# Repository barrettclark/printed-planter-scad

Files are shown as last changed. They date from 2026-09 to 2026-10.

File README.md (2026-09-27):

# Parametric Planter Generator

## What This Is

This is a parametric OpenSCAD model that generates a decorative outer planter body/shell fitted around a plastic insert (pot, container, or vessel) you already have. You provide measurements of your insert and the generator creates a body that holds it securely, with optional decorative patterns. All dimensions are parametric—adjust them to fit any insert size, wall thickness, or decoration style.

## Requirements

- **OpenSCAD 2021.01 or later** — required by the vendored BOSL2 library (which hard-asserts this minimum version), the Customizer feature, and procedural language features used here.
- **BOSL2 library** — vendored in `lib/BOSL2/`, no separate installation needed.
- **Customizer panel recommended** — the easiest way to adjust parameters. Enable it with **View → Show Customizer** in OpenSCAD.

Command-line users can override any parameter without the Customizer by using the `-D` flag, for example:
```bash
openscad -D 'insert_top_d=160' -D 'pattern_type="hex_grid"' -o exports/planter.stl planter.scad
```

An `exports/` directory is included for rendered output (STL, 3MF, PNG, etc.) — `.gitignore` already excludes those file types repo-wide, so anything you save there stays local and won't get committed. (The one carve-out is `docs/images/`, whose PNGs are documentation rather than disposable output — regenerate them with `docs/images/render.sh`.)

## Measuring Your Insert

Before measuring, check whether your insert is close to one of the 3 named sizes in `insert_preset` (see the Insert Dimensions table below) — if so, just pick that preset and skip measuring entirely.

Otherwise, to generate a planter for a different insert, measure these three dimensions:

- **`insert_top_d`** — the widest point of your insert (the rim or top diameter), in millimeters.
- **`insert_bottom_d`** — the bottom diameter of your insert, in millimeters.
- **`insert_height`** — the vertical height of your insert, in millimeters.

With `insert_preset` left at `"custom"`, these three measurements are the **only parameters you need to change** to reprint the planter for a different insert. The generator will automatically adjust the cavity (internal pocket) to fit your insert's tapered shape. All other parameters control fit clearance, wall thickness, decoration, and base options—leave them at their defaults unless you need to customize further.

## Parameter Reference

All parameters below can be adjusted in the Customizer panel or via command-line `-D` overrides.

### Insert Dimensions

| Parameter | Description | Default |
|---|---|---|
| `insert_preset` | Named insert size: `"custom"` (use the three fields below) or `"small"`, `"medium"`, `"large"` | `"custom"` |
| `insert_top_d` | Top rim diameter (mm) — used when `insert_preset == "custom"` | 150 |
| `insert_bottom_d` | Bottom diameter (mm) — used when `insert_preset == "custom"` | 110 |
| `insert_height` | Insert height (mm) — used when `insert_preset == "custom"` | 130 |

The 3 named presets:

| `insert_preset` | `insert_top_d` | `insert_bottom_d` | `insert_height` |
|---|---|---|---|
| `"small"` | 100 | 75 | 85 |
| `"medium"` | 130 | 100 | 120 |
| `"large"` | 180 | 125 | 160 |

### Fit

| Parameter | Description | Default |
|---|---|---|
| `ledge_engagement_height` | Depth of the rim's tight-fit seat (mm) | 8 |
| `ledge_ramp_height` | Height over which the seat narrows to its tight clearance, instead of as a hard step (mm); `0` reproduces the old hard step | 2 |
| `fit_clearance` | Radial clearance at the rim seat (mm) | 0.3 |
| `body_clearance` | Radial clearance around the tapered insert body (mm) | 3 |
| `bottom_margin` | Air gap below the insert's bottom (mm) | 5 |

### Outer Shape

| Parameter | Description | Default |
|---|---|---|
| `outer_mode` | Shape mode: `"follow"` (auto-wrap around insert) or `"custom"` (fixed geometry) | `"follow"` |
| `wall_thickness` | Wall thickness in `"follow"` mode (mm) | 3 |
| `outer_top_d` | Outer top diameter in `"custom"` mode (mm) | 172 |
| `outer_bottom_d` | Outer bottom diameter in `"custom"` mode (mm) | 130 |
| `outer_height` | Planter height in `"custom"` mode (mm) | 145 |

### Decoration

| Parameter | Description | Default |
|---|---|---|
| `pattern_type` | Decoration style: `"none"`, `"ridges"`, or a geometric tile pattern — `"diamonds"`, `"hex_grid"`, `"pyramids"`, `"bricks"`, `"checkers"`, `"dots"`, `"cubes"`, `"tri_grid"`, `"teardrop"`, `"tumbling_cubes"`, `"intertwine"`, `"islamic_star"`, `"tetrakis_square"`, `"kisrhombille"`, `"triakis_triangular"`, `"rhombille"`, `"cairo_pentagonal"`, `"floret_pentagonal"`, `"deltoidal_trihexagonal"` | `"ridges"` |
| `pattern_orientation` | Direction: `"vertical"` or `"horizontal"` | `"vertical"` |
| `relief_mode` | Relief type: `"raised"` (pattern stands proud of the wall) or `"etched"` (pattern is cut into the wall) | `"raised"` |
| `pattern_depth` | Depth of pattern relief (mm) | 1.5 |
| `pattern_repeat` | Number of pattern tiles around the circumference; the vertical repeat count is derived automatically from the pot's geometry so tiles come out approximately square (see "Decoration" below) | 16 |

### Base

| Parameter | Description | Default |
|---|---|---|
| `floor_thickness` | Thickness of the planter's solid floor (mm) | 3 |
| `drainage_holes_enabled` | Enable drainage holes in the floor | `false` |
| `drainage_hole_count` | Number of drainage holes | 6 |
| `drainage_hole_diameter` | Diameter of each drainage hole (mm) | 4 |

In `"custom"` outer mode, the actual floor thickness is `floor_thickness + (outer_height - pot_height)`, not just `floor_thickness` — the cavity is shifted up to sit flush with the custom outer shape's top, so any extra height in `outer_height` beyond the required cavity height becomes additional solid floor.

### Quality

| Parameter | Description | Default |
|---|---|---|
| `smoothness` | Mesh resolution for all revolved geometry (OpenSCAD `$fn`) | 60 |

## Reference Settings: This Project's Insert

The planter was designed around this insert. Use these settings to reproduce the exact geometry from this project:

```scad
insert_preset = "custom";
insert_top_d = 150;
insert_bottom_d = 110;
insert_height = 130;
ledge_engagement_height = 8;
ledge_ramp_height = 2;
fit_clearance = 0.3;
body_clearance = 3;
bottom_margin = 5;
outer_mode = "follow";
wall_thickness = 3;
pattern_type = "ridges";
pattern_orientation = "vertical";
relief_mode = "raised";
pattern_depth = 1.5;
pattern_repeat = 16;
floor_thickness = 3;
drainage_holes_enabled = false;
```

## Decoration Examples

**See the [pattern gallery](docs/gallery.md) for a rendered example of every `pattern_type` in `"raised"` and `"etched"` mode, plus `"alternating"` for the eight patterns that support it** (except `"none"`, which has no texture, so it only has one useful mode), plus full-pot renders, the three insert presets and both outer shape modes. The rest of this section covers the behaviour the pictures can't show.

`"etched"` works one of two ways depending on the pattern. `"ridges"`, `"pyramids"` and `"diamonds"` have a flat-topped counterpart shape, so etching them is a true line engrave: the wall keeps its nominal surface as flat panels, and only a thin V-groove is cut along each of the pattern's outlines. `"hex_grid"` and `"tri_grid"` work the same way, just shifting the same panel/groove relief inward rather than swapping to a separate counterpart shape.

- `"ridges"` — a smooth wall scored with thin vertical (or horizontal) lines.
- `"pyramids"` — flat square panels divided by a thin engraved grid.
- `"diamonds"` — flat diamond panels divided by thin 45° engraved lines.

Eight patterns — `"tumbling_cubes"`, `"islamic_star"`, `"tetrakis_square"`, `"kisrhombille"`, `"triakis_triangular"`, `"rhombille"`, `"cairo_pentagonal"` and `"floret_pentagonal"` — use a different, uniform mechanism: a flat wall cut by a real two-tier engraved groove. A primary groove traces each motif's own outer silhouette (where it meets a *different* motif instance — e.g. the line between two adjacent Cairo pentagons, or between `"islamic_star"`'s star and a neighbouring cross); a thinner, shallower secondary groove marks internal facet structure within one motif, where a pattern has any (the "kis" family's fan triangles, `"floret_pentagonal"`'s rosette blades, `"tumbling_cubes"`'/`"rhombille"`'s per-rhombus seams, `"cairo_pentagonal"`'s per-hub pinwheel seams). A pattern whose motif has no internal sub-structure of its own within one tile (`"tetrakis_square"`'s single fan spans the whole unit tile, with no second motif instance inside it to have an outer boundary against) legitimately shows only the secondary tier, or only the primary tier — whichever tier has nothing to groove is simply absent, not a bug. See the [gallery](docs/gallery.md#pattern-comparison) for what each looks like.

`"none"` has no texture at all, so it only has one useful mode. `"teardrop"` and `"intertwine"` keep their own pre-existing etched behaviour — a whole-silhouette groove around each's own single pre-built island, predating and unaffected by the two-tier redesign above — see the note on those two patterns below. `"dots"`, `"cubes"`, `"checkers"` and `"bricks"` still sink the raised bump into a dimple, unchanged; converting them to the two-tier groove mechanism above is a deferred future project (see `TODO.md`).

`"alternating"` (new) is a third relief style: within one tile, some copies of a motif sit proud of the nominal wall surface and others sit sunk below it, in a single render — true bas-relief, not a raised or etched pass unioned with its own inverse. It's available for the same eight patterns as the two-tier etched groove above; every other `pattern_type` fails loudly with a clear message (`relief_mode "alternating" is only supported for pattern_type in ...`) rather than falling back to `"raised"` if you select it.

Eight of the `pattern_type` values — `"teardrop"`, `"tumbling_cubes"`, `"intertwine"`, `"islamic_star"`, `"rhombille"`, `"cairo_pentagonal"`, `"floret_pentagonal"` and `"deltoidal_trihexagonal"` — are *interlocking* patterns: their motifs deliberately cross the tile boundary so that adjacent repeats join into one continuous design rather than sitting in visible boxes. The [gallery](docs/gallery.md#pattern-comparison) shows what each one looks like; the notes below cover their rendering quirks.

Note on `"teardrop"` and `"intertwine"`: their `"etched"` behaviour predates the relief-mode redesign above and is unaffected by it — both tiles cross the tile boundary in a way that leaves a decorated body with scalloped rather than circular end caps. The planter itself renders fine, but OpenSCAD 2021.01 aborts with a CGAL assertion if you `union()` such a solid with another *textured* solid. Render these pots on their own, or combine them with plain (untextured) geometry — keep a `"teardrop"` or `"intertwine"` solid as the only textured solid per render when forcing CGAL evaluation. `"tumbling_cubes"` and `"islamic_star"` cross their tile edges too but still union cleanly with another textured solid in `"raised"` mode at CI's own pinned configuration (union with a `"dots"` solid, differenced against a disjoint cube, `pattern_repeat=9`) — both re-measured clean, which is why they stay in CI's union loop. That result is specific to `"raised"` and to those heights, though, and does not generalise: what actually decides it is whether neighbouring plateaus sit at *different* heights. `"tumbling_cubes"` passes on the strength of its three distinct `_TC_Z` values — merely permuting them to `[0.62, 1.0, 0.30]` aborts the union — and any configuration that flattens neighbouring plateaus to one uniform height aborts at every `pattern_repeat` and `smoothness` tried (8, 11 and 12 at `$fn` 4 and 8): that covers `"rhombille"` in `"raised"` mode and *both* patterns in `"alternating"` mode. It is the union operation itself, not proximity — two copies 1000 units apart abort just the same, while each solid alone is a clean 2-volume manifold — and a three-way union of one pattern's own three relief modes aborts for `"islamic_star"` too. So: keep any `"alternating"` solid, and any `"rhombille"` solid, the only textured solid per render, and don't put all three relief modes of one pattern in a single file. `"rhombille"` was already flagged here from a single `pattern_repeat=16` `"raised"` measurement; the above is the fuller characterization that note asked for. `"cairo_pentagonal"` behaves the same way: it CGAL-aborted that same union check (union with a `"dots"` solid, differenced against a disjoint cube) at `pattern_repeat=9` in `"raised"` mode locally, so it is *not* in CI's union loop and gets the same advice — one textured solid per render. `"floret_pentagonal"` is the same: that union check CGAL-aborted locally at `pattern_repeat=26` in `"raised"` mode (a value that renders perfectly cleanly on its own at the same geometry), so it is not in CI's union loop either — keep it the only textured solid per render. `"deltoidal_trihexagonal"` unions cleanly, like `"tumbling_cubes"`/`"islamic_star"`: verified directly (union with a `"dots"` solid, differenced against a disjoint cube) at both `pattern_repeat=9` and `pattern_repeat=12` in `"raised"` mode, so it is in CI's union loop alongside them.

Note on the interlocking patterns and CGAL: `"tumbling_cubes"`, `"intertwine"`, `"islamic_star"`, `"rhombille"`, `"cairo_pentagonal"` and `"floret_pentagonal"` build their motifs from flat plateaus, and BOSL2 lays a single *flat* facet across each one. When a plateau spans a wide arc, that flat facet is a chord that cuts back inside the wall. OpenSCAD 2021.01's CGAL then aborts the cavity subtraction with an assertion or reports an unclosed mesh.

Which parameter values trip this depends on `pattern_repeat` **and** `smoothness` *jointly*, and is not predictable from either one alone — and it moves whenever the underlying tile geometry changes: deriving the vertical tile count from real geometry instead of reusing `pattern_repeat` for both axes (so tiles come out roughly square) shifted every fragile threshold below. It is not a low-`pattern_repeat` problem and not a simple threshold in either parameter, and — this is the part worth stating explicitly, because it is easy to assume otherwise — "clean" for one relief mode does not imply clean for the other: measured on the default pot at `smoothness=24`, `"tumbling_cubes"` aborts (in `"raised"`, at least) at every `pattern_repeat` from 3 through 8 and again at 11; of the values that are clean in `"raised"` (9, 10, 12), `pattern_repeat=12` aborts in `"etched"`, leaving only 9 and 10 clean in **both** relief modes, so CI uses the smaller of those, 9. `"islamic_star"` aborts in at least one relief mode at 3, 4, 5, 7, 11 and 12; of the remaining values, 6 and 9 are clean only in `"raised"` (both abort in `"etched"`) and 7 is clean only in `"etched"` — 8 and 10 are the only values clean in **both** modes, so CI uses the smaller, 8. `"intertwine"` aborts in both relief modes at 4 and 6; of the remaining values, 7 is clean only in `"raised"` (it aborts in `"etched"`) — 3, 5, 8, 12 and 15 are all clean in **both** modes on a local macOS OpenSCAD build. CI uses 12, not the smallest (3): 3 passed locally but CGAL-aborted on GitHub Actions' Ubuntu build, both reporting the same OpenSCAD 2021.01 — the CGAL floating-point sensitivity behind this whole fragility problem varies by platform too, not just by `pattern_repeat`/`smoothness`. 12 was chosen with a tested margin on both sides (10 aborts in `"etched"`; 15 is also clean in both modes) rather than repeating the mistake of picking the next-smallest untested value. If `"intertwine"`'s CI check ever fails again, re-measure directly against a CI run — a local-only "clean" is necessary but not sufficient for this pattern. Held at the shipped `pattern_repeat=16` instead, `"tumbling_cubes"` is clean at `smoothness` 24, 40 and 60 but aborts at 80 and 100 in both relief modes — this is what pushed the shipped `smoothness` default down from 80 to 60. `"islamic_star"` at `pattern_repeat=16`, by contrast, is now clean across every `smoothness` value tested (24, 40, 60, 80, 100) in both relief modes — the joint dependency is real, but it doesn't hit every pattern at every `pattern_repeat`. The shipped defaults (`pattern_repeat=16`, `smoothness=60`) are clean for all six in both relief modes, so the out-of-the-box experience is fine. CI pins this for `"islamic_star"`, `"tumbling_cubes"`, `"rhombille"`, `"cairo_pentagonal"` and `"floret_pentagonal"`; `"intertwine"` at the defaults is verified manually rather than in CI, since it takes roughly 2-3 minutes per relief mode there (see below) — re-verify it by hand if its tile construction ever changes.

`"alternating"` mode had zero real-assembly CGAL coverage at all until this task, for any pattern — CI's assembly loops only ever iterated `raised`/`etched`. A real sweep found `"islamic_star"` clean at every `pattern_repeat` 3 through 16 (`smoothness=24`); `"tumbling_cubes"` aborts at `pattern_repeat` 3, 4 and 5 and is clean at 6 through 16. CI uses the reduced value 8 for `"islamic_star"` (any value in its all-clean range would do, so it reuses the same value already pinned for `raised`/`etched`) and 9 for `"tumbling_cubes"` (reused for the same reason — it's clean in `"alternating"` too, and sits well inside the 6–16 clean run). Held at the shipped `pattern_repeat=16`, both are clean at every `smoothness` tested (24, 40, 60, 80, 100) in `"alternating"` — notably including `"tumbling_cubes"` at 80 and 100, which is where it aborts in `raised`/`etched`; `"alternating"`'s own island geometry is different enough that this particular fragility doesn't carry over. CI pins the shipped defaults for both in `"alternating"` too. Measured locally (macOS OpenSCAD 2021.01) only, not yet re-verified against GitHub Actions' Ubuntu build.

`"rhombille"` reuses `"tumbling_cubes"`'s own hexagon/rhombus geometry directly (the same large flat plateaus, just one uniform height instead of three), and measured the same class of fragility: at `smoothness=24` on the default pot, it aborts in at least one relief mode at `pattern_repeat` 4, 6, 8, 9 (etched only), 11 and 14 (raised only); of the remaining values, 5 is clean only in `"raised"` (it aborts in `"etched"`) — 7, 10, 12, 13 and 15 are all clean in **both** modes locally. CI does **not** use the smallest of those, 7: 7 is an isolated clean value sandwiched directly between two full-abort values (6 and 8) on both sides, exactly the kind of narrow, untested-margin value the `"intertwine"` note above warns against trusting without a real CI run behind it. CI uses 13 instead — clean on both sides among the tested values (12 clean in both modes, 14 only failing in `"raised"`). Unlike `"intertwine"`'s value, this one has been re-verified against GitHub Actions' Ubuntu build, not just measured locally: run [35477972837](https://github.com/barrettclark/printed-planter-scad/actions/runs/35477972837) rendered `pattern_repeat=13`/`smoothness=24` clean (a 2-volume STL, no `CGAL error`) in both relief modes, under the workflow's `CGAL error` check. Held at the shipped `pattern_repeat=16`, `"rhombille"` is clean at `smoothness` 24 and 60 in both relief modes (higher `smoothness` values were not tested) — that combination was also confirmed against the same Ubuntu run; it was also clean locally at `pattern_repeat=32` and `smoothness` 24/60 in both relief modes.

`"rhombille"`'s `"alternating"` mode shares `"tumbling_cubes"`'s exact fragility footprint (unsurprising, since they share the same island construction): aborts at `pattern_repeat` 3, 4 and 5, clean at 6 through 16 (`smoothness=24`). CI uses 13, reused from the `raised`/`etched` pin above since it's clean in `"alternating"` too. Held at the shipped `pattern_repeat=16`, `"alternating"` is clean at every `smoothness` tested (24, 40, 60, 80, 100) — CI pins the shipped defaults for it as well. Measured locally only, not yet re-verified against GitHub Actions' Ubuntu build.

`"cairo_pentagonal"` (the Cairo pentagonal tiling — eight flat pentagon plateaus per unit tile) measured the same class of fragility, so it carries the same known-to-abort warning rather than the "kis" family's precautionary one. At `smoothness=24` on the default pot it aborts in **both** relief modes at `pattern_repeat` 3, 5, 10 and 11, and in `"etched"` only at 4 (4 is clean in `"raised"`); 6, 7, 8, 9, 12, 13, 14, 15 and 16 are all clean in **both** modes, as are 24 and 32. CI uses 8 — deliberately not an isolated clean value: it sits in the middle of a four-wide run (6, 7, 8, 9) measured clean in both relief modes, so it has a tested margin on each side, which is exactly what `"intertwine"`'s 3 and `"rhombille"`'s 7 lacked. The `smoothness` axis was swept too, held at the shipped `pattern_repeat=16`: clean in both relief modes at `smoothness` 24, 40, 60 and 80, and aborting at `smoothness=100` in `"etched"` only (`"raised"` is clean there) — the shipped `smoothness=60` default therefore has two tested-clean steps of headroom above it. Unlike `"rhombille"`'s values, none of this has been re-verified against GitHub Actions' Ubuntu build yet: every measurement above is from a local macOS OpenSCAD 2021.01 build, which the `"intertwine"` note above shows is necessary but not sufficient. If CI's `"cairo_pentagonal 8"` or defaults check ever fails, re-measure against the CI run and pick another value from the 6–9 or 12–16 clean runs rather than the next smallest.

`"cairo_pentagonal"`'s `"alternating"` mode has its own, different fragile-value set from `raised`/`etched`: aborts at `pattern_repeat` 3, 5 and 11, clean at 4, 6 through 10, and 12 through 16 (`smoothness=24`). CI reuses the same reduced value 8 pinned for `raised`/`etched` above, since it's clean in `"alternating"` too. Held at the shipped `pattern_repeat=16`, `"alternating"` is clean at every `smoothness` tested (24, 40, 60, 80, 100) — a wider margin than `raised`/`etched` show at this pattern_repeat, which abort at `smoothness=100` in `"etched"`. CI pins the shipped defaults for `"alternating"` too. Measured locally only, not yet re-verified against GitHub Actions' Ubuntu build.

`"floret_pentagonal"` (the floret pentagonal tiling — **eighteen** flat pentagon plateaus per unit tile, the most of any tile in this project) is the most CGAL-fragile pattern here, and carries the same known-to-abort warning. At `smoothness=24` on the default pot it aborts in **both** relief modes at `pattern_repeat` 3, 7, 8 and 12, and in `"etched"` only at 4, 10 and 13; 5, 6, 9, 11, 14, 15 and 16 are clean in **both** modes. CI uses 15 — the only value in that range with a tested-clean neighbour on each side in both modes (14 and 16); 5, 6, 9 and 11 are each adjacent to an abort on at least one side, so picking one of them would repeat the isolated-clean-value mistake `"intertwine"`'s 3 and `"rhombille"`'s 7 made. At `smoothness=60`, the shipped default: `"raised"` aborts at 3, 7, 8 and 12 and is clean at 4, 5, 6, 9, 10, 11, 13, 14, 15 and 16; `"etched"` aborts at 3, 4, 5, 7, 8, 11, 12 and 13 and is clean only at 6, 9, 10, 14, 15 and 16. So **the shipped defaults (`pattern_repeat=16`, `smoothness=60`) do measure clean in both relief modes** — but the margin below them is thinner than for any other pattern (14 and 15 are clean in both modes, 13 already aborts in `"etched"`). Above the shipped default, held at `pattern_repeat=16`: `smoothness=80` and `smoothness=100` are also clean in both relief modes, measured locally (not yet CI-verified) — two tested-clean steps of headroom above the default, one step better than `"cairo_pentagonal"`, which aborts at `smoothness=100` in `"etched"`. CI pins the defaults for it (see `.github/workflows/test.yml`) precisely because the margin below them is narrow. Everything above is from a local macOS OpenSCAD 2021.01 build and has **not** yet been re-verified against GitHub Actions' Ubuntu build — the `"intertwine"` note above is the standing reminder that local-clean is necessary but not sufficient. If CI's `"floret_pentagonal 15"` or its defaults check ever fails, re-measure against that CI run and pick another value from the clean runs rather than the next smallest. On a separate, narrower geometry (a bare `cyl(r1=75, r2=60, h=100, $fn=50)` with `tex_reps=[12,8]`, not the planter assembly) this pattern also aborts at `pattern_repeat` 12, 14, 15, 16, 20, 22 and 23 while 24–27 and 30–33 are clean — which is why `tests/test_decoration_floret_pentagonal.scad` renders at 26 rather than the 12 the other tile tests use.

`"floret_pentagonal"`'s `"alternating"` mode is, notably, the one exception to this pattern's own "thinnest margin of any pattern" reputation above: it measured CGAL-clean at every `pattern_repeat` 3 through 16 tested (`smoothness=24`), unlike its own `raised`/`etched` tiles at the same range. CI reuses the reduced value 15 pinned for `raised`/`etched` (any value in the all-clean range would do). Held at the shipped `pattern_repeat=16`, `"alternating"` is clean at every `smoothness` tested (24, 40, 60, 80, 100) — a wider margin than `raised`/`etched` show at this pattern_repeat, whose margin below the shipped defaults is otherwise the narrowest in this project. CI pins the shipped defaults for `"alternating"` too. Measured locally only, not yet re-verified against GitHub Actions' Ubuntu build.

`"triakis_triangular"` carries this same precautionary CGAL warning, since it's built from the same general class of small triangular facets, but it is not known to be fragile: every tested `pattern_repeat`/`smoothness`/relief-mode combination, including `"alternating"` (clean at every `pattern_repeat` 3 through 16 at `smoothness=24`, and at every `smoothness` 24/40/60/80/100 at the shipped `pattern_repeat=16`), the shipped defaults, and the reduced CI value (4, reused for `"alternating"` too), has measured CGAL-clean. Treat the warning on it as a "scan the console anyway, just in case" precaution rather than a known failure mode.

`"kisrhombille"` no longer belongs in that same safe bucket. Its `"raised"` and `"etched"` tiles remain CGAL-clean at every tested value, same as `"triakis_triangular"` — but its new `"alternating"` mode aborts the real assembly at `pattern_repeat` 4 and 7 (`smoothness=24`); 3, 5, 6 and 8 through 16 are clean. This is a genuinely mode-specific fragility, not a regression in the etched geometry the two patterns otherwise share. CI cannot reuse the `"kisrhombille" 4` reduced value already pinned for `raised`/`etched` here, since 4 is one of the two values that abort in `"alternating"` — it uses 10 instead, the middle of the widest clean run (8–16). Held at the shipped `pattern_repeat=16`, `"alternating"` is clean at every `smoothness` tested (24, 40, 60, 80, 100) — CI pins the shipped defaults for it too. Measured locally (macOS OpenSCAD 2021.01) only, not yet re-verified against GitHub Actions' Ubuntu build.

`"tetrakis_square"` no longer belongs in that safe bucket, even though it is nominally the same "kis"-family construction (a single kis-fanned unit tile). Its `"etched"` relief mode was rewired to a real two-tier outline-groove VNF (`_tile_outline_from_islands()`), and that rewire reintroduced the wide-arc-chord fragility the plateau patterns above have, but only in `"etched"` — `"raised"` and `"alternating"` measured clean at every `pattern_repeat` tested. At `smoothness=24` on the default pot, `"etched"` aborts at `pattern_repeat` 3, 4, 5, 7, 8, 9, 11, 12, 14 and 17; it is clean at 6, 10, 13, 15, 16 and every value from 18 through 24 tested. CI uses 20 — the middle of that 18–24 clean run, the widest margin found for any pattern in this project rather than an isolated clean value. `"alternating"` was swept over the same `pattern_repeat` 3–16 range (`smoothness=24`) and found clean everywhere — CI reuses the same reduced value 20 for it (re-verified directly at that value, since the etched sweep only covered up to 24 and didn't include 20 for `"alternating"` specifically). Held at the shipped `pattern_repeat=16`, `"tetrakis_square"` is clean at `smoothness=60` in all three relief modes, and `"alternating"` specifically was swept across every `smoothness` value tested (24, 40, 60, 80, 100), all clean (higher `smoothness` values were not tested for `raised`/`etched`). Both the reduced value and the shipped defaults are pinned in CI for `"alternating"` too. Everything above is from a local macOS OpenSCAD 2021.01 build and has **not** yet been re-verified against GitHub Actions' Ubuntu build — the `"intertwine"` note above is the standing reminder that local-clean is necessary but not sufficient; if either CI check ever fails, re-measure against the CI run rather than trusting the local sweep further.

`"deltoidal_trihexagonal"` (the deltoidal trihexagonal tiling — 14 kite plateaus per unit tile) joins that same mild bucket, despite being built from the same general class of large flat plateau construction as `"tumbling_cubes"`/`"rhombille"`/`"cairo_pentagonal"`/`"floret_pentagonal"` above, not the "kis" family's small-triangle-facet safety. A full sweep of the real assembly found **zero CGAL aborts anywhere tested**: every `pattern_repeat` from 3 through 16 at `smoothness=24`, and every `smoothness` in 24/40/60/80/100 at the shipped `pattern_repeat=16`, in **both** relief modes — 36 combinations, all clean. This is a genuinely different result from every other large-flat-plateau pattern in this project, all of which found at least one real abort somewhere in an equivalent sweep. CI pins both a reduced value (`pattern_repeat=4`, the same cheap low value the "kis" family uses — with every tested value clean, there is no "isolated clean value between two aborts" trap to avoid here) and the shipped defaults (`pattern_repeat=16`, `smoothness=60`). Everything above is from a local macOS OpenSCAD 2021.01 build and has **not** yet been re-verified against GitHub Actions' Ubuntu build — the `"intertwine"` note above is the standing reminder that local-clean is necessary but not sufficient; if either CI check ever fails, treat it as the authoritative re-measurement rather than assuming the local sweep still holds.

**Watch the console.** When this happens OpenSCAD still exits 0 and still writes an STL — a large, plausible-looking file from a subtraction that aborted part-way. The only signal is `CGAL error: assertion violation!` in the console log, with no error dialog in the GUI. If you see it, or if you get a broken/exploded render, nudge either `pattern_repeat` or `smoothness` by a small amount and render again.

`"intertwine"` is by far the most expensive of the seven to render: roughly 2-3 minutes and a ~25MB STL at the shipped defaults on a modern laptop, versus well under a minute for `"tumbling_cubes"`/`"islamic_star"`/`"rhombille"`/`"cairo_pentagonal"`/`"floret_pentagonal"`/`"deltoidal_trihexagonal"`. A silent console for a couple of minutes on `"intertwine"` is normal — it is not a hang, and it is not the CGAL failure above (which happens quickly, not after a minute or more).

Adjust `pattern_orientation` to switch between vertical and horizontal layouts, and `pattern_repeat` to set how many tiles wrap around the circumference. The vertical repeat count is no longer the same number: `decorated_solid()` derives it automatically (`_square_tile_vertical_reps()` in `modules/decoration.scad`) from the pot's actual height and circumference, so tiles come out approximately square regardless of `pattern_repeat` — raising `pattern_repeat` still multiplies the tiles horizontally, but the vertical count adjusts to match rather than tracking it 1:1.

Note: tiles are only *exactly* square at the pot's mean radius, since the decorated wall is a cone and BOSL2 scales each texture strip to the local radius (`lib/BOSL2/skin.scad`'s `_textured_revolution()`) while the vertical repeat count is fixed for the whole wall. At shipped defaults (`pattern_repeat=16`, bottom radius ~61mm, top radius ~82.3mm, 138mm wall height) this leaves a small residual: tiles run about **0.87× wide-to-tall at the bottom rim to 1.17× at the top rim** — not the ~2.8–3.75× distortion of the old `tex_reps = [pattern_repeat, pattern_repeat]` behavior. See [the gallery's full-pot section](docs/gallery.md#full-pot-examples) for side-by-side evidence.

Note: enabling decoration changes the pot's outer silhouette slightly. BOSL2's textured `cyl()` only supports a straight r1/r2 cone, so the decorated body is approximated as a straight cone through the cavity's peak radius rather than following the cavity's exact ledge/shoulder profile — at defaults this means the rim wall goes from ~3mm (plain `wall_thickness`) to ~7mm. This is a deliberate, documented tradeoff, not a bug.

## License

This project is licensed under the MIT License — see the [LICENSE](LICENSE) file included in this repository.

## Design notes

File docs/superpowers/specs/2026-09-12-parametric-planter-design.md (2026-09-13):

# Parametric Decorative Planter Pot — Design Spec

Date: 2026-09-12

## Purpose

Generate decorative outer "cachepot" shells (OpenSCAD, 3D-printable) sized to fit
commercial plastic planter inserts, configured entirely through parameters
instead of manually resizing published models. First target insert: a round,
tapered tray-style insert with drainage holes (150mm top diameter, 110mm bottom
diameter, 130mm tall, with a rim/flange at the top that the pot supports).

Project will be published to GitHub.

## Erratum (post-implementation)

This spec's Decoration section (below) originally scoped `pattern_type` to
three values: `none` / `ridges` / `geometric`, with `geometric` mapping to a
single BOSL2 texture. Once implemented, exposing BOSL2's actual texture
catalog directly (rather than bucketing it behind one generic name) turned
out to be more useful — `pattern_type` now accepts `none`, `ridges`, and
eight named geometric textures (`diamonds`, `hex_grid`, `pyramids`,
`bricks`, `checkers`, `dots`, `cubes`, `tri_grid`) instead of a single
`geometric` value. See `modules/decoration.scad`'s `PATTERN_TYPES` for the
authoritative current list. The text below is left as originally written
for historical accuracy.

## Insert & Fit Model

The insert has a flange/rim at the very top (the widest point, 150mm) and a
tapered body below it that must **not** contact the pot walls — only the rim
should bear load. The cavity is built as a revolved profile with two zones:

1. **Ledge zone** (top): radius = `insert_top_d/2 + fit_clearance`, depth =
   `ledge_engagement_height` (default ~8mm). This is the tight-tolerance step
   the insert's rim rests on.
2. **Clearance zone** (below ledge): radius steps outward by `body_clearance`
   (default ~3mm) beyond the insert's own taper at each height, running from
   the bottom of the ledge zone down to `insert_height - ledge_engagement_height
   + bottom_margin`. This guarantees the tapered insert body hangs free with no
   side contact, regardless of insert taper angle.
3. **Floor**: below the clearance zone, thickness `floor_thickness`. Style is
   configurable (see Base Styles).

The outer body (the visible decorative solid) is either:
- **Follow-insert mode** (default): outer profile mirrors the cavity profile,
  offset outward by `wall_thickness` at every height.
- **Custom mode**: outer profile independently defined by
  `outer_top_d`/`outer_bottom_d`/`outer_height`, decoupled from the insert
  taper. The cavity is still subtracted from this solid, so fit is guaranteed
  either way; `outer_*` dimensions must simply be large enough to contain the
  cavity plus `wall_thickness`, which is asserted at build time.

Outer cross-section is round only for this version (geometric decoration can
still create the visual impression of a faceted outer shape via
surface texture — see Decoration).

## Base Styles

Floor is always solid (thickness `floor_thickness`); drainage holes are a
checkbox on top of it:
- `drainage_holes` (boolean, default `false`) — when enabled, adds a
  configurable pattern of drainage holes (`drainage_hole_count`,
  `drainage_hole_diameter`) to the solid floor, for standalone use without the
  insert. When disabled, the floor has no holes and the pot acts as a plain
  cachepot/catch basin (insert provides all drainage).

## Decoration System

Applied via BOSL2's `texture()` mechanism on the revolved outer body surface,
after the outer profile is built and before the cavity is subtracted (so
decoration relief never eats into the wall thickness reserved for insert fit).

Independent parameters:
- `pattern_type`: `none` / `ridges` / `geometric` — `geometric` draws from
  BOSL2's built-in texture catalog (e.g. diamonds, hex tiles, pyramids) rather
  than hand-authored shapes.
- `pattern_orientation`: `vertical` / `horizontal` — texture tiling direction;
  primarily meaningful for `ridges`, and rotates tile-based `geometric`
  patterns 90°.
- `relief_mode`: `raised` / `etched` — same pattern, embossed outward or
  engraved inward.
- `pattern_depth`: relief height/depth in mm.
- `pattern_repeat`: tile count around the circumference (and vertically, for
  tileable patterns like `ridges`).

Build-time assertion: `pattern_depth < wall_thickness * 0.7` (warns/fails if
decoration would breach into the cavity).

## Dependencies

- **BOSL2**, vendored as a pinned copy under `lib/BOSL2/` and committed to the
  repo (not a live submodule), so the project has no external install step
  beyond cloning the repo. Chosen over hand-rolled geometry because its
  `texture()` system directly covers ridges/geometric-pattern/raised-etched
  requirements with far less custom code and better render quality.

## File Layout

```
printed-planter-scad/
  lib/BOSL2/              # vendored, pinned version, committed
  planter.scad            # main entry point — Customizer parameters + top-level calls
  modules/
    insert.scad           # cavity profile builder (ledge + clearance zone)
    body.scad             # outer body profile builder (follow-insert or custom mode)
    decoration.scad       # texture/pattern application
    base.scad             # floor styles: solid / solid+drainage / open
  README.md               # measuring your insert, BOSL2 note, Customizer usage, presets
  LICENSE
  .gitignore
```

`planter.scad` groups Customizer parameters into labeled sections
(`/* [Insert Dimensions] */`, `/* [Fit] */`, `/* [Outer Shape] */`,
`/* [Decoration] */`, `/* [Base] */`, `/* [Quality] */`) so the model is usable
directly from OpenSCAD's Customizer panel without editing code. Derived values
(radii, heights) are computed once from raw inputs near the top of the file.
Included modules receive all values as explicit arguments — no reliance on
global state — since OpenSCAD's Customizer only reads variables declared in
the top-level file.

## Validation

No unit-test framework exists for OpenSCAD; validation instead means:
- Assertions in `planter.scad`: `insert_bottom_d < insert_top_d`,
  `wall_thickness > 0`, `pattern_depth < wall_thickness * 0.7`, base-style
  parameter consistency.
- Known-good preset parameter sets documented in the README, including the
  real 150/110/130 insert dimensions, as a working reference to diff against.
- Manual render check post-implementation: render the default config and at
  least one decorated variant via the `openscad` CLI (if available on this
  machine) to confirm the model compiles and geometry is sane.

## GitHub

Repo will be initialized locally (`git init`, initial commit) as part of
implementation. Creating the actual GitHub remote and pushing is a separate,
explicit step requiring Barrett's confirmation before it happens (visible/
external action).

## Out of Scope (this iteration)

- Non-round outer cross-sections (square/hex outer body).
- Multiple simultaneous insert profiles/presets beyond documented examples.
- Automated visual regression testing of renders.

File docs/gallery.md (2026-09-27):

# Pattern Gallery

Every `pattern_type` this generator offers, plus the insert presets and outer
shape modes. Every pattern shows `"raised"` and `"etched"` except `"none"`,
which has no texture at all so `relief_mode` cannot change anything; the eight
patterns that support `"alternating"` (`tumbling_cubes`, `islamic_star`,
`tetrakis_square`, `kisrhombille`, `triakis_triangular`, `rhombille`,
`cairo_pentagonal`, `floret_pentagonal`) show it too. All
images are real OpenSCAD renders produced by
[`images/render.sh`](images/render.sh) — nothing here is drawn by hand or
touched up.

See [README.md](../README.md) for what each parameter means.

## Table of Contents

- [Pattern Comparison](#pattern-comparison)
  - [none](#none)
  - [ridges](#ridges)
  - [diamonds](#diamonds)
  - [hex_grid](#hex_grid)
  - [pyramids](#pyramids)
  - [bricks](#bricks)
  - [checkers](#checkers)
  - [dots](#dots)
  - [cubes](#cubes)
  - [tri_grid](#tri_grid)
  - [teardrop](#teardrop)
  - [tumbling_cubes](#tumbling_cubes)
  - [intertwine](#intertwine)
  - [islamic_star](#islamic_star)
  - [tetrakis_square](#tetrakis_square)
  - [kisrhombille](#kisrhombille)
  - [triakis_triangular](#triakis_triangular)
  - [rhombille](#rhombille)
  - [cairo_pentagonal](#cairo_pentagonal)
  - [floret_pentagonal](#floret_pentagonal)
  - [deltoidal_trihexagonal](#deltoidal_trihexagonal)
- [Full-Pot Examples](#full-pot-examples)
- [Insert Presets](#insert-presets)
- [Outer Shape Modes](#outer-shape-modes)
- [Regenerating These Images](#regenerating-these-images)

## Pattern Comparison

**These are square-tile close-ups, not pictures of a pot.** Each one is a
`decorated_solid()` cylinder whose height equals its own circumference, so
the vertical repeat count `_square_tile_vertical_reps()` derives comes out
equal to the horizontal one for 18 of the 21 patterns — the three sqrt(3)-
corrected patterns (`cubes`, `hex_grid`, `tri_grid`) instead render with a
vertical repeat count of 18, not 32, so their tiles are ~17.7mm wide by
~31.4mm tall rather than literally square. Every pattern is still shown at
its own designed proportions: for those three, a true isometric cube /
regular hexagon / equilateral triangle is not square to begin with, so
matching their designed proportions means being non-square on purpose. On
the actual planter, tiles are only *exactly* square at the
wall's mean radius — the wall is a cone, and the vertical repeat count is
fixed for the whole wall while BOSL2 scales each texture strip to the local
radius as it revolves. At shipped defaults this leaves a small residual: tiles
run **roughly 0.87× wide-to-tall at the bottom rim to 1.17× at the top rim**
— see [Full-Pot Examples](#full-pot-examples) below for what that residual
taper looks like, and why these close-ups (free of it) lead the page instead.

Settings shared by every image in this section: `r1 = r2 = 90mm`,
`height = 565.5mm` (= 2πr), `pattern_repeat = 32` (so tiles are ~17.7mm wide,
and square for 18 of the 21 patterns — see above for the three exceptions),
`pattern_depth = 1.5` and `smoothness = 60` (the shipped defaults),
`pattern_orientation = "vertical"`. Uniform across all of them, so the images
are comparable with each other.

Two rendering caveats worth knowing before you read the pictures:

- **The camera is ~25° off-axis** in both azimuth and elevation, not dead-on.
  OpenSCAD's light is mounted on the camera, so a straight-on shot hits every
  flat plateau at the same angle and the patterns built from flat islands
  (`tumbling_cubes`, `intertwine`, `islamic_star`, `rhombille`,
  `cairo_pentagonal`, `floret_pentagonal`, `deltoidal_trihexagonal`) wash out
  to almost nothing.
  25° rakes the light across the relief. It compresses both axes by about the
  same `cos(25°) = 0.91`, so tile aspect is essentially preserved.
- **The relief reads slightly deeper here than it will on a printed pot.** The
  depth is the real default (1.5mm), but these tiles are 17.7mm across where
  the default pot's tiles are ~24–32mm depending on height (the wall tapers,
  see below), so the depth-to-width ratio is 8.5% here versus roughly 4.6–
  6.3% on the pot.

### none

No texture at all — a plain wall. `relief_mode` has nothing to act on, so
there is only one image.

| Plain |
|---|
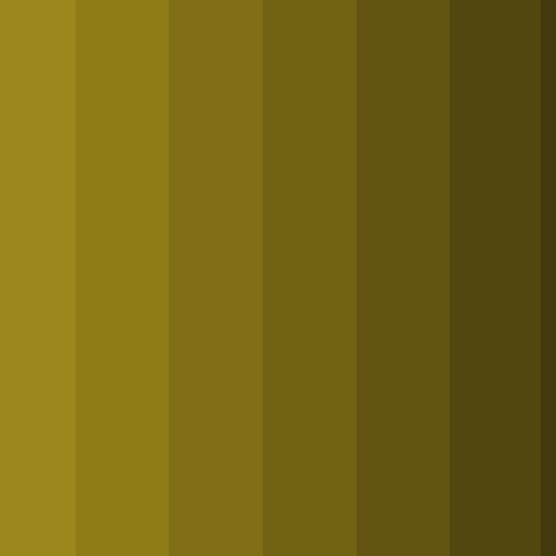
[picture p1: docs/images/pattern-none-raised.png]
none
|  |

The faint vertical banding is the `smoothness = 60` facets of the cylinder
itself, not a pattern.

### ridges

| Raised | Etched |
|---|---|
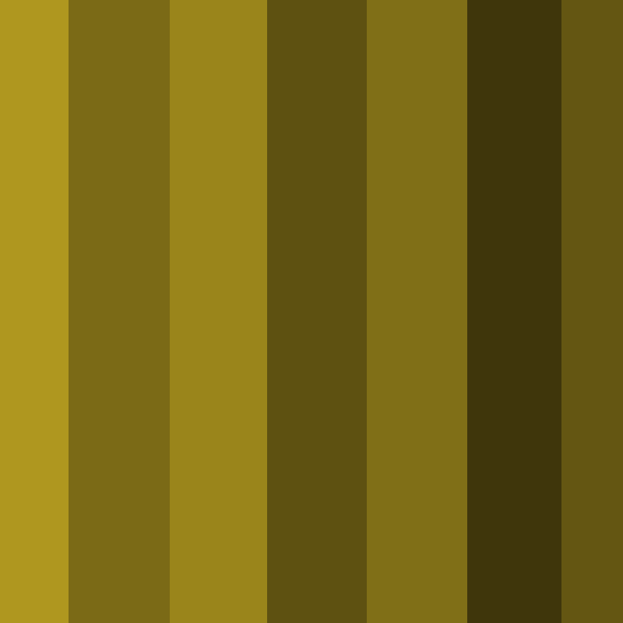
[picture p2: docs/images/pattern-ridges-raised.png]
ridges, raised
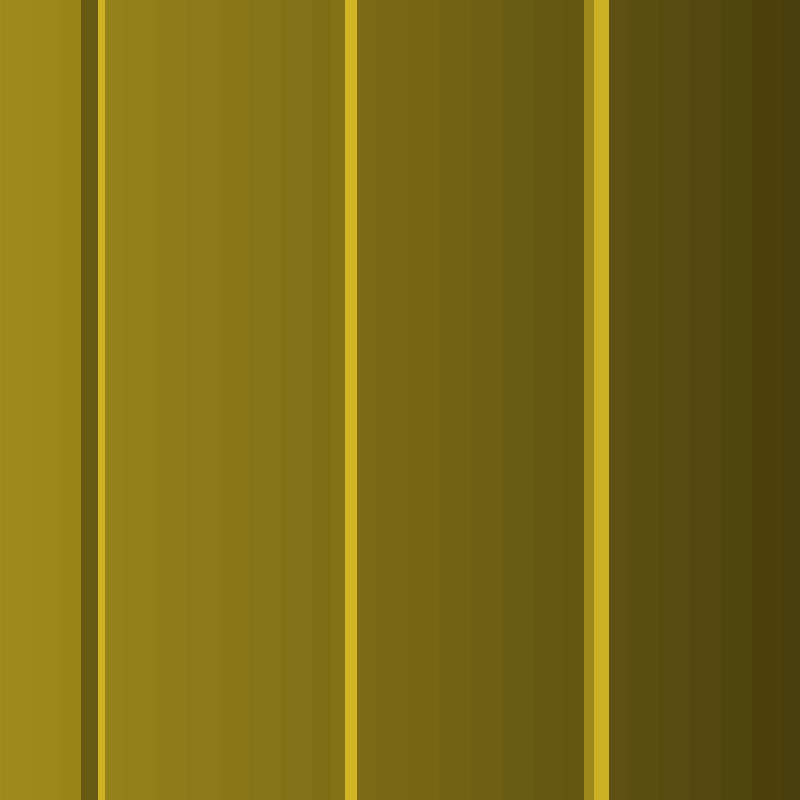
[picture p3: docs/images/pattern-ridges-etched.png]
ridges, etched
|  |  |

One of the three patterns with a true flat-topped counterpart: etched is a thin
V-groove incised into an otherwise flat wall, not an inverted bump.

### diamonds

| Raised | Etched |
|---|---|
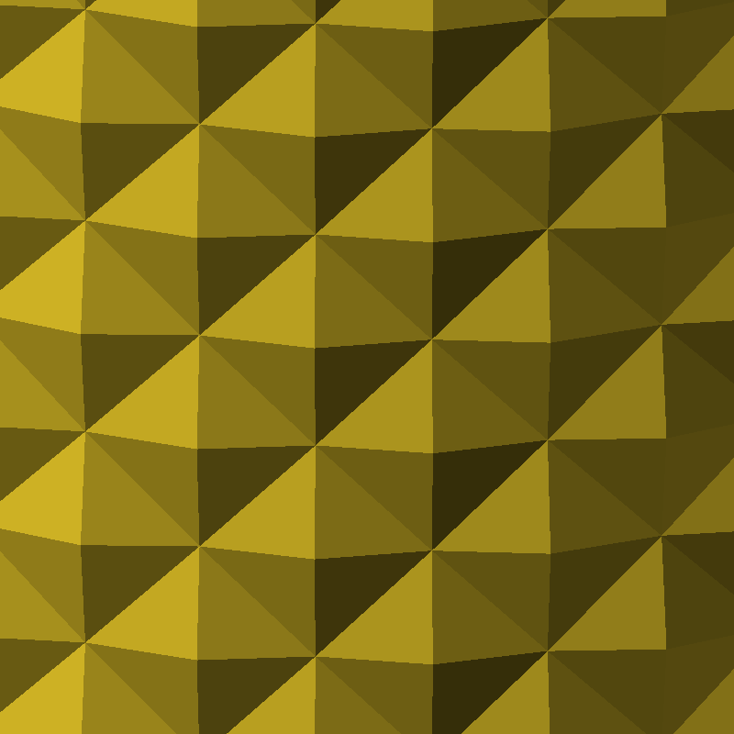
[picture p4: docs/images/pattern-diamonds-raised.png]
diamonds, raised
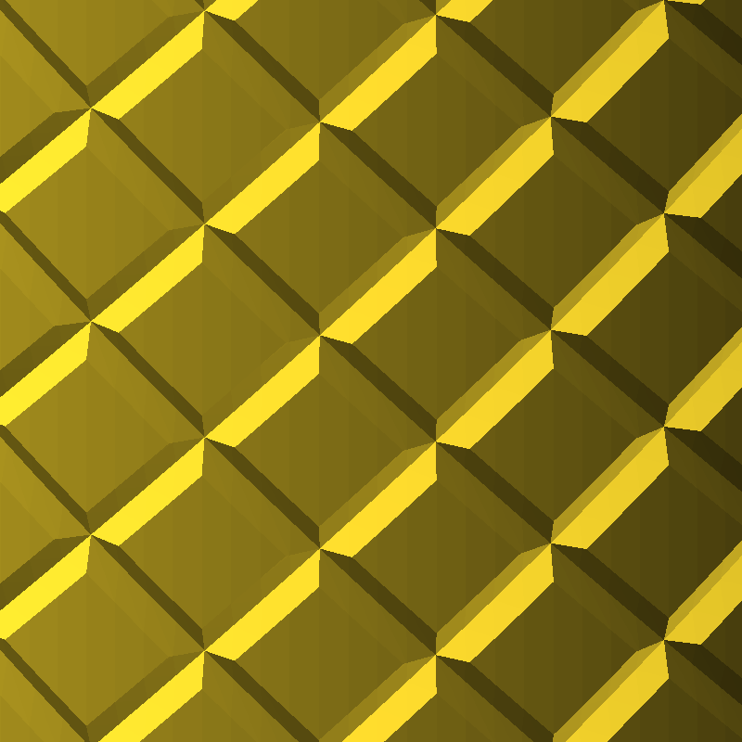
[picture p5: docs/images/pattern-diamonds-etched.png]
diamonds, etched
|  |  |

Also a true line engrave when etched: flat diamond panels divided by thin 45°
grooves.

### hex_grid

Flat hexagonal panels (raised) divided by V-groove borders (recessed) — a
honeycomb grid, same family as `diamonds` above. BOSL2's docs note the tile
needs a `sqrt(3)` vertical scale for the V-groove width to be uniform on all
six sides of each hexagon; `_square_tile_vertical_reps()` applies it by
folding the `sqrt(3)` factor into the vertical repeat count, so the hexagons
here render regular rather than stretched.

| Raised | Etched |
|---|---|
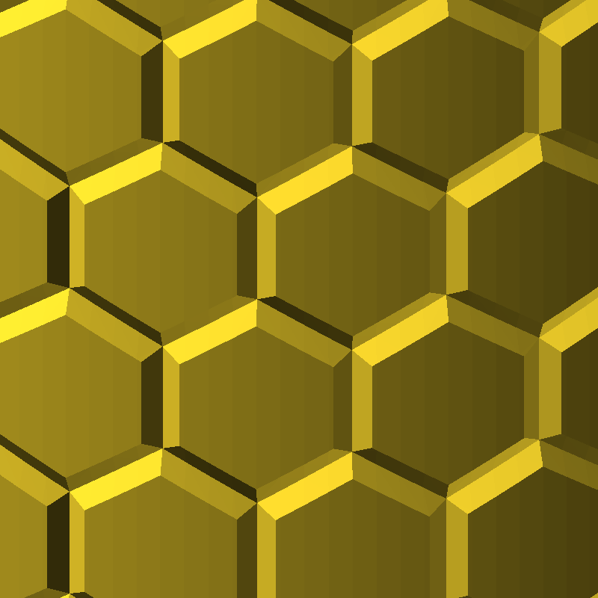
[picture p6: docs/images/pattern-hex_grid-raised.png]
hex_grid, raised
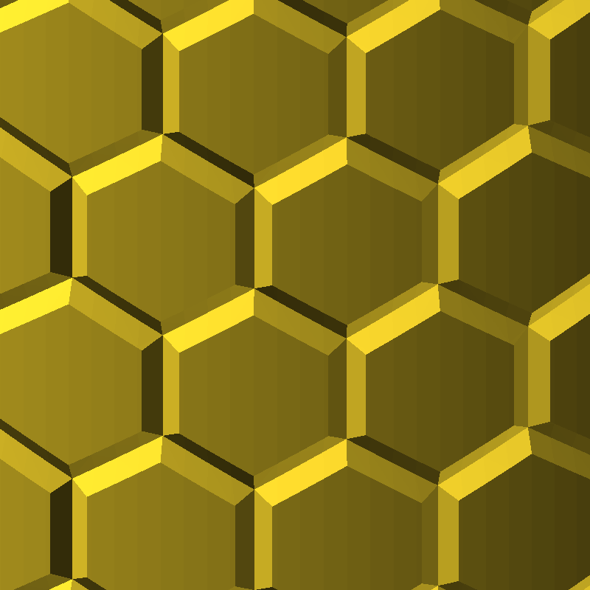
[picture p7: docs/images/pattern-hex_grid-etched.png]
hex_grid, etched
|  |  |

### pyramids

| Raised | Etched |
|---|---|
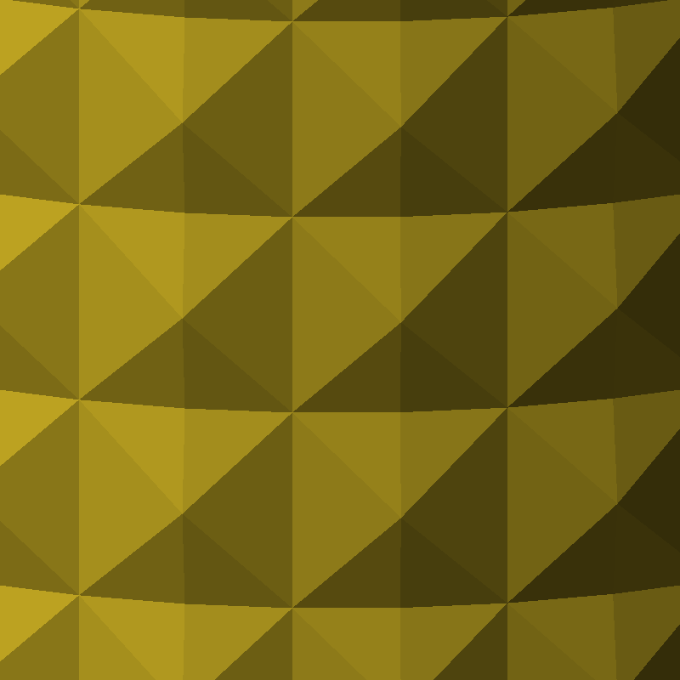
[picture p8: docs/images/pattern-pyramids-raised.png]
pyramids, raised
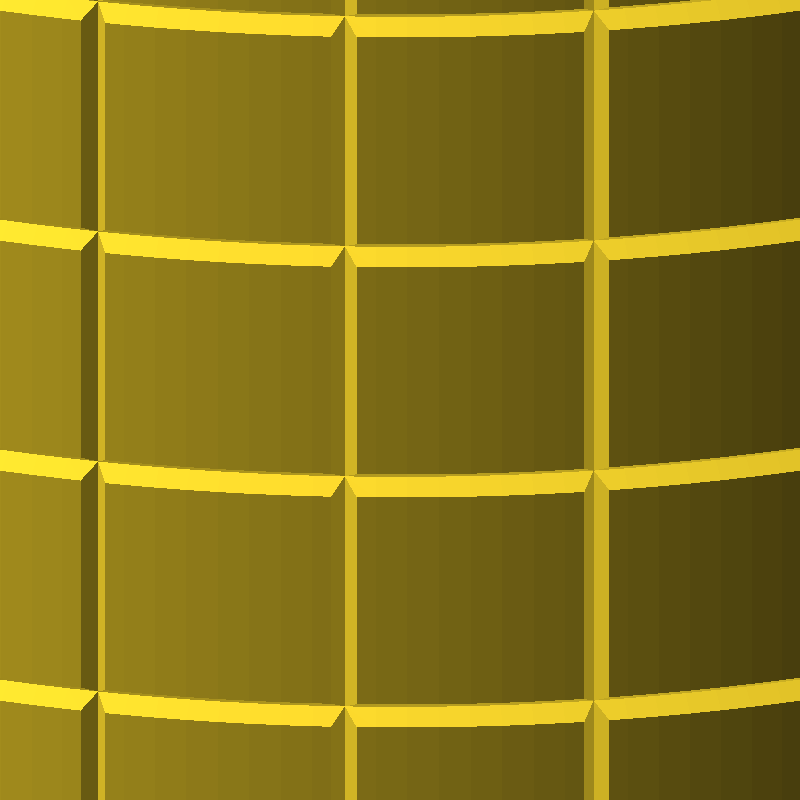
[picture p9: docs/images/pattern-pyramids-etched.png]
pyramids, etched
|  |  |

The third true line engrave: etched gives flat square panels separated by an
engraved grid, not flattened pyramids.

### bricks

| Raised | Etched |
|---|---|
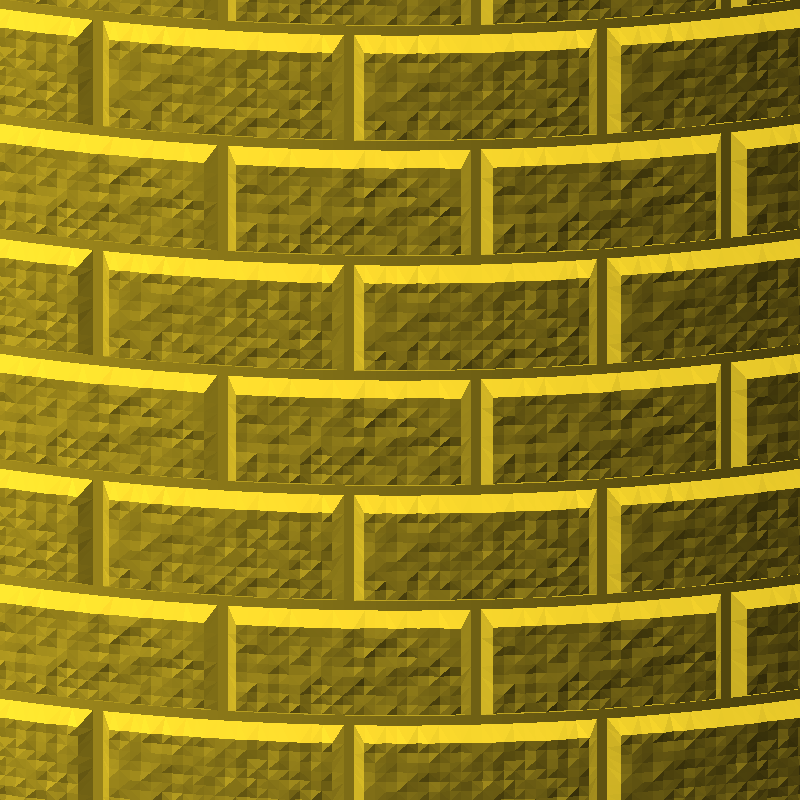
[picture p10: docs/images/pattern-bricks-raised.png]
bricks, raised
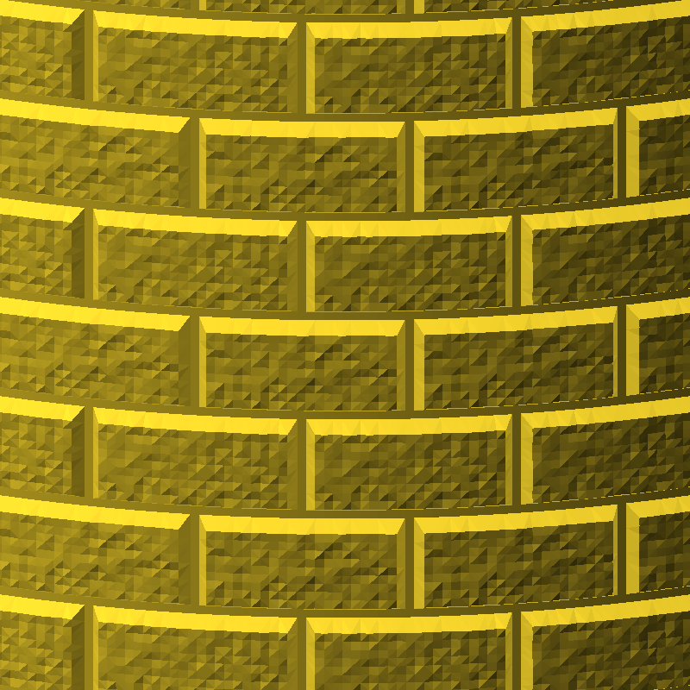
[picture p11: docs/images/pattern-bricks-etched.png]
bricks, etched
|  |  |

The speckle on each brick face is BOSL2's per-facet randomised roughness. It is
also why `bricks` is one of the slower patterns to render.

### checkers

A two-level checkerboard. `tex_inset=true` shifts the whole height profile
radially inward by exactly the pattern's depth rather than inverting it in
place, and on this curved wall that comes out visibly different from raised,
not just a relabeling of the same shape — an earlier draft of this page
claimed the two would render identically and was wrong; measured directly
(RMSE ≈ 0.12 between the two renders below) before writing this.

| Raised | Etched |
|---|---|
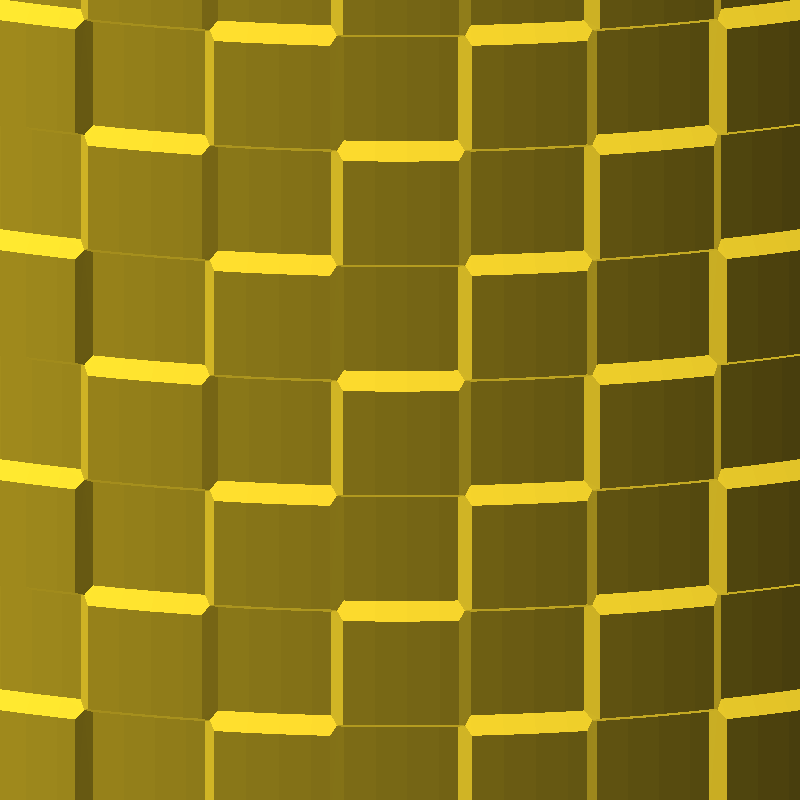
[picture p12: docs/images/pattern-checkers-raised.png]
checkers, raised
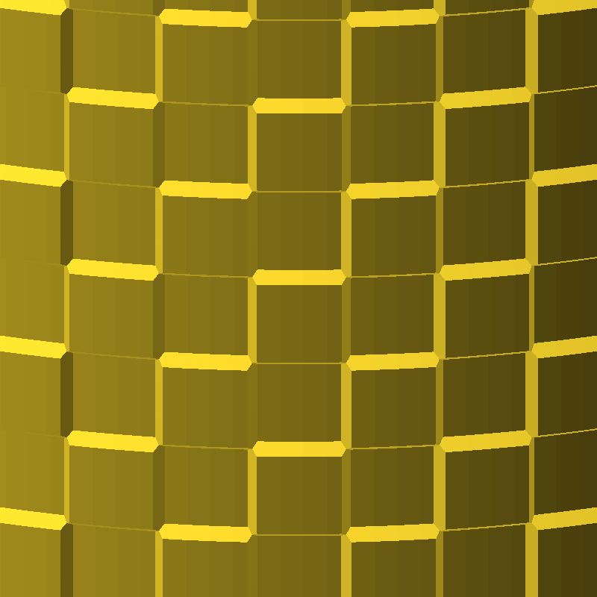
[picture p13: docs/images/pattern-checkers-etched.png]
checkers, etched
|  |  |

### dots

| Raised | Etched |
|---|---|
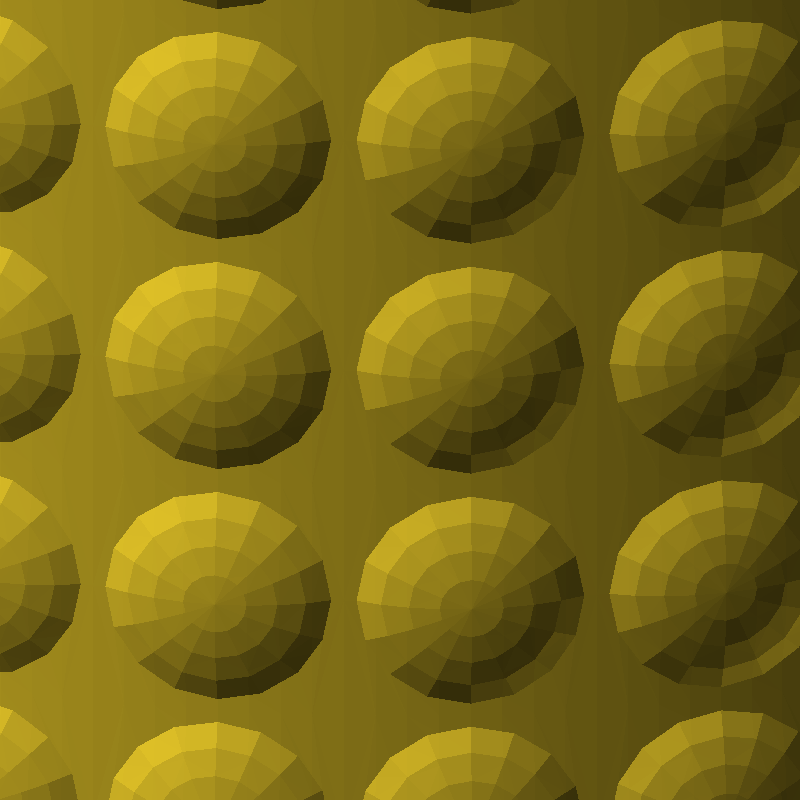
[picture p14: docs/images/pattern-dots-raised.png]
dots, raised
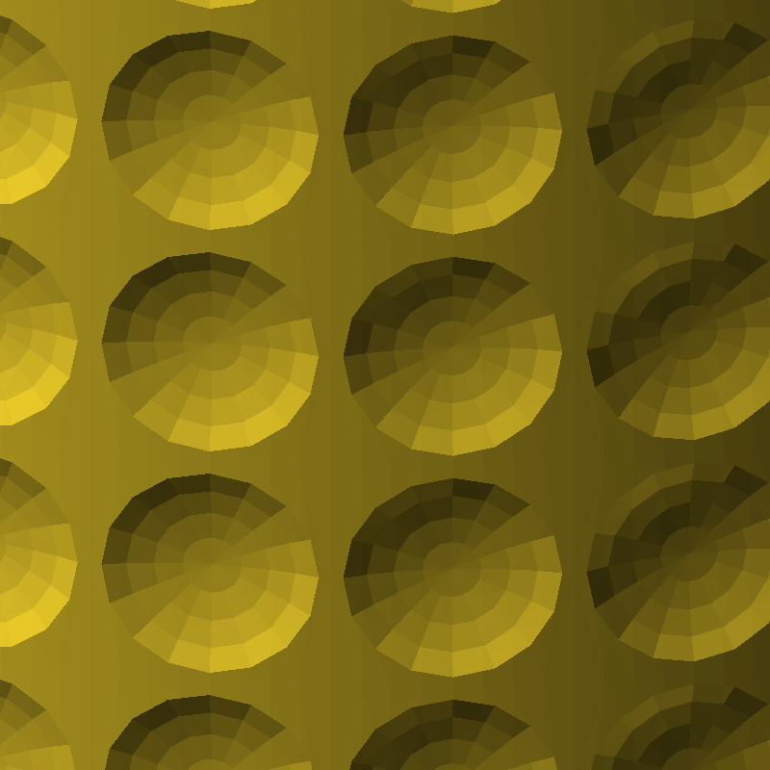
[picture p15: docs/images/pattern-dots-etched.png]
dots, etched
|  |  |

The clearest raised/etched pair on the page: genuine bumps versus genuine
dimples. `dots` is the one pattern that needs a negative `tex_depth` rather
than a plain inset to invert properly — without it the etched version would be
the same bump pushed below the surface.

### cubes

| Raised | Etched |
|---|---|
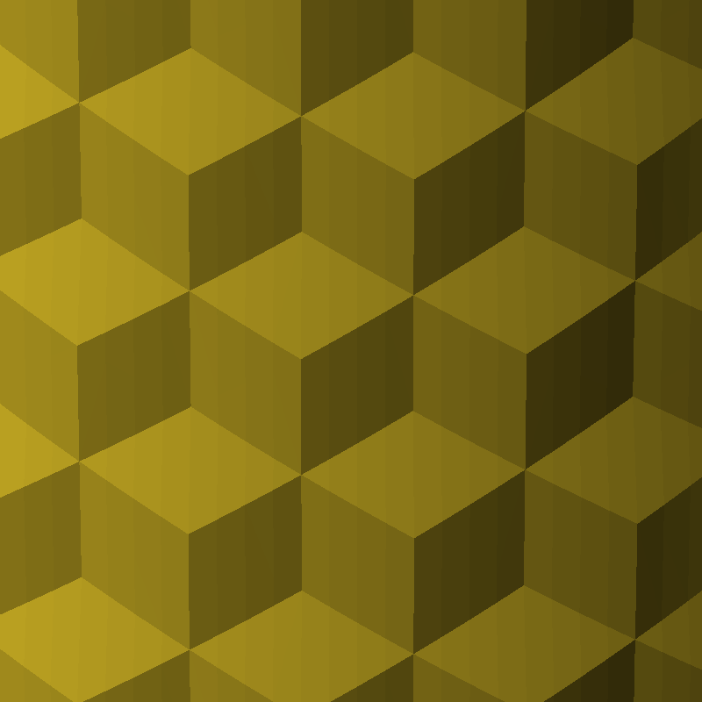
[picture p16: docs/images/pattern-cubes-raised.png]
cubes, raised
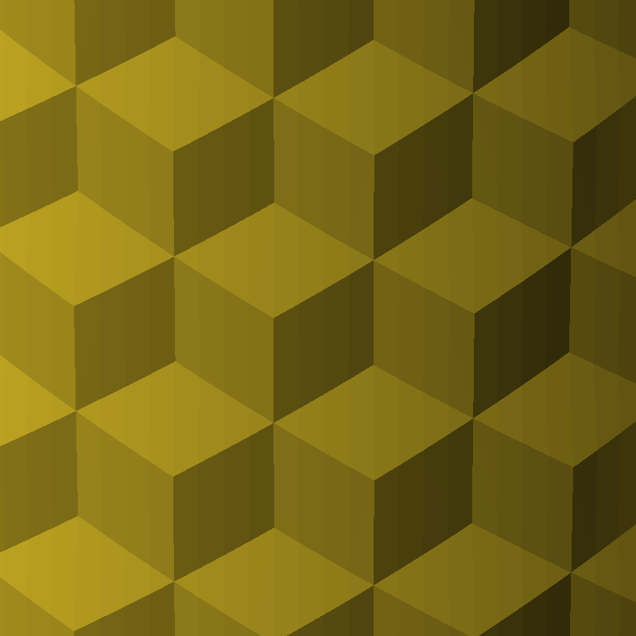
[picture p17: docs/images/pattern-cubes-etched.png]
cubes, etched
|  |  |

**Aspect note:** BOSL2's own docs for the `"cubes"` texture say it needs an
extra `sqrt(3)` vertical scale to render at its true isometric proportions
(`lib/BOSL2/skin.scad`, the "cubes" texture example). `_square_tile_vertical_reps()`
applies that correction by folding the `sqrt(3)` factor into the vertical
repeat count itself, so both the tile-squaring fix and this per-texture
correction come from the same formula.

### tri_grid

Flat triangular panels (raised) divided by V-groove borders (recessed) — the
same groove-bordered-panel family as `diamonds`/`hex_grid`, just on a
triangular grid instead of hexagonal. Same `sqrt(3)` correction as `hex_grid`
and `cubes` above, applied the same way.

| Raised | Etched |
|---|---|
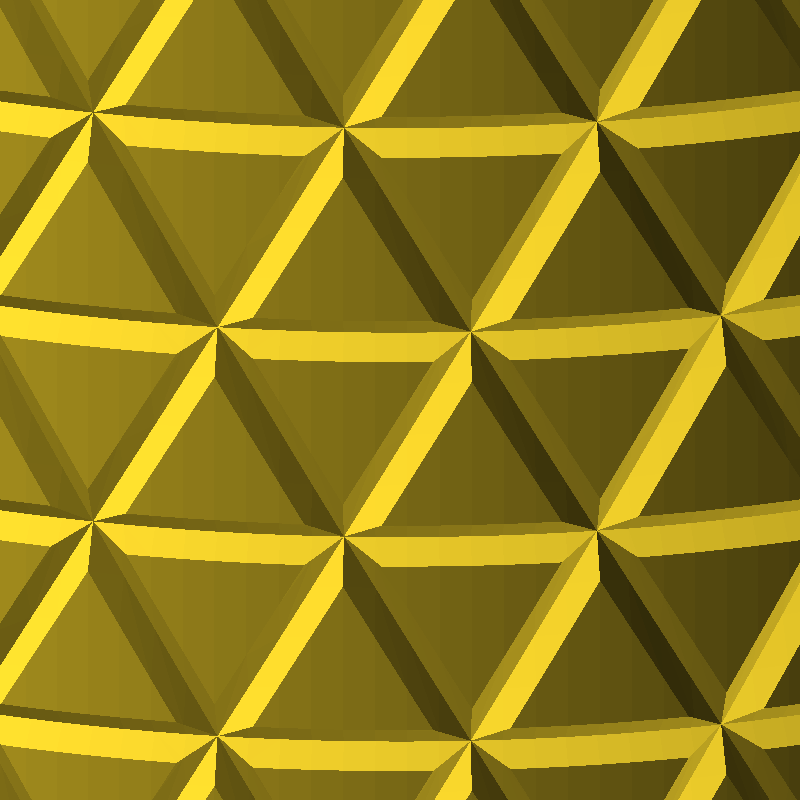
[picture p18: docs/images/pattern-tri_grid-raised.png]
tri_grid, raised
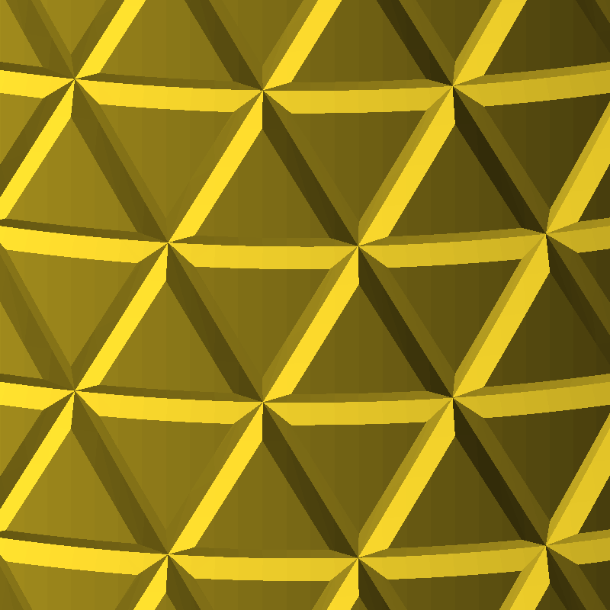
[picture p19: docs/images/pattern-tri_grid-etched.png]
tri_grid, etched
|  |  |

### teardrop

| Raised | Etched |
|---|---|
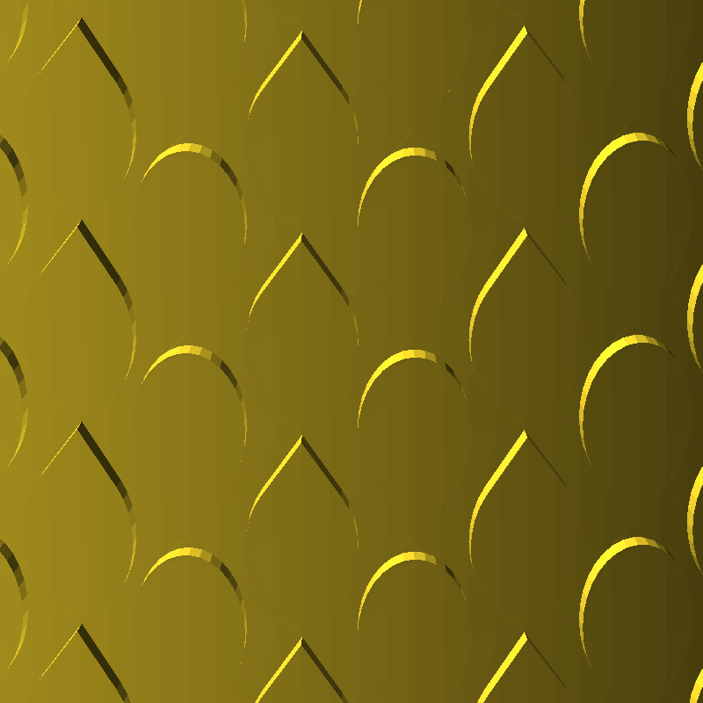
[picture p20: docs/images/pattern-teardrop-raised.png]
teardrop, raised
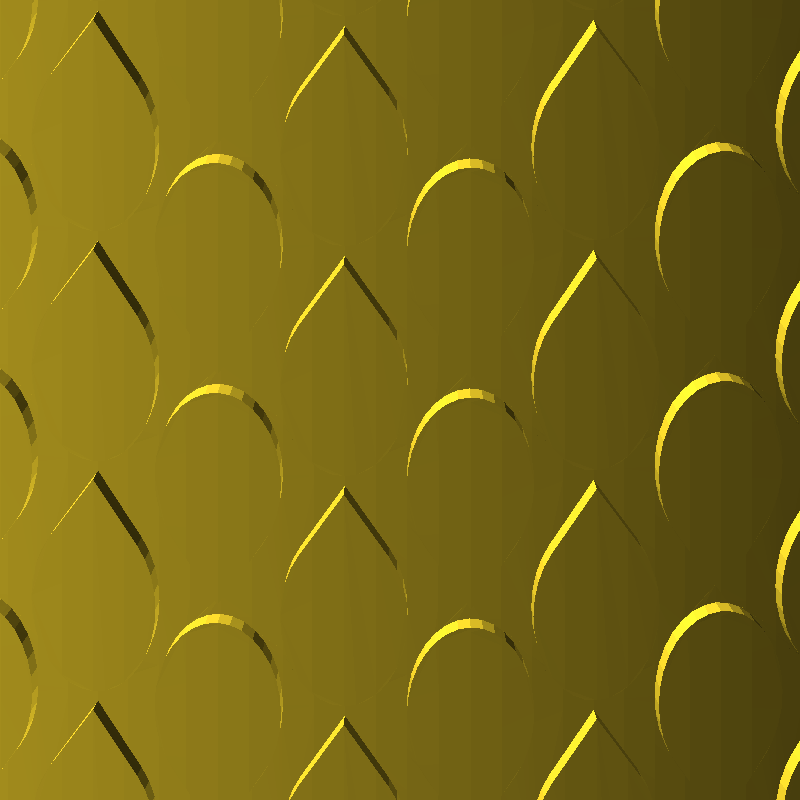
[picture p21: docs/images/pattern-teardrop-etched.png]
teardrop, etched
|  |  |

Interlocking. The two columns are half a period out of phase, so each drop's
point nests into the belly of its neighbour and the motif carries straight
across the tile seams — there are no visible tile boxes.

### tumbling_cubes

| Raised | Etched | Alternating |
|---|---|---|
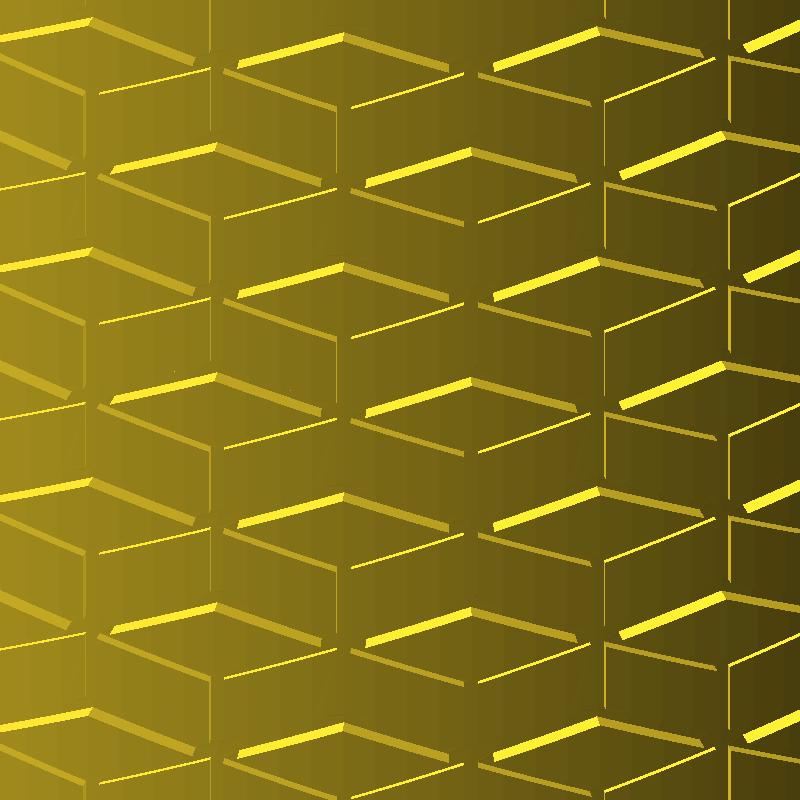
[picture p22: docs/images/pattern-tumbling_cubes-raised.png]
tumbling_cubes, raised
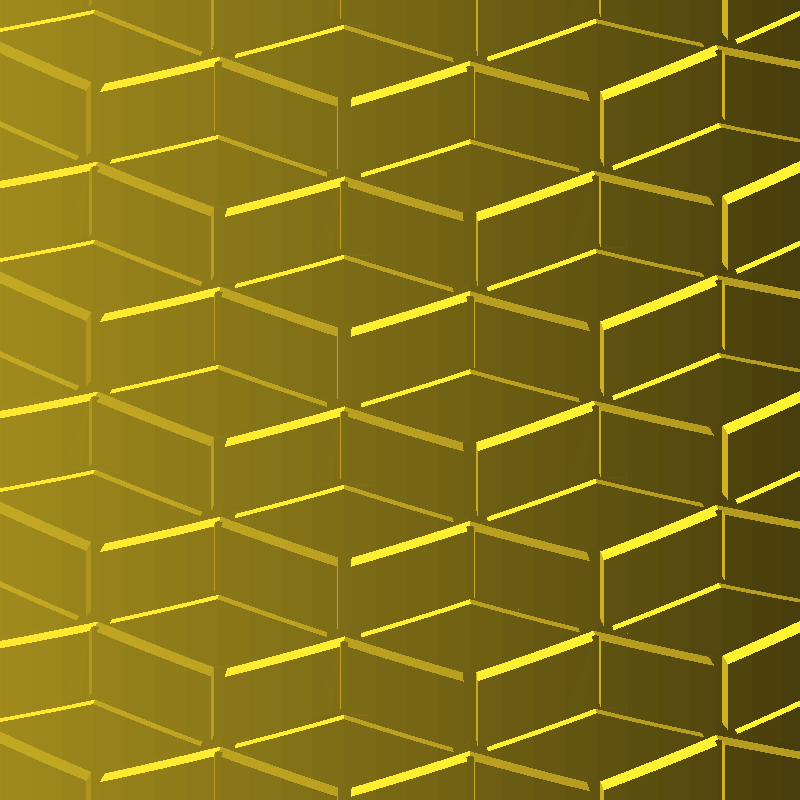
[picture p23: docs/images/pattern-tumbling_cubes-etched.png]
tumbling_cubes, etched
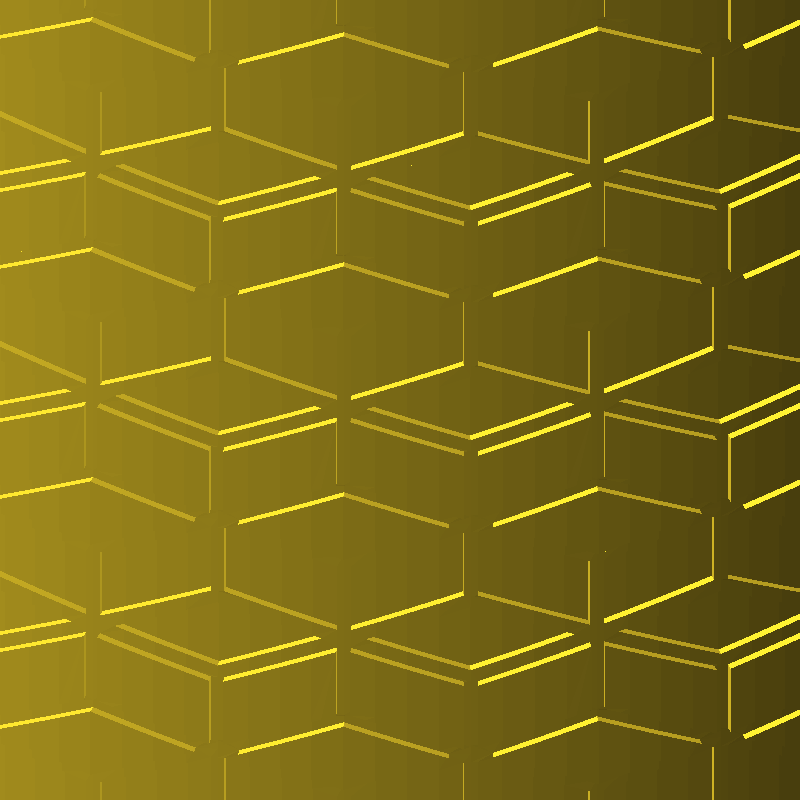
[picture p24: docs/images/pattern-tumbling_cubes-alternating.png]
tumbling_cubes, alternating
|  |  |  |

Interlocking. The rhombille tiling's three rhombi per hexagon sit at three
different heights, which is what sells the stacked-cube illusion; equal heights
would just read as a honeycomb. `"etched"` is a flat wall cut by a two-tier
groove: a primary groove along each hexagon's own outer boundary, plus a
secondary groove along the seams between its three rhombi. `"alternating"` is
real bas-relief -- some rhombi sit proud of the wall, others sunk below it, in
one render. `"etched"` and `"alternating"` both discard the per-rhombus height
split that is the only thing telling this pattern apart from `rhombille` --
the two patterns render byte-identical VNFs in these two modes, so only
`"raised"` looks different between them.

### intertwine

| Raised | Etched |
|---|---|
| intertwine, raised | intertwine, etched |

Interlocking, and genuinely woven: look at any crossing and one strand is
broken so the other reads as passing over it, alternating all the way round
each ring. Also by far the most expensive pattern to render — roughly two
minutes per image here, the largest single chunk of the script's runtime.

### islamic_star

| Raised | Etched | Alternating |
|---|---|---|
| islamic_star, raised | islamic_star, etched | islamic_star, alternating |

Interlocking. Eight-point stars with a four-point cross filling each gap; the
two shapes tile the plane exactly and share whole edges, so the groove between
them is a uniform incised line. `"etched"` is a flat wall cut by that primary
groove; neither shape has internal sub-structure, so there is no secondary
tier here. `"alternating"` renders one shape proud of the wall and the other
sunk below it, in a single render.

### tetrakis_square

| Raised | Etched | Alternating |
|---|---|---|
| tetrakis_square, raised | tetrakis_square, etched | tetrakis_square, alternating |

Conway's "kis" operation applied to the square tiling: each unit tile is fanned
into four isosceles right triangles from its own center point, like a
pinwheel. Not interlocking in the sense the four patterns above are — the
kis-cell here is the whole unit tile, so the fan never crosses a tile
boundary; adjacent tiles simply repeat, they don't join into one continuous
motif.

`"etched"` is a flat wall cut by a groove -- but since the fan spans the whole
unit tile, there is no second motif instance inside it to have an outer
boundary against, so only the secondary tier (the groove marking the fan
lines themselves) is present here; there is no primary tier to speak of. All
three "kis"-family patterns below and `floret_pentagonal` at the end of this
section use the same two-tier mechanism. `"alternating"` gives real bas-relief
-- alternating triangles of the fan sit proud of the wall or sunk below it, in
one render.

### kisrhombille

| Raised | Etched | Alternating |
|---|---|---|
| kisrhombille, raised | kisrhombille, etched | kisrhombille, alternating |

Kis applied to `tumbling_cubes`'s own rhombille tiling: each of its three
rhombi per hexagon is itself fanned into four triangles from its center,
instead of being left as one flat plateau — twelve facets per hexagon in
total. Reuses `tumbling_cubes`'s exact hexagon/rhombus geometry, so the two
patterns' motifs line up cell-for-cell; this one is just fanned rather than
raised as flat plateaus.

`"etched"` is a flat wall with both tiers present: a primary groove along each
hexagon's outer boundary, plus a secondary groove marking the fan lines within
each rhombus. `"alternating"` gives real bas-relief across the fan triangles,
some proud of the wall and some sunk below it.

### triakis_triangular

| Raised | Etched | Alternating |
|---|---|---|
| triakis_triangular, raised | triakis_triangular, etched | triakis_triangular, alternating |

Kis applied to a triangular tiling: the unit tile's diagonal splits it into
two triangles, and each of those is fanned into three sub-triangles from its
center. These two base triangles are right triangles from the square split,
not true equilateral ones — a deliberate simplification, the same trade-off
`kisrhombille` makes by reusing `tumbling_cubes`' already-unit-square-normalized
hexagons, prioritizing an exact unit-square tiling over strict equilateral
regularity. Three distinct heights per fan (not two, unlike `tetrakis_square`'s
alternation) — the same reasoning `tumbling_cubes` uses for its three rhombi,
that three different heights read better than two repeated.

Same two-tier `"etched"` mechanism as `kisrhombille`: a primary groove along
each base triangle's own outer boundary, plus a secondary groove marking the
fan lines within it. `"alternating"` gives real bas-relief across the fan.

### rhombille

| Raised | Etched | Alternating |
|---|---|---|
| rhombille, raised | rhombille, etched | rhombille, alternating |

Interlocking. The plain rhombille tiling `tumbling_cubes`'s isometric-cube
illusion is built from: the exact same hexagon/rhombus geometry, but every
rhombus raised to the same height instead of three different ones, so it
reads as a clean rhombus-grid relief rather than a set of stacked cubes.
`"etched"` is a flat wall cut by a two-tier groove, same mechanism as
`tumbling_cubes`: primary along each hexagon's outer boundary, secondary along
the seams between its three rhombi. `"alternating"` sinks some rhombi below
the wall and leaves others proud of it, in one render. `"etched"` and
`"alternating"` both discard the one thing that tells this pattern apart from
`tumbling_cubes` (the per-rhombus height split) — the two patterns render
byte-identical VNFs in these two modes, so only `"raised"` looks different
between them.

### cairo_pentagonal

| Raised | Etched | Alternating |
|---|---|---|
| cairo_pentagonal, raised | cairo_pentagonal, etched | cairo_pentagonal, alternating |

Interlocking. The Cairo pentagonal tiling (Wikipedia "V3^2.4.3.4", dual of the
snub square tiling): congruent, irregular pentagons — four long edges and one
short edge, two non-adjacent right angles — every pentagon raised to the same
height. `"etched"` is a flat wall cut by a two-tier groove: primary along each
hub's outer boundary, secondary along the pinwheel seams between its four
pentagons. `"alternating"` gives real bas-relief across the pinwheel, some
pentagons proud of the wall and some sunk below it.

### floret_pentagonal

| Raised | Etched | Alternating |
|---|---|---|
| floret_pentagonal, raised | floret_pentagonal, etched | floret_pentagonal, alternating |

Interlocking. The floret pentagonal tiling (Wikipedia "V3^4.6", dual of the
snub trihexagonal tiling): rosettes of 6 congruent, irregular pentagons
pinwheel around a shared hub point (four 120-degree angles and one
60-degree angle per pentagon). `"etched"` is a flat wall cut by a two-tier
groove: primary along each rosette's outer boundary, secondary along the
seams between its six pentagon blades. `"alternating"` gives real bas-relief
across the rosette, alternating blades proud of the wall and sunk below it.

### deltoidal_trihexagonal

| Raised | Etched |
|---|---|
| deltoidal_trihexagonal, raised | deltoidal_trihexagonal, etched |

Interlocking. The deltoidal trihexagonal tiling (Wikipedia "V3.4.6.4", dual
of the rhombitrihexagonal tiling): congruent kite/deltoid quadrilaterals --
two short edges and two long edges, with a line of symmetry through the
kite's two "pointy" vertices (a hexagon-centroid hub and a triangle-centroid
tip). Every kite belongs to three different, simultaneously-competing fan
types at once (a 6-fan around each hub, a 4-fan around each square-centroid
vertex, and a 3-fan around each tip) -- since no single alternating-height
scheme can respect all three, every kite is raised to the same uniform
height instead, like `cairo_pentagonal`/`rhombille`. Because the geometry
doesn't change between raised and etched, `"etched"` here is a true
inverted copy of the raised relief, not a separate flat-panel construction
like the "kis" family/`floret_pentagonal`.

## Full-Pot Examples

The real assembled planter, rendered from `planter.scad` at its shipped
defaults (`pattern_repeat = 16`, `smoothness = 60`) with only `pattern_type`
and `relief_mode` overridden.

| `hex_grid`, raised | `hex_grid`, etched |
|---|---|
| pot, hex_grid raised | pot, hex_grid etched |

| `islamic_star`, raised |
|---|
| pot, islamic_star raised |

**Fixed: tiles now come out approximately square.** `decorated_solid()` used
to pass `tex_reps = [pattern_repeat, pattern_repeat]`, asking for the same
number of repeats around the circumference as up the height regardless of the
pot's proportions — on the default pot (~440mm circumference, ~138mm height)
that made every tile ~3.2× wider than tall. `_square_tile_vertical_reps()`
(`modules/decoration.scad`) now derives the vertical repeat count from the
pot's real height and circumference instead, so tiles come out square at the
wall's mean radius.

A small residual remains because the decorated wall is a cone, not a
cylinder — `planter.scad`'s own peak-aware calculation puts its radius at
~61mm at the bottom growing to ~82.3mm at the top, and BOSL2 scales each
texture strip to the *local* radius as it revolves
(`lib/BOSL2/skin.scad`'s `_textured_revolution()`), while a single vertical
repeat count is fixed for the whole wall. At shipped defaults (`pattern_repeat
= 16`) that leaves tiles running **roughly 0.87× wide-to-tall at the bottom
rim to 1.17× at the top rim** — a small taper effect, not the ~2.8–3.75×
distortion this page used to document here.

Compare the `hex_grid` pot above with [its close-up](#hex_grid) — the
hexagons are recognizably regular now, not flattened into ribbons. The
`islamic_star` pot likewise shows a clean, legible eight-point-star motif
rather than a smeared band. That's also why this page can lead with the flat
tile close-ups without them misrepresenting the full-pot look anymore — they
were always the "designed proportions" reference, and the full pot is now
close to matching them.

## Insert Presets

`insert_preset` resolves `insert_top_d` / `insert_bottom_d` / `insert_height`
to a named size. All three renders use the same fixed camera (no `--viewall`),
so the sizes are directly comparable rather than each normalised to fill the
frame. Everything else is at defaults, including `pattern_type = "ridges"` --
at pot scale, its 16 tiles are barely distinguishable from the cylinder's own
60-facet smoothness, so these pots read as plain. These
sections are about silhouette and size, not decoration; see
[Pattern Comparison](#pattern-comparison) for what the patterns themselves
look like.

| `"small"` (100 / 75 / 85) | `"medium"` (130 / 100 / 120) | `"large"` (180 / 125 / 160) |
|---|---|---|
| small preset | medium preset | large preset |

## Outer Shape Modes

Both at default `pattern_type = "ridges"`, which — like the presets above —
reads as plain at pot scale; these renders are about silhouette, not
decoration.

| `"follow"` | `"custom"` |
|---|---|
| outer_mode follow | outer_mode custom |

`"follow"` wraps the outer body around the insert's own taper at a constant
`wall_thickness` -- when `pattern_type = "none"`. These renders use the
default `pattern_type = "ridges"` instead, and with a pattern active
`planter.scad` approximates the decorated wall as a straight cone through
the cavity's peak radius rather than exactly following the insert's
ledge/shoulder profile (see "Note: enabling decoration..." in README.md), so
the wall thickness isn't perfectly constant here even in `"follow"` mode.
`"custom"` ignores the taper either way and builds whatever
`outer_top_d` / `outer_bottom_d` / `outer_height` describe, subject to the
containment asserts in `planter.scad`.

The custom render here uses `outer_top_d = 180`, `outer_bottom_d = 180`,
`outer_height = 175` — a straight-sided, taller shell — rather than
`planter.scad`'s stock custom values (172 / 130 / 145). Those stock values are
tuned to sit just outside the default insert, so a render of them is almost
indistinguishable from `"follow"` and the pair would show nothing.

## Regenerating These Images

```bash
./docs/images/render.sh              # everything, ~10-15 minutes (dominated by "intertwine" and "bricks")
./docs/images/render.sh outer- pot-  # only output-file prefixes
./docs/images/render.sh islamic_star # only this pattern's close-ups (raised + etched)
```

The script hard-fails if any render's console output contains `CGAL error`.
That check is load-bearing: `tumbling_cubes`, `intertwine`, `islamic_star`,
`rhombille`, `cairo_pentagonal`, `floret_pentagonal`, `tetrakis_square` and
`kisrhombille` abort CGAL at some `pattern_repeat`/`smoothness` combinations
(the last two only in specific relief modes — `tetrakis_square` in `"etched"`,
`kisrhombille` in `"alternating"`), and when they do OpenSCAD still exits 0
and still writes a plausible-looking PNG. See README.md, "Note on the
interlocking patterns and CGAL". The `WARNING:` line those eight print on
every render is a proactive notice, not a failure.

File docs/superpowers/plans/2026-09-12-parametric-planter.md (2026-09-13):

# Parametric Decorative Planter Implementation Plan

> **For agentic workers:** REQUIRED SUB-SKILL: Use superpowers:subagent-driven-development (recommended) or superpowers:executing-plans to implement this plan task-by-task. Steps use checkbox (`- [ ]`) syntax for tracking.

**Goal:** Build a parametric OpenSCAD generator (`planter.scad`) that produces a decorative outer planter shell sized and fit to a user-specified plastic insert, with configurable ridge/geometric surface decoration (raised or etched), driven entirely by Customizer parameters.

**Architecture:** BOSL2-based OpenSCAD project. The cavity (what the insert sits in) and the outer decorative body are each built as revolved 2D profiles (`rotate_extrude` over a polygon of `[radius, z]` points), then combined via `difference()`. Decoration is applied to the outer body via BOSL2's `cyl()` texture support before the cavity is subtracted. All geometry math lives in pure functions per module so it can be tested with `assert()` independent of rendering.

**Tech Stack:** OpenSCAD 2021.01 (installed at `/opt/homebrew/bin/openscad`), BOSL2 (vendored, pinned copy committed to repo).

**Spec:** `docs/superpowers/specs/2026-09-12-parametric-planter-design.md`

## Erratum (post-implementation)

This plan was written before the vendored BOSL2 copy or its exact API were
available to inspect, and before OpenSCAD's `include`-based variable
override semantics were tested. Two assumptions below turned out to be
wrong; the text is left as originally written for historical accuracy, but
here is what actually happened during implementation:

- **`lib/BOSL2/textures.scad` does not exist** in the vendored BOSL2
  (Task 1, Step 3 and Step 4 reference it). Texture support lives in
  `lib/BOSL2/skin.scad`, which `lib/BOSL2/std.scad` already includes.
  `modules/decoration.scad` includes only `std.scad`.
- **Pre-`include` variable assignment does not override an included file's
  own defaults** in OpenSCAD — the textually-last assignment wins
  regardless of `include` order. This broke Task 6's and Task 8's planned
  test-harness pattern (assign variables in a wrapper, then `include
  <../planter.scad>`, expecting the wrapper's values to take effect). The
  actual test suite instead uses OpenSCAD's `-D 'var=value'` CLI flag,
  which is the real override mechanism, and `tests/test_planter_integration.scad`
  is a bare `include` with no pre-assignments. Task 8's `sed`-editing-a-
  wrapper approach (Steps 1-2 of that task) was never executed as written
  for this reason — and even setting that aside, generating the variant
  file under `/tmp` (as those steps do) would break its
  `include <../planter.scad>` line, since that path resolves relative to
  the generated file's own location, not the repo. See the shipped
  `.github/workflows/test.yml` for the test matrix actually run in CI,
  which also runs every test file, not the subset Task 8's Step 3 loop
  lists.
- **`pattern_type` no longer has a `"geometric"` value.** Tasks 5, 6, and 8
  below (including Task 5's `"<GEOMETRIC_TEXTURE>"` placeholder and Task 6
  and Task 8's `pattern_type = "ridges" | "geometric"` snippets and
  `for pt in ridges geometric` loop) reflect the original three-value
  design (`none`/`ridges`/`geometric`). Following any of those snippets
  literally now trips the new `pattern_type` assertion. This was later
  expanded
  to expose BOSL2's texture catalog directly as eight named options
  (`diamonds`, `hex_grid`, `pyramids`, `bricks`, `checkers`, `dots`,
  `cubes`, `tri_grid`) instead of bucketing them behind one generic name —
  see `modules/decoration.scad`'s `PATTERN_TYPES` for the current list, and
  the spec's own erratum for the same change.

## Global Constraints

- Round outer cross-section only (no square/hex outer body) this iteration.
- Floor is always solid; `drainage_holes` is a boolean toggle adding holes to that solid floor (not a separate base style).
- BOSL2 is vendored under `lib/BOSL2/` and committed — not a live git submodule.
- `pattern_depth < wall_thickness * 0.7` must be asserted wherever decoration is applied.
- Customizer parameters live only in `planter.scad` (top-level file); included modules take all values as explicit function/module arguments — no reliance on global variables from included files.
- Never commit without Barrett's explicit go-ahead for that specific commit; never push to GitHub without a separate explicit confirmation.

## Testing Convention (OpenSCAD)

There is no unit-test runner for OpenSCAD. Tests in this plan are `.scad` files under `tests/` that:
1. `include` the module file under test.
2. Call its pure functions and check results with `assert(condition, "message")`.
3. End with a trivial `cube(0.001);` so OpenSCAD has *something* to render (avoids "nothing to render" warnings masking real failures).

Run a test with:
```bash
openscad -o /tmp/test_out.csg tests/test_NAME.scad
```
- **Fail:** non-zero exit code, stderr contains `ERROR: Assertion failed` (or a parse error, if the function/module doesn't exist yet — this is the expected failure for a not-yet-implemented step).
- **Pass:** exit code 0, `/tmp/test_out.csg` created, no `ERROR` in output.

---

### Task 1: Project scaffolding and BOSL2 vendoring

**Files:**
- Create: `.gitignore`
- Create: `LICENSE`
- Create: `lib/BOSL2/` (vendored library, via `git clone` then de-git'd and committed as plain files)
- Create: `tests/test_bosl2_texture_smoke.scad`

**Interfaces:**
- Produces: `lib/BOSL2/std.scad`, `lib/BOSL2/textures.scad` available for `include <lib/BOSL2/std.scad>` from files in the repo root, and `include <../lib/BOSL2/std.scad>` from files in `modules/` or `tests/`.

- [ ] **Step 1: Create `.gitignore`**

```
*.stl
*.3mf
*.csg
*.png
.DS_Store
```

- [ ] **Step 2: Add an MIT `LICENSE` file**

Use standard MIT license text with copyright line `Copyright (c) 2026 Barrett Clark`.

- [ ] **Step 3: Vendor BOSL2**

```bash
mkdir -p /tmp/bosl2-vendor
git clone --depth 1 https://github.com/BelfrySCAD/BOSL2.git /tmp/bosl2-vendor
rm -rf /tmp/bosl2-vendor/.git
mkdir -p lib
cp -R /tmp/bosl2-vendor lib/BOSL2
rm -rf /tmp/bosl2-vendor
```

Record the vendored commit hash in a comment at the top of a new `lib/BOSL2_VERSION.txt` file (one line: the short SHA `git ls-remote --depth 1 https://github.com/BelfrySCAD/BOSL2.git HEAD` returns) so the pinned version is traceable later.

- [ ] **Step 4: Enumerate available texture names**

```bash
grep -oE '"\[?[a-z_]+_(ribs|diamonds|pyramids|grid|hex|dots|bricks|scales)[a-z_]*"' lib/BOSL2/textures.scad | sort -u
```

Write the resulting list of literal texture name strings to a comment block at the top of `tests/test_bosl2_texture_smoke.scad` — Task 5 (decoration module) depends on these exact strings.

- [ ] **Step 5: Write BOSL2 compatibility smoke test**

```openscad
// tests/test_bosl2_texture_smoke.scad
// Available BOSL2 texture names found via grep (fill in from Step 4 output above).
include <../lib/BOSL2/std.scad>

// Confirms this OpenSCAD version can build a textured cylinder using BOSL2.
cyl(h=20, r1=10, r2=8, texture="ribs", tex_size=[10,10], tex_depth=1, $fn=64);
```

- [ ] **Step 6: Run the smoke test and confirm it renders**

```bash
openscad -o /tmp/test_out.csg tests/test_bosl2_texture_smoke.scad
echo "exit: $?"
```
Expected: `exit: 0`, no `ERROR` in output. If the texture name from Step 4 doesn't exist, the error message lists valid names — pick a real one from that list and retry before moving on.

- [ ] **Step 7: Commit**

```bash
git add .gitignore LICENSE lib/BOSL2 lib/BOSL2_VERSION.txt tests/test_bosl2_texture_smoke.scad
git commit -m "Vendor BOSL2 and verify texture rendering compatibility"
```

---

### Task 2: Insert cavity profile module

**Files:**
- Create: `modules/insert.scad`
- Test: `tests/test_insert.scad`

**Interfaces:**
- Produces:
  - `function insert_cavity_height(insert_height, floor_thickness, bottom_margin)` → number (overall pot height required to fit the insert).
  - `function cavity_radius_at(z, insert_top_d, insert_bottom_d, insert_height, ledge_engagement_height, fit_clearance, body_clearance, pot_height)` → number (cavity radius at a given z, using the *lower* (loose) radius at the exact ledge boundary — callers needing the step's upper radius use `insert_top_d/2 + fit_clearance` directly).
  - `module insert_cavity(insert_top_d, insert_bottom_d, insert_height, ledge_engagement_height, fit_clearance, body_clearance, bottom_margin, floor_thickness, overshoot=20, fn=50)` → solid to `difference()` out of the outer body. Open at the top (extends `overshoot` mm above the rim) and flat (r=0 center point) at `z = floor_thickness`.

- [ ] **Step 1: Write the failing test**

```openscad
// tests/test_insert.scad
include <../modules/insert.scad>

// pot_height = insert_height + floor_thickness + bottom_margin
h = insert_cavity_height(130, 3, 5);
assert(h == 138, str("expected pot_height 138, got ", h));

// At the very top (z = pot_height), radius must equal the tight ledge fit.
r_top = cavity_radius_at(138, 150, 110, 130, 8, 0.3, 3, 138);
assert(r_top == 150/2 + 0.3, str("expected ledge radius 75.3, got ", r_top));

// At the bottom of the cavity (z = floor_thickness), radius must equal the
// loose clearance-zone fit around the insert's bottom.
r_bottom = cavity_radius_at(3, 150, 110, 130, 8, 0.3, 3, 138);
assert(r_bottom == 110/2 + 3, str("expected clearance radius 58, got ", r_bottom));

cube(0.001);
```

- [ ] **Step 2: Run test to verify it fails**

```bash
openscad -o /tmp/test_out.csg tests/test_insert.scad
```
Expected: FAIL — parse error, `insert.scad` does not exist yet.

- [ ] **Step 3: Write `modules/insert.scad`**

```openscad
// modules/insert.scad
function _lerp(a, b, t) = a + (b - a) * t;

function insert_cavity_height(insert_height, floor_thickness, bottom_margin) =
    insert_height + floor_thickness + bottom_margin;

function cavity_radius_at(z, insert_top_d, insert_bottom_d, insert_height,
                           ledge_engagement_height, fit_clearance, body_clearance,
                           pot_height) =
    let(
        insert_bottom_z = pot_height - insert_height,
        ledge_bottom_z  = pot_height - ledge_engagement_height
    )
    z <= insert_bottom_z ? insert_bottom_d/2 + body_clearance :
    z <  ledge_bottom_z  ? _lerp(insert_bottom_d/2, insert_top_d/2,
                                  (z - insert_bottom_z) / (ledge_bottom_z - insert_bottom_z))
                            + body_clearance :
    insert_top_d/2 + fit_clearance;

module insert_cavity(insert_top_d, insert_bottom_d, insert_height,
                      ledge_engagement_height, fit_clearance, body_clearance,
                      bottom_margin, floor_thickness, overshoot=20, fn=50) {
    pot_height = insert_cavity_height(insert_height, floor_thickness, bottom_margin);
    ledge_bottom_z = pot_height - ledge_engagement_height;
    r_bottom      = cavity_radius_at(floor_thickness, insert_top_d, insert_bottom_d,
                                      insert_height, ledge_engagement_height,
                                      fit_clearance, body_clearance, pot_height);
    r_ledge_lower = cavity_radius_at(ledge_bottom_z, insert_top_d, insert_bottom_d,
                                      insert_height, ledge_engagement_height,
                                      fit_clearance, body_clearance, pot_height);
    r_ledge_upper = insert_top_d/2 + fit_clearance;

    pts = [
        [0, floor_thickness],
        [r_bottom, floor_thickness],
        [r_bottom, pot_height - insert_height],
        [r_ledge_lower, ledge_bottom_z],
        [r_ledge_upper, ledge_bottom_z],
        [r_ledge_upper, pot_height + overshoot],
        [0, pot_height + overshoot]
    ];
    rotate_extrude($fn=fn) polygon(pts);
}
```

- [ ] **Step 4: Run test to verify it passes**

```bash
openscad -o /tmp/test_out.csg tests/test_insert.scad
echo "exit: $?"
```
Expected: `exit: 0`, no `ERROR`.

- [ ] **Step 5: Visual render check**

```bash
openscad -o /tmp/insert_cavity.png --imgsize=800,800 --camera=0,0,60,60,0,45,300 \
  -D 'insert_top_d=150; insert_bottom_d=110; insert_height=130; ledge_engagement_height=8; fit_clearance=0.3; body_clearance=3; bottom_margin=5; floor_thickness=3;' \
  --D 'insert_cavity(insert_top_d, insert_bottom_d, insert_height, ledge_engagement_height, fit_clearance, body_clearance, bottom_margin, floor_thickness);' 2>&1 || true
```
If `-D`-based module invocation doesn't render as expected on this OpenSCAD version, instead create a scratch file `/tmp/preview_insert.scad` that includes `modules/insert.scad` and calls `insert_cavity(150, 110, 130, 8, 0.3, 3, 5, 3);`, then run `openscad -o /tmp/insert_cavity.png --imgsize=800,800 /tmp/preview_insert.scad`. Open the PNG and confirm: a stepped cavity profile, tight recess at the top, wider open recess below it, solid disc at the bottom.

- [ ] **Step 6: Commit**

```bash
git add modules/insert.scad tests/test_insert.scad
git commit -m "Add insert cavity profile module with ledge/clearance zones"
```

---

### Task 3: Outer body module (follow-insert and custom modes)

**Files:**
- Create: `modules/body.scad`
- Test: `tests/test_body.scad`

**Interfaces:**
- Consumes: `modules/insert.scad` — `cavity_radius_at()`, `insert_cavity_height()`.
- Produces:
  - `module outer_body_follow(insert_top_d, insert_bottom_d, insert_height, ledge_engagement_height, fit_clearance, body_clearance, bottom_margin, floor_thickness, wall_thickness, fn=50)` → solid outer body, profile mirrors the cavity offset outward by `wall_thickness`, spanning `z = [0, pot_height]`.
  - `module outer_body_custom(outer_top_d, outer_bottom_d, outer_height, pot_height, fn=50)` → solid outer body with an independent linear taper; asserts `outer_height >= pot_height`. When `outer_height > pot_height`, the extra height is added below the rim (the cavity is translated up by `outer_height - pot_height` by the caller in `planter.scad`, not inside this module).

- [ ] **Step 1: Write the failing test**

```openscad
// tests/test_body.scad
include <../modules/insert.scad>
include <../modules/body.scad>

// custom mode must reject an outer_height shorter than the required cavity height
ok = true;
// (assert() inside outer_body_custom is exercised via render, not directly testable
//  as a boolean here, so we test the underlying math path instead:)
pot_h = insert_cavity_height(130, 3, 5); // 138
assert(pot_h == 138);

// follow-insert outer radius at the rim must equal cavity radius + wall_thickness
r = cavity_radius_at(138, 150, 110, 130, 8, 0.3, 3, 138) + 2.4;
assert(r == 150/2 + 0.3 + 2.4, str("expected 77.7, got ", r));

cube(0.001);
```

- [ ] **Step 2: Run test to verify it fails**

```bash
openscad -o /tmp/test_out.csg tests/test_body.scad
```
Expected: FAIL — `body.scad` does not exist.

- [ ] **Step 3: Write `modules/body.scad`**

```openscad
// modules/body.scad
include <insert.scad>

module outer_body_follow(insert_top_d, insert_bottom_d, insert_height,
                          ledge_engagement_height, fit_clearance, body_clearance,
                          bottom_margin, floor_thickness, wall_thickness, fn=50) {
    pot_height = insert_cavity_height(insert_height, floor_thickness, bottom_margin);
    steps = 40;
    pts = concat(
        [[0, 0]],
        [ for (i = [0:steps])
            let(
                z  = pot_height * i / steps,
                zc = max(z, floor_thickness),
                r  = cavity_radius_at(zc, insert_top_d, insert_bottom_d, insert_height,
                                       ledge_engagement_height, fit_clearance,
                                       body_clearance, pot_height) + wall_thickness
            )
            [r, z]
        ],
        [[0, pot_height]]
    );
    rotate_extrude($fn=fn) polygon(pts);
}

module outer_body_custom(outer_top_d, outer_bottom_d, outer_height, pot_height, fn=50) {
    assert(outer_height >= pot_height,
        str("outer_height (", outer_height, ") must be >= required cavity height (", pot_height, ")"));
    pts = [
        [0, 0],
        [outer_bottom_d/2, 0],
        [outer_top_d/2, outer_height],
        [0, outer_height]
    ];
    rotate_extrude($fn=fn) polygon(pts);
}
```

- [ ] **Step 4: Run test to verify it passes**

```bash
openscad -o /tmp/test_out.csg tests/test_body.scad
echo "exit: $?"
```
Expected: `exit: 0`.

- [ ] **Step 5: Add and run an assertion-failure test for custom mode**

```openscad
// tests/test_body_custom_assert.scad
include <../modules/body.scad>
// outer_height (100) is deliberately shorter than pot_height (138) — must fail.
outer_body_custom(150, 110, 100, 138);
```

```bash
openscad -o /tmp/test_out.csg tests/test_body_custom_assert.scad
echo "exit: $?"
```
Expected: non-zero exit, stderr contains `ERROR: Assertion failed`.

- [ ] **Step 6: Commit**

```bash
git add modules/body.scad tests/test_body.scad tests/test_body_custom_assert.scad
git commit -m "Add outer body module with follow-insert and custom taper modes"
```

---

### Task 4: Base / drainage module

**Files:**
- Create: `modules/base.scad`
- Test: `tests/test_base.scad`

**Interfaces:**
- Consumes: nothing from earlier tasks (self-contained; caller passes plain numbers).
- Produces: `module drainage_holes(count, diameter, placement_radius, floor_thickness)` → union of cylinders cut through the floor, for use inside a `difference()` in `planter.scad`.

- [ ] **Step 1: Write the failing test**

```openscad
// tests/test_base.scad
include <../modules/base.scad>
// Smoke-test only: confirm the module exists and renders without error.
drainage_holes(6, 4, 30, 3);
```

- [ ] **Step 2: Run test to verify it fails**

```bash
openscad -o /tmp/test_out.csg tests/test_base.scad
```
Expected: FAIL — `base.scad` does not exist.

- [ ] **Step 3: Write `modules/base.scad`**

```openscad
// modules/base.scad
module drainage_holes(count, diameter, placement_radius, floor_thickness) {
    for (i = [0 : count - 1]) {
        angle = i * 360 / count;
        translate([placement_radius * cos(angle), placement_radius * sin(angle), -1])
            cylinder(h = floor_thickness + 2, d = diameter, $fn = 32);
    }
}
```

- [ ] **Step 4: Run test to verify it passes**

```bash
openscad -o /tmp/test_out.csg tests/test_base.scad
echo "exit: $?"
```
Expected: `exit: 0`.

- [ ] **Step 5: Commit**

```bash
git add modules/base.scad tests/test_base.scad
git commit -m "Add drainage hole module for solid base"
```

---

### Task 5: Decoration module

**Files:**
- Create: `modules/decoration.scad`
- Test: `tests/test_decoration.scad`

**Interfaces:**
- Consumes: real BOSL2 texture name strings enumerated in Task 1, Step 4 (recorded in `tests/test_bosl2_texture_smoke.scad`'s header comment).
- Produces: `module decorated_solid(pattern_type, pattern_orientation, relief_mode, pattern_depth, pattern_repeat, r1, r2, height, wall_thickness, fn=50)` — a solid cylinder/cone (`r1` at bottom, `r2` at top) with the requested surface texture, or a plain `cylinder()` when `pattern_type == "none"`. Callers `difference()` this against the cavity, same as they would `outer_body_follow`/`outer_body_custom` — but note this module replaces those for the *decorated* case (`planter.scad` in Task 6 chooses between plain body modules and this one).

- [ ] **Step 1: Write the failing test**

```openscad
// tests/test_decoration.scad
include <../modules/decoration.scad>

// "none" must produce plain geometry without needing BOSL2 at all.
decorated_solid("none", "vertical", "raised", 1, 8, 50, 75, 100, 3);
```

- [ ] **Step 2: Run test to verify it fails**

```bash
openscad -o /tmp/test_out.csg tests/test_decoration.scad
```
Expected: FAIL — `decoration.scad` does not exist.

- [ ] **Step 3: Write `modules/decoration.scad`**

Use the exact texture name strings found in Task 1 Step 4 in place of `"<RIDGE_TEXTURE>"` / `"<GEOMETRIC_TEXTURE>"` below before committing this file — do not leave the placeholder names in the committed version.

```openscad
// modules/decoration.scad
include <../lib/BOSL2/std.scad>

function _decoration_texture(pattern_type, pattern_orientation) =
    pattern_type == "ridges"    ? "<RIDGE_TEXTURE>" :
    pattern_type == "geometric" ? "<GEOMETRIC_TEXTURE>" :
    undef;

module decorated_solid(pattern_type, pattern_orientation, relief_mode, pattern_depth,
                        pattern_repeat, r1, r2, height, wall_thickness, fn=50) {
    if (pattern_type == "none") {
        cylinder(h = height, r1 = r1, r2 = r2, $fn = fn);
    } else {
        assert(pattern_depth < wall_thickness * 0.7,
            str("pattern_depth (", pattern_depth, ") must be < 70% of wall_thickness (", wall_thickness, ")"));
        tex = _decoration_texture(pattern_type, pattern_orientation);
        rot = (pattern_orientation == "horizontal") ? 90 : 0;
        rotate([0, 0, 0])
        zrot(0)
        cyl(h = height, r1 = r1, r2 = r2, anchor = BOTTOM, $fn = fn,
            texture = tex,
            tex_size = [pattern_repeat, pattern_repeat],
            tex_depth = pattern_depth,
            tex_inset = (relief_mode == "etched"),
            tex_rot = rot);
    }
}
```

- [ ] **Step 4: Run test to verify it passes**

```bash
openscad -o /tmp/test_out.csg tests/test_decoration.scad
echo "exit: $?"
```
Expected: `exit: 0`.

- [ ] **Step 5: Add a decorated-render test and check it visually**

```openscad
// tests/test_decoration_ridges.scad
include <../modules/decoration.scad>
decorated_solid("ridges", "vertical", "raised", 1.5, 12, 75, 60, 100, 4);
```

```bash
openscad -o /tmp/test_out.csg tests/test_decoration_ridges.scad && echo "exit: $?"
openscad -o /tmp/ridges.png --imgsize=800,800 tests/test_decoration_ridges.scad
```
Confirm `exit: 0` and open `/tmp/ridges.png` to visually confirm vertical raised ridges appear on the tapered surface. Repeat with `"geometric"` / `"etched"` to sanity-check the other combination before moving on.

- [ ] **Step 6: Add and run an assertion-failure test for depth-vs-wall**

```openscad
// tests/test_decoration_depth_assert.scad
include <../modules/decoration.scad>
// pattern_depth (3) is not < 70% of wall_thickness (3) — must fail.
decorated_solid("ridges", "vertical", "raised", 3, 12, 75, 60, 100, 3);
```

```bash
openscad -o /tmp/test_out.csg tests/test_decoration_depth_assert.scad
echo "exit: $?"
```
Expected: non-zero exit, `ERROR: Assertion failed`.

- [ ] **Step 7: Commit**

```bash
git add modules/decoration.scad tests/test_decoration.scad tests/test_decoration_ridges.scad tests/test_decoration_depth_assert.scad
git commit -m "Add decoration module with ridge/geometric texture support"
```

---

### Task 6: Top-level assembly (`planter.scad`)

**Files:**
- Create: `planter.scad`
- Test: `tests/test_planter_integration.scad`

**Interfaces:**
- Consumes:
  - `modules/insert.scad`: `insert_cavity_height()`, `insert_cavity()`
  - `modules/body.scad`: `outer_body_follow()`, `outer_body_custom()`
  - `modules/decoration.scad`: `decorated_solid()`
  - `modules/base.scad`: `drainage_holes()`
- Produces: the final renderable model at the top level of `planter.scad` (no new interface — this is the leaf of the dependency graph).

- [ ] **Step 1: Write the failing integration test**

```openscad
// tests/test_planter_integration.scad
// Renders planter.scad with the real 150/110/130 insert and default decoration,
// just to confirm the full assembly compiles without error.
insert_top_d = 150;
insert_bottom_d = 110;
insert_height = 130;
ledge_engagement_height = 8;
fit_clearance = 0.3;
body_clearance = 3;
bottom_margin = 5;
floor_thickness = 3;
wall_thickness = 3;
outer_mode = "follow"; // "follow" or "custom"
outer_top_d = 160;     // only used when outer_mode == "custom"
outer_bottom_d = 120;  // only used when outer_mode == "custom"
outer_height = 140;    // only used when outer_mode == "custom"
pattern_type = "ridges";       // "none" | "ridges" | "geometric"
pattern_orientation = "vertical"; // "vertical" | "horizontal"
relief_mode = "raised";           // "raised" | "etched"
pattern_depth = 1.5;
pattern_repeat = 16;
drainage_holes_enabled = true;
drainage_hole_count = 6;
drainage_hole_diameter = 4;
smoothness = 80;

include <../planter.scad>
```

- [ ] **Step 2: Run test to verify it fails**

```bash
openscad -o /tmp/test_out.csg tests/test_planter_integration.scad
```
Expected: FAIL — `planter.scad` does not exist.

- [ ] **Step 3: Write `planter.scad`**

```openscad
// planter.scad
include <lib/BOSL2/std.scad>
include <modules/insert.scad>
include <modules/body.scad>
include <modules/decoration.scad>
include <modules/base.scad>

/* [Insert Dimensions] */
insert_top_d = 150;     // top rim diameter (mm)
insert_bottom_d = 110;  // bottom diameter (mm)
insert_height = 130;    // insert height (mm)

/* [Fit] */
ledge_engagement_height = 8; // depth of the rim's tight-fit seat (mm)
fit_clearance = 0.3;         // radial clearance at the rim seat (mm)
body_clearance = 3;          // radial clearance around the tapered insert body (mm)
bottom_margin = 5;           // air gap below the insert's bottom (mm)

/* [Outer Shape] */
outer_mode = "follow"; // "follow" or "custom"
wall_thickness = 3;     // used in follow mode (mm)
outer_top_d = 160;      // used in custom mode (mm)
outer_bottom_d = 120;   // used in custom mode (mm)
outer_height = 140;     // used in custom mode (mm)

/* [Decoration] */
pattern_type = "ridges";          // "none", "ridges", "geometric"
pattern_orientation = "vertical";  // "vertical", "horizontal"
relief_mode = "raised";            // "raised", "etched"
pattern_depth = 1.5;    // mm
pattern_repeat = 16;    // tile count around circumference

/* [Base] */
floor_thickness = 3;              // mm
drainage_holes_enabled = false;    // add drainage holes to the solid floor
drainage_hole_count = 6;
drainage_hole_diameter = 4;

/* [Quality] */
smoothness = 80; // $fn used for all revolved geometry

assert(insert_bottom_d < insert_top_d,
    "insert_bottom_d must be smaller than insert_top_d (insert tapers inward)");
assert(wall_thickness > 0, "wall_thickness must be > 0");
assert(pattern_depth < wall_thickness * 0.7 || pattern_type == "none",
    "pattern_depth must be < 70% of wall_thickness");

pot_height = insert_cavity_height(insert_height, floor_thickness, bottom_margin);

module planter() {
    difference() {
        // outer body (plain or decorated) --------------------------------
        if (pattern_type == "none") {
            if (outer_mode == "custom") {
                outer_body_custom(outer_top_d, outer_bottom_d, outer_height, pot_height, fn=smoothness);
            } else {
                outer_body_follow(insert_top_d, insert_bottom_d, insert_height,
                    ledge_engagement_height, fit_clearance, body_clearance,
                    bottom_margin, floor_thickness, wall_thickness, fn=smoothness);
            }
        } else {
            // decorated_solid needs simple r1/r2/height, so decoration is only
            // offered as a straight-taper cone regardless of outer_mode; this
            // matches the "follow" profile's endpoints when outer_mode=="follow".
            r_top = (outer_mode == "custom") ? outer_top_d/2
                    : cavity_radius_at(pot_height, insert_top_d, insert_bottom_d, insert_height,
                        ledge_engagement_height, fit_clearance, body_clearance, pot_height) + wall_thickness;
            r_bottom = (outer_mode == "custom") ? outer_bottom_d/2
                    : cavity_radius_at(floor_thickness, insert_top_d, insert_bottom_d, insert_height,
                        ledge_engagement_height, fit_clearance, body_clearance, pot_height) + wall_thickness;
            h = (outer_mode == "custom") ? outer_height : pot_height;
            decorated_solid(pattern_type, pattern_orientation, relief_mode, pattern_depth,
                pattern_repeat, r_bottom, r_top, h, wall_thickness, fn=smoothness);
        }

        // cavity -----------------------------------------------------------
        z_offset = (outer_mode == "custom") ? (outer_height - pot_height) : 0;
        translate([0, 0, z_offset])
            insert_cavity(insert_top_d, insert_bottom_d, insert_height,
                ledge_engagement_height, fit_clearance, body_clearance,
                bottom_margin, floor_thickness, fn=smoothness);

        // drainage -----------------------------------------------------------
        if (drainage_holes_enabled) {
            r_bottom_cavity = cavity_radius_at(floor_thickness, insert_top_d, insert_bottom_d,
                insert_height, ledge_engagement_height, fit_clearance, body_clearance, pot_height);
            drainage_holes(drainage_hole_count, drainage_hole_diameter,
                r_bottom_cavity * 0.6, floor_thickness);
        }
    }
}

planter();
```

- [ ] **Step 4: Run test to verify it passes**

```bash
openscad -o /tmp/test_out.csg tests/test_planter_integration.scad
echo "exit: $?"
```
Expected: `exit: 0`, no `ERROR`.

- [ ] **Step 5: Render a preview image with the real insert dimensions**

```bash
openscad -o /tmp/planter_default.png --imgsize=1000,1000 tests/test_planter_integration.scad
```
Open the PNG and confirm: a tapered vertical-ridged pot with a visible internal step near the top and a solid floor with 6 drainage holes.

- [ ] **Step 6: Commit**

```bash
git add planter.scad tests/test_planter_integration.scad
git commit -m "Add top-level planter.scad assembling insert, body, decoration, and base"
```

---

### Task 7: README and documentation

**Files:**
- Create: `README.md`

**Interfaces:**
- Consumes: nothing (documentation only).

- [ ] **Step 1: Write `README.md`**

Include these sections:
1. **What this is** — one paragraph, links to nothing external, describes the parametric planter generator.
2. **Requirements** — OpenSCAD 2019.05+ (BOSL2 is vendored, no separate install needed); Customizer panel recommended (View → Show Customizer).
3. **Measuring your insert** — explains `insert_top_d` (widest point / rim diameter), `insert_bottom_d`, `insert_height`, with a note that these are the *only* required measurements to reprint for a different insert.
4. **Parameter reference** — one line per Customizer parameter (name, meaning, default), grouped by the same `[Section]` headings used in `planter.scad`.
5. **Preset: this project's insert** — the exact values used throughout this plan (`insert_top_d=150, insert_bottom_d=110, insert_height=130`), presented as a copy-pasteable settings block.
6. **Decoration examples** — a short table: `pattern_type` × `relief_mode` combinations and what each looks like in one sentence.
7. **License** — link to `LICENSE`.

- [ ] **Step 2: Sanity-check the README's parameter reference against `planter.scad`**

```bash
grep -E '^\w+ = ' planter.scad
```
Compare the output to the README's parameter table — every variable listed here must appear in the README table (and vice versa). Fix any mismatch.

- [ ] **Step 3: Commit**

```bash
git add README.md
git commit -m "Add README with measuring guide and parameter reference"
```

---

### Task 8: Final validation pass

**Files:**
- None created; verification only.

- [ ] **Step 1: Render all four decoration combinations for the real insert**

```bash
for pt in ridges geometric; do
  for rm in raised etched; do
    sed -e "s/^pattern_type = .*/pattern_type = \"$pt\";/" \
        -e "s/^relief_mode = .*/relief_mode = \"$rm\";/" \
        tests/test_planter_integration.scad > /tmp/variant_${pt}_${rm}.scad
    openscad -o /tmp/variant_${pt}_${rm}.png --imgsize=800,800 /tmp/variant_${pt}_${rm}.scad
    echo "$pt/$rm exit: $?"
  done
done
```
Expected: all four `exit: 0`. Open each PNG and confirm the pattern/relief combination looks correct (raised = protrudes outward, etched = recessed inward).

- [ ] **Step 2: Render the custom outer-mode path**

```bash
sed -e 's/^outer_mode = .*/outer_mode = "custom";/' tests/test_planter_integration.scad > /tmp/variant_custom.scad
openscad -o /tmp/variant_custom.png --imgsize=800,800 /tmp/variant_custom.scad
echo "exit: $?"
```
Expected: `exit: 0`. Confirm visually the outer silhouette differs from follow-mode while the insert still visibly seats correctly (step near the top).

- [ ] **Step 3: Re-run every test file to confirm nothing regressed**

```bash
for f in tests/test_insert.scad tests/test_body.scad tests/test_base.scad \
         tests/test_decoration.scad tests/test_planter_integration.scad; do
  openscad -o /tmp/final_check.csg "$f"
  echo "$f exit: $?"
done
```
Expected: every line reads `exit: 0`.

- [ ] **Step 4: Report to Barrett**

Summarize: what renders correctly, any BOSL2 texture names actually used (from Task 1 Step 4), and that GitHub repo creation/push is the next step pending his go-ahead (per the spec's GitHub section).

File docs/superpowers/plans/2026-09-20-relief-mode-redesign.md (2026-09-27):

# Relief Mode Redesign Implementation Plan

> **For agentic workers:** REQUIRED SUB-SKILL: Use superpowers:subagent-driven-development (recommended) or superpowers:executing-plans to implement this plan task-by-task. Steps use checkbox (`- [ ]`) syntax for tracking.

**Goal:** Rework `relief_mode == "etched"` for the 8 Phase-1 custom-tile patterns (`tumbling_cubes`, `islamic_star`, `tetrakis_square`, `kisrhombille`, `triakis_triangular`, `rhombille`, `cairo_pentagonal`, `floret_pentagonal`) into a true two-tier outline engrave (flat wall, a primary groove around each motif's outer silhouette, a thinner/shallower secondary groove on internal facet seams), and add a new third `relief_mode` value, `"alternating"`, that renders some copies of a motif proud of the wall and others sunk below it in one render, for the same 8 patterns. `"raised"` does not change for any pattern. `intertwine`, `teardrop`, and `deltoidal_trihexagonal` are explicitly out of scope (three different reasons -- see Global Constraints).

**Architecture:** Two new shared tile-assembler functions live in `modules/decoration.scad` next to the existing `_tile_from_islands()`: `_tile_outline_from_islands(motif_groups, outer_gap, inner_gap)` (etched) builds a full planar edge-adjacency arrangement over each pattern's *original, pre-shrink* sub-regions and classifies every internal shared edge as a primary (different-motif) or secondary (same-motif) groove; `_tile_alternating_from_islands(islands, high_group)` (alternating) reuses `_tile_from_islands()` with every island forced to height `0` or `1` by an `alt_key` tag and a real `ground_z = 0.5` nominal-wall plane. Both require `_tile_from_islands()` and `_tile_walls()` to gain a `ground_z` parameter (default `0`, so every existing raised-mode caller is unaffected) with `_tile_walls()` getting a real conditional on the sign of `z - ground_z`, not just a substitution -- a "low" island's wall would otherwise wind backwards. Each of the 8 patterns' islands-building loops is extended to also expose its *original* (un-shrunk) sub-regions grouped by motif (`motif_groups`, for the outline builder) and a per-island `group_id`/`alt_key` pair (for the alternating builder) -- two genuinely different tags, only coinciding for 6 of the 8 patterns (the "kis" family diverges; see Global Constraints).

**Tech Stack:** OpenSCAD 2021.01, BOSL2 (`lib/BOSL2/std.scad`), this repo's existing `modules/decoration.scad` VNF-tile infrastructure (`_tile_from_islands()`, `_tile_walls()`, `_tile_on_edge()`, `_tile_quantize()`/`_tile_q()`, `_UNIT_TILE`, `_kis_shrunk_fan()`).

**Spec:** `docs/superpowers/specs/2026-09-20-relief-mode-redesign-design.md` -- this plan implements that spec in full for Phase 1; every correction in its "Design" section (Correction 1, 1b, 2) is load-bearing and is carried forward verbatim below, not re-derived or simplified.

## Global Constraints

- `RELIEF_MODES = ["raised", "etched", "alternating"]` -- a new, separate list from `PATTERN_TYPES` (pattern *names*, not modes). `decorated_solid()` asserts `in_list(relief_mode, RELIEF_MODES)` the same way it already asserts `pattern_type`.
- The 8 Phase-1 `"alternating"`-supporting patterns, exactly: `tumbling_cubes`, `islamic_star`, `tetrakis_square`, `kisrhombille`, `triakis_triangular`, `rhombille`, `cairo_pentagonal`, `floret_pentagonal`. If `relief_mode == "alternating"` and `pattern_type` is not one of these 8, `decorated_solid()` must assert with a message naming which `pattern_type`s currently support `"alternating"` -- never silently fall back to `"raised"`.
- `intertwine`'s `"etched"` mode is **unchanged**, not migrated to `_tile_outline_from_islands()` at all: `_intertwine_tile()` unions every overlapping ring strand into one island before it ever reaches `_tile_from_islands()` (`modules/decoration.scad:665-678` as of this plan), so there is no non-overlapping planar arrangement for the outline builder to classify, even for a single group -- the existing generic `_tile_from_islands()` + `tex_inset` mechanism already grooves around that one island's own outer boundary, which is exactly the whole-silhouette result this pattern needs. `intertwine` does not support `"alternating"` either: the same union that erases per-ring identity also erases the tagging `alt_key` would need, and splitting the strands back apart would reintroduce the overlapping-strand VNF-closure problem that union was written to avoid. Do not touch `_intertwine_tile()` in this plan.
- `teardrop` has no islands list at all (`_teardrop_tile()` is a hand-rolled outline, not built via `_tile_from_islands()`) and supports neither new mode in Phase 1. Do not touch `_teardrop_tile()` in this plan.
- `deltoidal_trihexagonal` has an islands list (`_deltoidal_trihexagonal_tile()`) but no `relief_mode` parameter and no per-island height variation -- it merged into `main` after this spec was first drafted and has no mode split to rework or preserve. Do not touch `_deltoidal_trihexagonal_tile()`, and do not add it to `RELIEF_MODES`-alternation support, in this plan.
- `dots`, `cubes`, `checkers`, `bricks` are out of scope entirely (Phase 2, a separate future plan) -- do not attempt to convert their BOSL2-native heightfields to islands-based tiles here.
- The alternating builder's islands format is `[[region, height, group_id, alt_key], ...]` -- **two extra fields** versus `_tile_from_islands()`'s plain `[region, height]`. `group_id` identifies which physical motif an island belongs to (used only by the outline builder, to classify same-motif vs. different-motif edges); `alt_key` identifies which high/low alternation bucket an island falls into (used only by `_tile_alternating_from_islands()`, via `high_group`, a set of `alt_key` values that render high). These fields coincide (`alt_key = group_id`) for `tumbling_cubes`, `rhombille`, `cairo_pentagonal`, `floret_pentagonal`, and `islamic_star`; they genuinely differ for the "kis" family (`tetrakis_square`, `kisrhombille`, `triakis_triangular`), where `group_id` must stay unique per fan (required for the outline builder's edge classification to work at all) while `alt_key` is the fan-triangle's own local index within its fan.
- `_tile_from_islands(islands, ground_z = 0)` and `_tile_walls(path, z, ground_z = 0)` both need the new `ground_z` parameter, defaulting to `0` so every existing raised-mode call site is unaffected. `_tile_walls()` needs a real conditional on the sign of `z - ground_z` (build the quad as `[[a,ground_z],[b,ground_z],[b,z],[a,z]]` when `z >= ground_z`, or with the low/high pair swapped, `[[a,z],[b,z],[b,ground_z],[a,ground_z]]`, when `z < ground_z`) -- a plain parameter substitution alone produces a wall with a flipped face normal for any "low" island (`z = 0 < ground_z = 0.5`), which is a real, silent geometry bug (not always visible at the VNF level, only downstream in CGAL's manifoldness check or a visibly inverted face).
- `_tile_alternating_from_islands(islands, high_group, ground_z = 0.5)` is a thin wrapper: `_tile_from_islands([for (il = islands) [il[0], in_list(il[3], high_group) ? 1 : 0]], ground_z)`. It ignores `il[1]` (the stored raw height) and `il[2]` (`group_id`) entirely -- only the region (`il[0]`) and `alt_key` (`il[3]`) matter to this builder.
- `_tile_outline_from_islands(motif_groups, outer_gap, inner_gap)` builds its edge-adjacency classification with **sort-based matching, not a nested double loop**. Verified directly (Task 1's own research pass): an `O(n^2)` nested-loop match over kisrhombille's own ~900-edge motif-group arrangement did not finish within a 180-second timeout; the sort-based approach below (`sort()` the `[key, edge_index]` pairs, then scan for adjacent-equal-key runs with a small bounded lookahead) computed the identical, independently-cross-checked match counts (129 primary pairs, 300 secondary pairs, 0 bugs) in about 4 seconds. Do not implement the outline builder's matching step as a double loop.
- **A second, separate performance risk exists downstream of matching: BOSL2's region `union()` function itself.** Verified directly: with the matching step fixed (sort-based, fast), building kisrhombille's 129-strip primary region and 300-strip secondary region via `union(primary_regions)`/`union(secondary_regions)` (each a flat list of single-quad regions, one per matched edge) took over two minutes combined and had not finished when this plan's own research pass killed it to stay within its own time budget. This is not a bug in the matching logic -- it is BOSL2's `union()` function itself, whose own doc comment (`lib/BOSL2/regions.scad:1230`) states plainly: "This function is much slower than the native union module acting on geometry... only use it when you need a point list for further processing" -- and its implementation is a **sequential fold** (union region 1 with region 2, union that result with region 3, and so on), so the accumulated region's own complexity grows at every step, not a single batch operation. `_tile_outline_from_islands()` genuinely needs the point-list (region) result, not rendered geometry, to keep composing with `_tile_from_islands()` downstream, so switching to the native 3D/2D `union()` *module* is not a drop-in option. Task 1 must budget real time to address this -- see Task 1 Step 4's own "if plain union is too slow" fallback (a batched/hierarchical union, unioning small groups first and then unioning the much-shorter list of group results) and Step 12's build-timing requirement. This plan's own author could not fully re-verify the batched fallback against the exact slow real-world input (kisrhombille's own overlapping, vertex-sharing strips) within this plan-writing pass's own time budget -- a synthetic stand-in test of comparable size (129/300 disjoint quads, not sharing any vertices) unioned in well under a minute, which is NOT the same shape of input as the real strips (which deliberately overlap at shared vertices, per `_outline_edge_strip()`'s own corner-coverage extension) and so does not prove the real case is fast, only that raw item count alone isn't automatically the bottleneck. Task 1's implementer must measure the real thing, not trust this plan's synthetic proxy.
- Every `motif_groups` list fed to `_tile_outline_from_islands()` must be built over a **3x3 "supertile"** of the pattern's own placement lattice (offsets `(dx, dy)` for `dx, dy` in `{-1, 0, 1}`, positions deduplicated via `_tile_q()`), not just the placements that happen to overlap the unit tile. This is Task 1's own load-bearing finding, not in the spec verbatim: feeding only the tile-covering placements list (e.g. `_CP_PLACEMENTS`'s 8 entries) leaves some of a motif's own internal edges without their true neighbour (that neighbour's sub-region lies just past the tile boundary, in a placement the covering list never needed), which the edge classifier cannot tell apart from a real gap/bug without seeing it. Verified computationally per pattern (Task 1's research): `islamic_star`, `kisrhombille`, `cairo_pentagonal`, `floret_pentagonal`, and the `tumbling_cubes`/`rhombille` 2-group split all resolve to exactly 0 unmatched-and-relevant edges at 3x3-supertile scale; `cairo_pentagonal` specifically does **not** resolve with just its own 4 covering hubs at full pinwheel membership (6 genuine bugs remained) -- it needs neighbour hubs the 3x3 supertile supplies.
- An unmatched edge is only a bug if it is also **relevant**: `_outline_edge_relevant(a, b)` (its axis-aligned bounding box overlaps `[0,1]x[0,1]` with a small epsilon) must be true. An unmatched-and-irrelevant edge (its true neighbour lives further out than the 3x3 supertile reached) contributes nothing to the final tile once clipped to `_UNIT_TILE`, so it is silently skipped, not asserted on.
- CGAL-fragility disclosure convention (established by `intertwine`/`cairo_pentagonal`/`floret_pentagonal`/`deltoidal_trihexagonal`'s own plans): local-macOS-clean is necessary but never sufficient to claim CI-clean. Every CGAL sweep result this plan or its tasks record must be labeled with the platform it was measured on, and any CI-pinned value must eventually be confirmed against a real GitHub Actions Ubuntu run before being trusted, not just measured locally.
- `planter.scad`'s Customizer dropdown comment for `relief_mode` (currently `// ["raised", "etched"]`, line 50 as of this plan) must become `// ["raised", "etched", "alternating"]`.

---

## Why a 3x3 supertile, sort-based matching, and a batched union fallback: the research behind this plan

This plan's author ran the actual edge-classification algorithm below against the real geometry in `modules/decoration.scad` (via throwaway OpenSCAD scripts that `include` the real file) before writing any task, per this project's own "verify against real code" convention. Three findings shape every task below and are restated here so implementers don't have to rediscover them:

1. **Feeding only the tile-covering placements list to the edge classifier produces false "gap" bugs.** For `islamic_star`, building `motif_groups` from just the star + 4 `_IS_CROSS_CENTERS` crosses (5 groups) left 48 of the crosses' own outward-facing edges unmatched -- their true neighbour (a star or cross in the next tile over) simply wasn't present in the input. All 48 turned out to be **irrelevant** (their bounding box lies entirely outside `[0,1]x[0,1]`), so this is not itself a bug, but a naive "assert every unmatched edge is a bug" check would wrongly fail on correct geometry. Building `motif_groups` from a 3x3 supertile of each pattern's placement lattice, deduplicated by `_tile_q()`-quantized position, resolved this to exactly 0 unmatched-and-relevant edges for `islamic_star`, `kisrhombille`, the `tumbling_cubes`/`rhombille` 2-group split, and `floret_pentagonal`. `cairo_pentagonal` needed the full 3x3 supertile specifically -- a narrower fix (materializing each of its own 4 covering hubs' full 4-member pinwheel, but no *new* hubs) still left 6 genuine unmatched-and-relevant edges, because Cairo's pinwheel-to-pinwheel boundaries reach hubs the covering list never lists at all.
2. **A nested double-loop edge match is too slow to ship.** `kisrhombille`'s own per-fan `group_id` scheme (required -- see Global Constraints) produces roughly 900 edges at 3x3-supertile scale; a straightforward `[for (i=...) [for (j=...) if (...) j]]` double loop over that many edges did not complete within 180 seconds (verified directly: an `openscad -o foo.stl` invocation of exactly this code was killed by `timeout 180` with no output). The sort-based alternative in Task 1 below -- pair each edge's canonical key with its own index, `sort()` the pairs (`sort()` orders nested vectors lexicographically), then scan the sorted list for runs of adjacent equal keys with a small bounded lookahead (not a full rescan to the end) -- computed the *identical* primary/secondary pair counts (cross-checked against the double-loop result on a smaller, tractable input where both approaches could run) in about 4 seconds on the same input.
3. **BOSL2's own region `union()` function is a separate, later bottleneck for the same pattern.** With matching fixed (finding 2 above), building `kisrhombille`'s groove geometry -- unioning its 129 primary-tier strip regions, then its 300 secondary-tier strip regions (`union(primary_regions)`/`union(secondary_regions)` in the builder below) -- took over two minutes combined and had not finished when this research pass stopped it. This is not a matching-algorithm bug: BOSL2's `union()` function's own doc comment says plainly it is "much slower than the native union module acting on geometry" and its implementation sequentially folds one region into the next (region1+region2, then +region3, then +region4, ...), so the accumulated region's own complexity grows at every step rather than being computed as one batch operation. Because `_tile_outline_from_islands()` needs the resulting *region* (a point list) to keep composing with `_tile_from_islands()` downstream, the native, fast 3D/2D `union()` *module* (which produces rendered geometry, not a region) is not a substitute. Task 1 Step 4 below includes a batched/hierarchical union fallback (`_outline_batched_union()`) that unions small groups first and then unions the much shorter list of group results, which should reduce the total work if the real bottleneck scales with the ACCUMULATED region's complexity rather than the raw item count -- but this plan's own research pass could not fully re-confirm that fallback against the real slow input (a synthetic stand-in of comparable item count, but of non-overlapping quads that don't share vertices the way the real strips deliberately do, unioned in under a minute and so does not prove the real case is fixed). Task 1's implementer must measure the real `kisrhombille`/`floret_pentagonal` build times directly (Step 12) and apply/tune the fallback if plain `union()` is still too slow, rather than trust this plan's own inconclusive synthetic check.

Every per-pattern task below builds `motif_groups` using this same "3x3 supertile, deduplicated" recipe via one shared helper, `_outline_supertile_points()`, introduced in Task 1.

---

## Task 1: Shared builders, `RELIEF_MODES` validation, and two proof patterns (`islamic_star`, `kisrhombille`)

This task is the spec's own recommended "prove the mechanism first" step: it lands both new shared builders, wires the new validation, and rewires exactly 2 patterns chosen to exercise both builders meaningfully -- `islamic_star` (the simple case: every group has one sub-region, `group_id == alt_key`, so the secondary groove tier degrades to empty and there's no internal fan to get wrong) and `kisrhombille` (the one pattern in this whole plan where `group_id` and `alt_key` genuinely diverge, and the highest-risk case for the edge-count/performance finding above). Every later task (2 through 6) reuses this task's shared functions unchanged.

**Files:**
- Modify: `modules/decoration.scad` (generalize `_tile_from_islands()`/`_tile_walls()`; add `_tile_q2()`, `_outline_edge_key()`, `_outline_all_edges()`, `_outline_edge_relevant()`, `_outline_edge_strip()`, `_outline_match_runs()`, `_outline_supertile_points()`, `_OUTLINE_INNER_Z`, `_tile_outline_from_islands()`, `_tile_alternating_from_islands()`; add `RELIEF_MODES`, `ALTERNATING_PATTERNS`; rewire `_islamic_star_tile()` and `_kisrhombille_tile()`; update `_decoration_texture()`'s dispatch for both; update `decorated_solid()`'s validation and `tex_inset` wiring)
- Modify: `planter.scad` (Customizer dropdown comment for `relief_mode`, line 50)
- Modify: `tests/test_decoration_islamic_star.scad` (add `"alternating"` block)
- Modify: `tests/test_decoration_kisrhombille.scad` (add `"alternating"` block)
- Create: `tests/test_decoration_invalid_relief_mode.scad`

**Interfaces:**
- Consumes: `_UNIT_TILE`, `_tile_on_edge()`, `_tile_q()`, `_tile_quantize()`, `_kis_shrunk_fan()`, `_kis_centroid()`, `_TC_CENTERS`, `_tc_rhombus()`, `_TC_V`, `_is_star()`, `_is_cross()`, `_IS_CROSS_CENTERS`, `_IS_R`, `_IS_RIN`, `_IS_RX`, `_IS_GAP`, `_IS_Z_STAR`, `_IS_Z_CROSS`, `_KIS_GAP` -- all pre-existing, unchanged.
- Produces (used by every later task): `_tile_from_islands(islands, ground_z = 0)`, `_tile_walls(path, z, ground_z = 0)`, `_outline_supertile_points(base_points)`, `_tile_outline_from_islands(motif_groups, outer_gap, inner_gap)`, `_tile_alternating_from_islands(islands, high_group, ground_z = 0.5)`, `RELIEF_MODES`, `ALTERNATING_PATTERNS`.

### Step 1: Write the failing tests

Add to `tests/test_decoration_islamic_star.scad` (append before the final `difference() { ... }` block that already renders `"raised"`):

```openscad
// "alternating" is new: star high, all four crosses low (a visual-judgment
// call per the spec's Decisions section -- confirm this reads well once
// rendered; change high_group below if not). group_id and alt_key coincide
// for this pattern (star = 0, crosses = 1..4) since each group has exactly
// one sub-region -- the natural motif identity IS the natural alternation
// bucket, per the spec's "Per-pattern high_group choice" section.
_tex_alt = _decoration_texture("islamic_star", "alternating");
assert(is_vnf(_tex_alt), "_decoration_texture(\"islamic_star\", \"alternating\") must be a valid VNF");
_alt_zs = unique([for (p = _tex_alt[0]) p[2]]);
// All three Z levels must appear: the star (high, z=1), each cross (low,
// z=0), and the real z=0.5 ground/groove between them -- the star and
// crosses are shrunk by _IS_GAP away from each other for this builder (the
// same groove _islamic_star_alternating_islands() carries over from raised
// mode's own shrink), so the ground plane is genuinely non-empty, not
// degenerate to zero area.
assert(_alt_zs == [0, 0.5, 1],
    str("islamic_star alternating VNF must use exactly Z levels {0, 0.5, 1} (nominal wall at 0.5), got ", _alt_zs));
assert(_tex_alt != _decoration_texture("islamic_star", "raised"),
    "islamic_star alternating tile must differ from raised");
assert(_tex_alt != _decoration_texture("islamic_star", "etched"),
    "islamic_star alternating tile must differ from etched");

for (axis = [0, 1]) {
    lo = _tile_edge_profile(_tex_alt, axis, 0);
    hi = _tile_edge_profile(_tex_alt, axis, 1);
    name = (axis == 0) ? "x" : "y";
    assert(len(lo) == len(hi),
        str("islamic_star alternating tile has ", len(lo), " vertices on ", name, "=0 but ",
            len(hi), " on ", name, "=1 -- tiles cannot stitch"));
    mismatched = [for (i = [0:len(lo)-1]) if (!approx(lo[i], hi[i]))
                     str(name, "=0 ", lo[i], " vs ", name, "=1 ", hi[i])];
    assert(len(mismatched) == 0,
        str("islamic_star alternating tile ", name, " edge vertices don't line up (including Z): ", mismatched));
}

// Etched must now be a genuinely different (flat panel + groove) VNF, not
// the same bump inverted via tex_inset -- this is the whole point of the
// rework. Z levels: 1 (panel), 0 (primary/outer groove, full depth). No
// secondary tier here: every group has exactly one sub-region (star alone,
// each cross alone), so there are no same-group internal edges to groove.
_tex_etched = _decoration_texture("islamic_star", "etched");
assert(is_vnf(_tex_etched), "_decoration_texture(\"islamic_star\", \"etched\") must be a valid VNF");
assert(_tex_etched != _tex, "islamic_star etched tile must differ from raised");
_etched_zs = unique([for (p = _tex_etched[0]) p[2]]);
assert(_etched_zs == [0, 1],
    str("islamic_star etched VNF must use exactly 2 Z levels (ground/primary-groove, panel), got ", _etched_zs));

difference() {
    decorated_solid("islamic_star", "vertical", "alternating", 1.5, 12, 75, 60, 100, 4);
    translate([300, 0, 0]) cube(10, center = true);
}
difference() {
    decorated_solid("islamic_star", "vertical", "etched", 1.5, 12, 75, 60, 100, 4);
    translate([300, 0, 0]) cube(10, center = true);
}
```

Add to `tests/test_decoration_kisrhombille.scad` (append before the final `difference() { ... }` block):

```openscad
// "alternating": alt_key is the fan-triangle's local index (0..3) within its
// own 4-triangle fan, matching the same pinwheel parity the raised heights
// already use ([1.0, 0.4, 1.0, 0.4] -- indices 0 and 2 are the "high" ones).
// group_id must stay unique per fan (a composite (center, k) key) so the
// etched outline builder can tell "same rhombus's own internal seam" apart
// from "boundary between two different rhombi" -- group_id and alt_key
// genuinely differ here, the one case in this whole plan where they do.
_tex_alt = _decoration_texture("kisrhombille", "alternating");
assert(is_vnf(_tex_alt), "_decoration_texture(\"kisrhombille\", \"alternating\") must be a valid VNF");
_alt_zs = unique([for (p = _tex_alt[0]) p[2]]);
assert(_alt_zs == [0, 0.5, 1],
    str("kisrhombille alternating VNF must use exactly Z levels {0, 0.5, 1}, got ", _alt_zs));
assert(_tex_alt != _decoration_texture("kisrhombille", "raised"),
    "kisrhombille alternating tile must differ from raised");
assert(_tex_alt != _decoration_texture("kisrhombille", "etched"),
    "kisrhombille alternating tile must differ from etched");

for (axis = [0, 1]) {
    lo = _tile_edge_profile(_tex_alt, axis, 0);
    hi = _tile_edge_profile(_tex_alt, axis, 1);
    name = (axis == 0) ? "x" : "y";
    assert(len(lo) == len(hi),
        str("kisrhombille alternating tile has ", len(lo), " vertices on ", name, "=0 but ",
            len(hi), " on ", name, "=1 -- tiles cannot stitch"));
    mismatched = [for (i = [0:len(lo)-1]) if (!approx(lo[i], hi[i]))
                     str(name, "=0 ", lo[i], " vs ", name, "=1 ", hi[i])];
    assert(len(mismatched) == 0,
        str("kisrhombille alternating tile ", name, " edge vertices don't line up (including Z): ", mismatched));
}

// Etched must now be a genuinely different (flat panel + two-tier groove)
// VNF from before this plan -- Z levels 1 (panel), 0.5 (secondary/internal
// fan-seam groove), 0 (primary groove -- but kisrhombille's own fans are
// grouped by (center, k), so EVERY internal edge is same-group/secondary;
// primary edges only appear between different rhombi/hexagons, which do
// exist here -- e.g. between two rhombi of the same hexagon share a spoke,
// which is a DIFFERENT group -- so both tiers must appear).
_tex_etched_new = _decoration_texture("kisrhombille", "etched");
_etched_zs_new = unique([for (p = _tex_etched_new[0]) p[2]]);
assert(_etched_zs_new == [0, 0.5, 1],
    str("kisrhombille etched VNF must use exactly Z levels {0, 0.5, 1} (two-tier groove), got ", _etched_zs_new));

difference() {
    decorated_solid("kisrhombille", "vertical", "alternating", 1.5, 12, 75, 60, 100, 4);
    translate([300, 0, 0]) cube(10, center = true);
}
```

Also create `tests/test_decoration_invalid_relief_mode.scad`:

```openscad
// tests/test_decoration_invalid_relief_mode.scad
//
// relief_mode was never validated before this plan. Two failure modes:
// a bogus string, and "alternating" on a pattern_type that doesn't support
// it (any of the 13 patterns outside ALTERNATING_PATTERNS).
include <../modules/decoration.scad>

decorated_solid("ridges", "vertical", "bogus", 1.5, 12, 75, 60, 100, 4);
```

Create a second negative-test file, `tests/test_decoration_invalid_alternating_pattern.scad`:

```openscad
// tests/test_decoration_invalid_alternating_pattern.scad
//
// "alternating" is only supported for the 8 Phase-1 patterns
// (ALTERNATING_PATTERNS). "ridges" is a BOSL2 heightfield pattern with no
// islands list at all, so this must fail loudly, not silently fall back to
// "raised".
include <../modules/decoration.scad>

decorated_solid("ridges", "vertical", "alternating", 1.5, 12, 75, 60, 100, 4);
```

### Step 2: Run tests to verify they fail

```bash
openscad -o /tmp/test.csg tests/test_decoration_islamic_star.scad
openscad -o /tmp/test.csg tests/test_decoration_kisrhombille.scad
openscad -o /tmp/test.csg tests/test_decoration_invalid_relief_mode.scad
openscad -o /tmp/test.csg tests/test_decoration_invalid_alternating_pattern.scad
```
Expected: the first two FAIL (`_decoration_texture("islamic_star"/"kisrhombille", "alternating")` doesn't resolve to a VNF yet -- `is_vnf()` assertion fails, or `decorated_solid()` itself asserts on an unrecognized `relief_mode`). The last two currently render successfully with no assertion at all (this project has never validated `relief_mode`) -- confirm this directly rather than assuming it: run `openscad -o /tmp/test.csg tests/test_decoration_invalid_relief_mode.scad` against the CURRENT, unmodified `modules/decoration.scad` and confirm it exits 0 (no assertion fires) before proceeding, so this task's own validation step has a real, demonstrated gap to close.

### Step 3: Generalize `_tile_from_islands()` and `_tile_walls()` with `ground_z`

Replace the existing `_tile_walls()` (`modules/decoration.scad:224-229`):

```openscad
// One vertical quad per non-shared segment, wound so a CCW path (BOSL2's
// convention for a region's outer path) faces outward and a CW path (a hole)
// faces inward. ground_z defaults to 0 (every existing raised-mode caller's
// own implicit floor); the alternating builder's "low" islands (z=0) sit
// BELOW a ground_z=0.5 nominal wall, which flips which pair of vertices is
// the "bottom" of the wall -- a plain substitution of ground_z for the old
// literal 0s is not enough (the quad's face normal would flip for any
// z < ground_z), so this branches explicitly on the sign of z - ground_z.
function _tile_walls(path, z, ground_z = 0) =
    let (n = len(path))
    [for (i = [0:n-1]) let (a = path[i], b = path[(i+1) % n])
        if (!_tile_on_edge(a, b))
            (z >= ground_z)
                ? [[[a[0], a[1], ground_z], [b[0], b[1], ground_z], [b[0], b[1], z], [a[0], a[1], z]],
                   [[0, 1, 2, 3]]]
                : [[[a[0], a[1], z], [b[0], b[1], z], [b[0], b[1], ground_z], [a[0], a[1], ground_z]],
                   [[0, 1, 2, 3]]]];
```

Replace the existing `_tile_from_islands()` (`modules/decoration.scad:231-250`):

```openscad
// islands: list of [region, height]. reverse=true is "normals up" here for the
// same measured reason _teardrop_tile() documents. ground_z (default 0) is
// the Z of the background/ground plane AND every wall's lower edge -- see
// _tile_walls()'s own comment for why this needed a real conditional, not
// just a parameter rename, once alternating mode introduced islands below
// their own ground plane.
function _tile_from_islands(islands, ground_z = 0) =
    let (
        all     = [for (il = islands) [intersection(force_region(il[0]), [_UNIT_TILE]), il[1]]],
        clipped = [for (c = all) if (len(c[0]) > 0) c],
        ground  = difference([_UNIT_TILE], union([for (c = clipped) c[0]]))
    )
    vnf_merge_points(_tile_quantize(vnf_join(concat(
        [vnf_from_region(ground, transform = up(ground_z), reverse = true)],
        [for (c = clipped) vnf_from_region(c[0], transform = up(c[1]), reverse = true)],
        // region_parts() is the only thing that guarantees a winding: the
        // region booleans above hand back paths in whatever direction fell
        // out of the clip, and a wall built on a backwards path faces into
        // the island instead of out of it (BOSL2 reports it as "faces
        // reverse across edge", OpenSCAD as an unclosed mesh). region_parts()
        // normalises to clockwise outers and counter-clockwise holes; reverse
        // flips that to the outward-facing convention _tile_walls() expects.
        [for (c = clipped) for (part = region_parts(c[0])) for (p = part)
            each _tile_walls(reverse(p), c[1], ground_z)]))));
```

This is a pure generalization: every existing call site (`_tumbling_cubes_tile()`, `_rhombille_tile()`, `_cairo_pentagonal_tile()`, `_teardrop_tile()` does NOT use this -- it has its own hand-rolled assembly -- `_tetrakis_square_tile()`, `_kisrhombille_tile()`, `_triakis_triangular_tile()`, `_floret_pentagonal_tile()`, `_deltoidal_trihexagonal_tile()`, `_intertwine_tile()`, `_islamic_star_tile()`) calls `_tile_from_islands(islands)` with one argument, so `ground_z` defaults to `0` and produces byte-identical output to before.
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

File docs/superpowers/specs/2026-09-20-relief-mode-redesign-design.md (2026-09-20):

# Relief Mode Redesign: True Outline Etching + New "Alternating" Mode

## Problem

`relief_mode` currently has two values, `"raised"` and `"etched"`, but `"etched"`
does not do what was originally wanted for most patterns. The original intent
(TODO.md): etched should read as a design *engraved into stone or glass* — the
wall stays flat, and only a thin incised line traces each motif's outline.

That is only true today for `"ridges"`, `"pyramids"`, `"diamonds"` (and
`"hex_grid"`/`"tri_grid"`, which shift the same panel/groove relief inward).
Every other pattern's `"etched"` instead sinks the *whole* motif as a recessed
copy of the raised relief:

- `"rhombille"`, `"cairo_pentagonal"`, `"tumbling_cubes"`, `"islamic_star"`,
  `"teardrop"`, `"intertwine"`: a true inverted copy of the entire raised
  motif (or, for `"teardrop"`/`"intertwine"`, no separate etched geometry at
  all beyond `tex_inset`).
- The "kis" family (`"tetrakis_square"`, `"kisrhombille"`, `"triakis_triangular"`)
  and `"floret_pentagonal"`: a separate flat-panel VNF with a thin groove
  *between* sub-facets — closer to the outline idea, but the groove traces
  internal facet boundaries, not the motif's outer silhouette.
- `"dots"`, `"cubes"`, `"checkers"`, `"bricks"` (BOSL2-native heightfields):
  sink into a dimple, same as the first group.

Separately, Barrett wants a genuinely new visual option: a relief where the
pattern alternates between raised (proud of the wall) and sunk (recessed into
the wall) in a single render, rather than uniformly one or the other. This is
being added as a **third `relief_mode` value**, not folded into `"raised"` —
`"raised"`'s existing look must not change for anyone with a saved design.

## Goals

1. `"raised"` — **unchanged**. No pattern's raised geometry changes.
2. `"etched"` — reworked so each of the 8 Phase-1 patterns (`tumbling_cubes`,
   `islamic_star`, `tetrakis_square`, `kisrhombille`, `triakis_triangular`,
   `rhombille`, `cairo_pentagonal`, `floret_pentagonal`) reads as a true
   engrave: flat wall, a groove around each motif's *outer* silhouette,
   plus — where a motif has real internal sub-facet structure (the "kis"
   family's fan triangles, `floret_pentagonal`'s rosette blades,
   `tumbling_cubes`'/`rhombille`'s multi-rhombus hexagons,
   `cairo_pentagonal`'s multi-pentagon placements) — a second, visually
   secondary groove tracing those internal boundaries too, thinner and/or
   shallower than the outer-silhouette groove so the two read as a clear
   hierarchy (motif outline first, internal detail second), not a wash of
   equally-weighted lines. No whole-shape inversion, ever. `intertwine`'s
   existing etched behavior stays unchanged (see "Per-pattern
   classification" below); `teardrop` is excluded from both new modes
   entirely (no islands list); `dots`/`cubes`/`checkers`/`bricks` are
   deferred to Phase 2.
3. `"alternating"` (new) — bas-relief: within one tile, some copies of the
   motif sit above the nominal wall surface and others sit below it, in a
   single render (not achieved by unioning separate raised/etched passes).
4. Every existing pattern keeps working; patterns that cannot support a mode
   cleanly say so via an assertion, not silently wrong geometry.

## Background: what BOSL2 actually allows

Two facts, confirmed against the real BOSL2 source (`lib/BOSL2/skin.scad`),
that shape every choice below:

- **BOSL2 always stamps the same tile content at every repeat position.**
  `_textured_point_array()`'s repeat loop closes over one `vnf`/`texture`
  value and transforms it identically at every `(x, y)` grid cell — there is
  no way to make BOSL2 alternate between two different tiles across repeats.
  Any alternation has to be baked into the *content of one tile*, the same
  trick BOSL2's own `"checkers"` catalog texture already uses (one `[0,1]`
  tile contains a 2x2 mini-checkerboard, not two tiles swapped at the grid
  level). This project's own custom tiles already do the analogous thing for
  other reasons — `_tumbling_cubes_tile()`/`_rhombille_tile()` pack 5 hexagon
  copies into one unit tile via `_TC_CENTERS`, `_cairo_pentagonal_tile()`
  packs 8 pentagon placements, etc.
- **`tex_inset` is a real scalar reference point, not just a boolean**, and
  the height formula is linear per vertex around it:
  `_tex_height(scale, inset, z) = (z - inset) * scale` (for `scale >= 0`).
  BOSL2 does not clamp a tile's Z to `[0,1]` anywhere (`_validate_texture`
  only checks X/Y) — that range is this project's own convention. Since the
  formula is linear and independent per vertex, a tile whose Z values
  straddle `inset` (e.g. `inset = 0.5`, some vertices at `z = 1`, others at
  `z = 0`) renders **both** raised bumps (`z > inset`) **and** sunk dimples
  (`z < inset`) in one `cyl(texture = ...)` call. No boolean union/difference
  workaround is needed for `"alternating"`.

These two facts are why both new modes are implementable as *pure tile
construction* changes: `decorated_solid()`'s single `cyl(texture = ...)` call
stays the architecture: only what a pattern's tile function returns, and what
`tex_inset` is set to, differ per mode.

## Design

### Shared infrastructure: two new tile builders alongside `_tile_from_islands()`

10 of this project's 11 custom VNF tiles (`tumbling_cubes`, `intertwine`,
`islamic_star`, `tetrakis_square`, `kisrhombille`, `triakis_triangular`,
`rhombille`, `cairo_pentagonal`, `floret_pentagonal`, `deltoidal_trihexagonal`)
are already built as a list of `[region, height]` islands, fed to
`_tile_from_islands()`. (`deltoidal_trihexagonal` merged into `main` after
this spec was first drafted — it's a Fable-researched kite tessellation with
uniform height and no `relief_mode` distinction, so it's included in this
infrastructure inventory but is out of scope for Phase 1's `"etched"`/
`"alternating"` work the same way `intertwine` is, just for a different
reason: it has no mode split to rework at all, not an unsupported geometry
problem — Task 1 should leave it untouched, same as `intertwine`.) But that
*already-built* islands list is **not** directly reusable as input to either
new builder — see the two corrections below, both confirmed against the real
code and both real enough to change the shape of this section:
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

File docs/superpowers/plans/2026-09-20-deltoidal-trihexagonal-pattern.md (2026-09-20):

# Deltoidal Trihexagonal Tiling Pattern Implementation Plan

> **For agentic workers:** REQUIRED SUB-SKILL: Use superpowers:subagent-driven-development (recommended) or superpowers:executing-plans to implement this plan task-by-task. Steps use checkbox (`- [ ]`) syntax for tracking.

**Goal:** Add `"deltoidal_trihexagonal"` as a new `pattern_type` -- the deltoidal trihexagonal tiling (Wikipedia "V3.4.6.4", the dual of the rhombitrihexagonal tiling), a tessellation by congruent kite/deltoid quadrilaterals. Each kite has two short edges and two long edges (verified below: ratio exactly `sqrt(3)/(sqrt(3)-1)`-family, not 1, so it is genuinely a kite and not a rhombus) and is NOT symmetric under the "kis" family's or `floret_pentagonal`'s single-rosette decision framework in the simple way those patterns were: this tiling's kites simultaneously belong to a 6-fan (around the tiling's hexagon-derived vertices), a 4-fan (around its square-derived vertices), and a 3-fan (around its triangle-derived vertices) all at once, since every kite touches one vertex of each type plus a fourth (repeated) square-derived vertex. See "Relief Mode Decision" below for why this leads to a **mode-independent, uniform-height** recommendation (like `rhombille`/`cairo_pentagonal`), not an alternating one (like `floret_pentagonal`/the "kis" family).
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

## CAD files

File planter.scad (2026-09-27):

// planter.scad
include <lib/BOSL2/std.scad>
include <modules/insert.scad>
include <modules/insert_presets.scad>
include <modules/body.scad>
include <modules/decoration.scad>
include <modules/base.scad>

// A caller can't override these via pre-assignment + include: OpenSCAD
// flattens repeated top-level assignments to the last one, even under
// is_undef() guards. These are just this file's fixed defaults.

/* [Insert Dimensions] */
insert_preset = "custom"; // ["custom:Custom (set fields below)", "small:Small (100x85 / 75mm bottom)", "medium:Medium (130x120 / 100mm bottom)", "large:Large (180x160 / 125mm bottom)"]
insert_top_d = 150;     // top rim diameter (mm) -- used when insert_preset == "custom"
insert_bottom_d = 110;  // bottom diameter (mm) -- used when insert_preset == "custom"
insert_height = 130;    // insert height (mm) -- used when insert_preset == "custom"

// Internal only -- not a Customizer field. Hidden so the resolved values
// (derived from insert_preset, not user-editable themselves) don't show up
// as bogus extra widgets in the Customizer GUI.
/* [Hidden] */
// Some OpenSCAD Customizer builds deviate from the documented "value:Label"
// dropdown behavior and store the whole label string (e.g.
// "medium:Medium (130x120 / 100mm bottom)") instead of just "medium" -- seen
// in the wild, not reproducible by editing this file directly. Strip
// anything from the first ":" onward so lookups below are robust to that.
_insert_preset_key = str_split(insert_preset, ":")[0];
_resolved_insert_top_d    = (_insert_preset_key == "custom") ? insert_top_d    : _insert_preset_dims(_insert_preset_key)[0];
_resolved_insert_bottom_d = (_insert_preset_key == "custom") ? insert_bottom_d : _insert_preset_dims(_insert_preset_key)[1];
_resolved_insert_height   = (_insert_preset_key == "custom") ? insert_height   : _insert_preset_dims(_insert_preset_key)[2];

/* [Fit] */
ledge_engagement_height = 8; // depth of the rim's tight-fit seat (mm)
ledge_ramp_height = 2;       // height over which the seat narrows to its tight clearance, instead of as a hard step (mm); 0 = hard step
fit_clearance = 0.3;         // radial clearance at the rim seat (mm)
body_clearance = 3;          // radial clearance around the tapered insert body (mm)
bottom_margin = 5;           // air gap below the insert's bottom (mm)

/* [Outer Shape] */
outer_mode = "follow"; // ["follow", "custom"]
wall_thickness = 3;     // used in follow mode (mm)
outer_top_d = 172;      // used in custom mode (mm)
outer_bottom_d = 130;   // used in custom mode (mm)
outer_height = 145;     // used in custom mode (mm)

/* [Decoration] */
pattern_type = "ridges";           // ["none", "ridges", "diamonds", "hex_grid", "pyramids", "bricks", "checkers", "dots", "cubes", "tri_grid", "teardrop", "tumbling_cubes", "intertwine", "islamic_star", "tetrakis_square", "kisrhombille", "triakis_triangular", "rhombille", "cairo_pentagonal", "floret_pentagonal", "deltoidal_trihexagonal"]
pattern_orientation = "vertical";  // ["vertical", "horizontal"]
relief_mode = "raised";            // ["raised", "etched", "alternating"]
pattern_depth = 1.5;    // mm
pattern_repeat = 16;    // tile count around circumference

/* [Base] */
floor_thickness = 3;              // mm
drainage_holes_enabled = false;    // add drainage holes to the solid floor
drainage_hole_count = 6;
drainage_hole_diameter = 4;

/* [Quality] */
smoothness = 60; // $fn used for all revolved geometry -- 80 CGAL-aborts "tumbling_cubes" after the square-tile fix; see README.md

assert(in_list(_insert_preset_key, concat(["custom"], INSERT_PRESET_NAMES)),
    str("insert_preset must be \"custom\" or one of ", INSERT_PRESET_NAMES, ", got \"", _insert_preset_key, "\""));
assert(_resolved_insert_bottom_d < _resolved_insert_top_d,
    "insert_bottom_d must be smaller than insert_top_d (insert tapers inward)");
assert(wall_thickness > 0, "wall_thickness must be > 0");
assert(ledge_ramp_height >= 0 && ledge_ramp_height <= ledge_engagement_height,
    str("ledge_ramp_height must be between 0 and ledge_engagement_height (",
        ledge_engagement_height, "), got ", ledge_ramp_height));
assert(outer_mode == "follow" || outer_mode == "custom",
    str("outer_mode must be \"follow\" or \"custom\", got \"", outer_mode, "\""));
assert(in_list(pattern_type, PATTERN_TYPES),
    str("pattern_type must be one of ", PATTERN_TYPES, ", got \"", pattern_type, "\""));
// Depends on pattern_type already being valid, so it must come after the
// pattern_type assert above -- otherwise an invalid pattern_type combined
// with an out-of-range pattern_depth would report the depth error first
// and never surface the accepted pattern_type list.
assert(pattern_depth < wall_thickness * 0.7 || pattern_type == "none",
    "pattern_depth must be < 70% of wall_thickness");

pot_height = insert_cavity_height(_resolved_insert_height, floor_thickness, bottom_margin);

assert(outer_mode != "custom" || outer_height >= pot_height,
    str("outer_height (", outer_height, ") must be >= required cavity height (", pot_height, ") in custom mode"));

// Radial containment check for custom mode: the outer profile's linear taper
// must clear the cavity (plus wall_thickness) everywhere. cavity_radius_at is
// constant below insert_bottom_z, linear between insert_bottom_z and
// ledge_bottom_z, then linear again (narrowing to the tight seat) between
// ledge_bottom_z and ledge_ramp_z, then constant above that, so the
// difference (outer_r - cavity_r) is piecewise linear too -- its minimum on
// each sub-interval falls at an endpoint, giving five breakpoints to check:
// the cavity's own floor (z=floor_thickness), the insert's physical bottom
// (insert_bottom_z), the ledge's loose-side bulge, where the seat ramp
// finishes narrowing, and the tight-fit rim.
// The cavity is translated up by z_offset in custom mode, so each breakpoint
// lands at (breakpoint + z_offset) in the outer body's own z coordinates.
_insert_bottom_z = pot_height - _resolved_insert_height;
_ledge_bottom_z = pot_height - ledge_engagement_height;
_ledge_ramp_z = _ledge_bottom_z + ledge_ramp_height;
_custom_z_offset = outer_height - pot_height;
_outer_r_at = function (z) outer_bottom_d/2 + (outer_top_d/2 - outer_bottom_d/2) * (z / outer_height);
_custom_breakpoints = [
    [floor_thickness, "the cavity floor"],
    [_insert_bottom_z, "the insert's bottom"],
    [_ledge_bottom_z, "the ledge bulge"],
    [_ledge_ramp_z, "the ledge ramp's tight end"],
    [pot_height, "the rim"],
];
for (bp = _custom_breakpoints) {
    _z = bp[0];
    _label = bp[1];
    _r_cavity = cavity_radius_at(_z, _resolved_insert_top_d, _resolved_insert_bottom_d, _resolved_insert_height,
        ledge_engagement_height, fit_clearance, body_clearance, pot_height, ledge_ramp_height=ledge_ramp_height);
    _z_outer = _z + _custom_z_offset;
    assert(outer_mode != "custom" || _outer_r_at(_z_outer) >= _r_cavity + wall_thickness,
        str("custom outer profile is too thin at ", _label, " (z=", _z_outer,
            "): has radius ", _outer_r_at(_z_outer), ", needs >= ", _r_cavity + wall_thickness));
}

// Initial Customizer/GUI preview camera. OpenSCAD only applies $vpt/$vpr/
// $vpd the first time a file is opened (or after "View > Reset View"), so
// this doesn't fight a user's own framing once they've adjusted it -- it
// only fixes the *first* view, which otherwise crops the pot for anything
// but the smallest insert sizes. The diameter estimate is deliberately
// generous rather than the exact peak radius planter() computes below
// (which depends on pattern_type): a bit of extra headroom around the pot
// is harmless, a clipped one isn't.
_preview_height = (outer_mode == "custom") ? outer_height : pot_height;
_preview_diameter = (outer_mode == "custom") ? max(outer_top_d, outer_bottom_d)
    : (_resolved_insert_top_d + 2 * (wall_thickness + body_clearance + 5));
$vpt = [0, 0, _preview_height / 2];
$vpr = [55, 0, 25];
$vpd = max(_preview_diameter, _preview_height) * 4;
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

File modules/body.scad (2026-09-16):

// modules/body.scad
include <insert.scad>

// ledge_ramp_height is appended after the pre-existing optional fn, not
// inserted before it: a caller using the old positional arity -- a 10th
// positional argument meant as fn -- must keep landing on fn, not silently
// be reinterpreted as the new parameter (which would both change the
// profile and leave fn at its default, silently altering mesh resolution
// too).
module outer_body_follow(insert_top_d, insert_bottom_d, insert_height,
                          ledge_engagement_height, fit_clearance, body_clearance,
                          bottom_margin, floor_thickness, wall_thickness, fn=50,
                          ledge_ramp_height=0) {
    pot_height = insert_cavity_height(insert_height, floor_thickness, bottom_margin);
    insert_bottom_z = pot_height - insert_height;
    ledge_bottom_z  = pot_height - ledge_engagement_height;
    ledge_ramp_z    = ledge_bottom_z + ledge_ramp_height;

    // Same breakpoints insert_cavity() uses, each offset outward by wall_thickness.
    // The cavity profile is piecewise linear between these z values, so linear
    // interpolation between exact-breakpoint points here is exact everywhere,
    // not just at sampled points.
    r_floor        = cavity_radius_at(floor_thickness, insert_top_d, insert_bottom_d,
                                       insert_height, ledge_engagement_height, fit_clearance,
                                       body_clearance, pot_height, ledge_ramp_height) + wall_thickness;
    r_insert_bot   = cavity_radius_at(insert_bottom_z, insert_top_d, insert_bottom_d,
                                       insert_height, ledge_engagement_height, fit_clearance,
                                       body_clearance, pot_height, ledge_ramp_height) + wall_thickness;
    r_ledge_lower  = cavity_radius_at(ledge_bottom_z, insert_top_d, insert_bottom_d,
                                       insert_height, ledge_engagement_height, fit_clearance,
                                       body_clearance, pot_height, ledge_ramp_height) + wall_thickness;
    r_ledge_upper  = insert_top_d/2 + fit_clearance + wall_thickness;

    pts = [
        [0, 0],
        [r_floor, 0],
        [r_floor, floor_thickness],
        [r_insert_bot, insert_bottom_z],
        [r_ledge_lower, ledge_bottom_z],
        [r_ledge_upper, ledge_ramp_z],
        [r_ledge_upper, pot_height],
        [0, pot_height]
    ];
    rotate_extrude($fn=fn) polygon(pts);
}

module outer_body_custom(outer_top_d, outer_bottom_d, outer_height, pot_height, fn=50) {
    assert(outer_height >= pot_height,
        str("outer_height (", outer_height, ") must be >= required cavity height (", pot_height, ")"));
    pts = [
        [0, 0],
        [outer_bottom_d/2, 0],
        [outer_top_d/2, outer_height],
        [0, outer_height]
    ];
    rotate_extrude($fn=fn) polygon(pts);
}

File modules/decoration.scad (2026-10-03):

// modules/decoration.scad
include <../lib/BOSL2/std.scad>

// PATTERN_TYPES doubles as the Customizer's valid-value list and the lookup
// table for _decoration_texture(). Most entries are literal BOSL2 texture
// names (see the texture() catalog in lib/BOSL2/skin.scad) and map to
// themselves; the exceptions are "none" (no texture at all), "ridges" (an
// alias for BOSL2's "ribs"), and the eleven custom VNF tiles built below --
// the eight interlocking patterns ("teardrop", "tumbling_cubes",
// "intertwine", "islamic_star", "rhombille", "cairo_pentagonal",
// "floret_pentagonal", "deltoidal_trihexagonal" -- rhombille is the plain
// rhombille tiling tumbling_cubes' own isometric illusion is built from,
// cairo_pentagonal is the Cairo pentagonal tiling, floret_pentagonal is the
// floret pentagonal tiling, and deltoidal_trihexagonal is the deltoidal
// trihexagonal tiling (kite motif); all genuinely cross the tile boundary
// like the other seven) and the three "kis" family patterns
// ("tetrakis_square", "kisrhombille", "triakis_triangular") -- which are not
// BOSL2 textures at all. "floret_pentagonal" straddles those two groups: it
// interlocks across the seam like the first group, but its 6-pentagon
// rosette is a fan with real sub-structure, so like the "kis" family (and
// unlike every other interlocking pattern here, including
// "deltoidal_trihexagonal") its tile geometry depends on relief_mode. So
// _decoration_texture() returns
// either a string or a VNF, and callers must not assume a string. The mapping
// is also relief-mode dependent -- see _decoration_etched_texture().
PATTERN_TYPES = ["none", "ridges", "diamonds", "hex_grid", "pyramids",
                 "bricks", "checkers", "dots", "cubes", "tri_grid",
                 "teardrop", "tumbling_cubes", "intertwine", "islamic_star",
                 "tetrakis_square", "kisrhombille", "triakis_triangular",
                 "rhombille", "cairo_pentagonal", "floret_pentagonal",
                 "deltoidal_trihexagonal"];

// RELIEF_MODES is a SEPARATE list from PATTERN_TYPES on purpose:
// PATTERN_TYPES lists pattern NAMES (what _decoration_texture() looks up),
// and "alternating" is not a pattern name -- adding it to PATTERN_TYPES
// would make pattern_type="alternating" look like a valid Customizer
// selection and fall through to an unresolved texture.
RELIEF_MODES = ["raised", "etched", "alternating"];

// The patterns whose tile function actually branches on "alternating" and
// whose islands-building loop tags group_id/alt_key for
// _tile_alternating_from_islands().
//
// GROWTH INVARIANT: this list must only ever contain patterns that are
// already wired. Each phase appends its own newly-wired pattern name(s) as
// part of the same diff that adds the branch -- never ahead of it. Listing a
// pattern early is worse than omitting it: the assertion in decorated_solid()
// would pass, _decoration_texture() would fall through to that pattern's
// raised tile, and tex_inset would still be 0.5, rendering a raised tile
// half-sunk into the wall rather than either bas-relief or a clean raised
// fallback -- exactly the silent wrong-geometry failure the Global
// Constraints forbid. Omitting a wired pattern only costs a loud, accurate
// assertion. All 8 Phase-1 patterns are wired now. teardrop and intertwine
// are excluded outright (different reasons -- see the Global Constraints);
// deltoidal_trihexagonal has no relief_mode split at all; the four
// BOSL2-native heightfield patterns (dots/cubes/checkers/bricks) and the
// five flat-top/V-groove patterns (ridges/pyramids/diamonds/hex_grid/tri_grid)
// are Phase 2 or out of scope.
ALTERNATING_PATTERNS = ["islamic_star", "kisrhombille", "tumbling_cubes", "rhombille", "tetrakis_square", "triakis_triangular", "cairo_pentagonal", "floret_pentagonal"];

// Excluded from the square-tile correction: "none" has no texture at all;
// "ridges" is a directional stripe pattern with no discrete shape to square.
// "bricks" used to be excluded too, on the theory that it should stay
// rectangular rather than square -- but that was backwards: BOSL2's
// "bricks" heightfield already bakes a 2:1 brick shape into its own tile
// (one full-width brick plus two half-width bricks, each exactly half the
// tile's height), so a SQUARE cell is what reproduces that 2:1 brick. Opting
// out instead pinned the cell's own aspect to the wall's fixed
// circumference:height ratio (~3.2:1 at defaults), which compounded with
// the tile's built-in 2:1 into ~6.4:1 bricks that no pattern_repeat value
// could fix, since that ratio never depended on pattern_repeat.
_ASPECT_EXCLUDED_PATTERNS = ["none", "ridges"];

// BOSL2's own documentation (lib/BOSL2/skin.scad texture catalog comments)
// says these three need an additional sqrt(3) Y-scale for correct aspect:
// "cubes" for a true isometric-cube look, "hex_grid"/"tri_grid" so their
// V-groove border width is uniform on every side of the hexagon/triangle
// (regular hexagons/triangles, not stretched ones).
_ASPECT_SQRT3_PATTERNS = ["cubes", "hex_grid", "tri_grid"];

// decorated_solid() used to pass the same pattern_repeat for both the horizontal
// (circumferential) and vertical tex_reps, which only produces square tiles
// by coincidence: the wall's average circumference (~440mm at defaults) is
// nothing like its height (~138mm). This derives the vertical repeat count
// from the real geometry instead, so tiles come out approximately square
// (only approximately, since the wall is a cone: BOSL2 scales each texture
// strip to the LOCAL radius, so a single vertical_reps can only be exact at
// one radius -- see README.md's "Decoration" section for the residual
// taper effect this leaves).
//
// The custom VNF tiles (teardrop, tumbling_cubes, intertwine, islamic_star,
// tetrakis_square, kisrhombille, triakis_triangular, rhombille,
// cairo_pentagonal, floret_pentagonal, deltoidal_trihexagonal) are built on
// _UNIT_TILE, confirmed
// elsewhere in this file to be exactly the unit square with no intrinsic
// distortion, so they use the plain formula like every BOSL2 catalog texture
// without a documented sqrt(3) requirement.
function _square_tile_vertical_reps(pattern_type, pattern_orientation, pattern_repeat, r1, r2, height) =
    in_list(pattern_type, _ASPECT_EXCLUDED_PATTERNS) ? pattern_repeat :
    let(
        avg_circumference = PI * (r1 + r2),
        is_sqrt3 = in_list(pattern_type, _ASPECT_SQRT3_PATTERNS),
        // BOSL2 rotates the TILE'S OWN CONTENT by 90 degrees for tex_rot=90
        // (this project's "horizontal" pattern_orientation) -- see
        // lib/BOSL2/skin.scad's _get_texture(), which applies zrot(90,...)
        // for VNF textures (cubes/hex_grid/tri_grid all return VNF data) or
        // an equivalent transpose for heightfields. tex_reps' own axes stay
        // tied to the SURFACE (circumferential, vertical) regardless of
        // tex_rot -- BOSL2 does not swap tex_reps' meaning. So a texture
        // whose intrinsic Y needs to be sqrt(3) times its intrinsic X has
        // that requirement land on the surface's vertical axis normally,
        // but on the surface's circumferential axis once rotated -- and
        // since tex_reps[0] (circumferential) stays pinned to the
        // user-facing pattern_repeat either way, the correction flips from
        // dividing vertical_reps by sqrt(3) to multiplying it.
        aspect_correction = !is_sqrt3 ? 1
            : (pattern_orientation == "horizontal") ? (1 / sqrt(3)) : sqrt(3)
    )
    max(1, round(pattern_repeat * height / (avg_circumference * aspect_correction)));
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

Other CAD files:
modules/base.scad
modules/insert.scad
modules/insert_presets.scad
tests/test_base.scad
tests/test_body.scad
tests/test_body_custom_assert.scad
tests/test_bosl2_texture_smoke.scad
tests/test_decoration.scad
tests/test_decoration_cairo_pentagonal.scad
tests/test_decoration_deltoidal_trihexagonal.scad
tests/test_decoration_depth_assert.scad
tests/test_decoration_etched_groove.scad
tests/test_decoration_floret_pentagonal.scad
tests/test_decoration_intertwine.scad
tests/test_decoration_invalid_alternating_pattern.scad
tests/test_decoration_invalid_pattern_type.scad
tests/test_decoration_invalid_relief_mode.scad
tests/test_decoration_islamic_star.scad
tests/test_decoration_kisrhombille.scad
tests/test_decoration_pattern_types.scad
tests/test_decoration_rhombille.scad
tests/test_decoration_ridges.scad
tests/test_decoration_teardrop.scad
tests/test_decoration_tetrakis_square.scad
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

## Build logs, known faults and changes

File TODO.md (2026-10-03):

* [x] Preset insert sizes: 100x85 (75mm bottom); 130x120 (100mm bottom); 180x160 (125mm bottom)
* [x] Add interlocking teardrop (from BOSL2)
* [x] I like the way shapes are raised. I don't know what etched does. I wanted it to have an engraved look - like it was etched into stone or glass.
* [x] I would love to include interlocking geometric patterns. I saved some examples to the Desktop. More: https://www.magnific.com/free-photos-vectors/geometric-interlocking-pattern
* [x] Include example images in the README
* [ ] More interlocking geometric pattern ideas (planar Euclidean uniform tilings, not spherical/hyperbolic) -- see https://en.wikipedia.org/wiki/List_of_Euclidean_uniform_tilings, https://en.wikipedia.org/wiki/Uniform_tiling, https://en.wikipedia.org/wiki/List_of_tessellations. In progress, batched 2-3 at a time:
  - The 11 Euclidean uniform tilings exhaust the edge-to-edge regular/semiregular options: triangular, square, hexagonal, truncated square, snub square, trihexagonal, truncated hexagonal, rhombitrihexagonal, truncated trihexagonal, snub trihexagonal, elongated triangular.
  - Their duals add visually distinct candidates, especially good fits for the Islamic/Escher interlocking aesthetic:
    - [x] Tetrakis square tiling ("V4.8^2") -- batch 1, shares a "kis" (centroid-fan) helper with Kisrhombille and Triakis triangular
    - [x] Kisrhombille tiling ("V4.6.12") -- batch 1, reuses tumbling_cubes' existing hexagon/rhombus math
    - [x] Triakis triangular tiling ("V3.12^2") -- batch 1
    - [x] Rhombille tiling ("V3.6.3.6", diamond/rhombus motif) -- batch 2, reuses tumbling_cubes' hexagon math directly
    - [x] Cairo pentagonal tiling ("V3^2.4.3.4", distinctive interlocking pentagons -- probably the most visually striking one) -- batch 2
    - [x] Floret pentagonal tiling ("V3^4.6", pinwheel-like pentagon clusters) -- batch 3
    - [x] Deltoidal trihexagonal tiling ("V3.4.6.4", kite-shaped motif) -- batch 3
  - (Excluded on purpose: the apeirogonal hosohedron/order-2 apeirogonal tiling and their prism/antiprism/dual variants from the same Wikipedia list -- these involve infinite-sided polygons and aren't practical decorative motifs for a finite tile. Also excluded: Prismatic pentagonal tiling ("V3^3.4^2") -- fully researched and computationally verified (see docs/superpowers/plans/2026-09-19-prismatic-pentagonal-pattern.md), but its natural translation lattice is oblique, requiring a shear to normalize to this project's unit-square tile convention. Since this codebase's only aspect-correction mechanism can adjust a repeat count but never a repeat angle, shipping it would bake a permanent, uncorrectable diagonal slant into the motif -- declined for that reason, not a math or implementation failure.)
* [x] "etched" doesn't do what was originally wanted for most patterns -- the goal was
  the outline of each shape engraved into the planter (flat surface, thin incised line
  tracing the motif), like it was etched into stone or glass. That's only actually true
  for "ridges"/"pyramids"/"diamonds" (and "hex_grid"/"tri_grid", which shift the same
  panel/groove relief inward) -- those keep a flat panel and cut a thin V-groove along
  the outline. Every other pattern's "etched" instead sinks the WHOLE shape as a
  recessed copy of the raised relief (a dimple/recess, or for "rhombille"/
  "cairo_pentagonal"/"tumbling_cubes"/"islamic_star" a true inverted copy of the entire
  raised motif, not just its outline; the "kis" family and "floret_pentagonal" are a
  third case -- a separate flat panel with only a thin groove BETWEEN facets, which is
  closer to the outline idea but traces facet boundaries within the motif, not the
  motif's own outer silhouette). Needs a real design pass on what "etched" should mean
  for each pattern family, not just the current mode-independent-vs-mode-dependent
  split -- possibly a genuine third relief style (flat wall + thin V-groove along each
  motif's outer boundary only) distinct from both "raised" and the current "etched".
* [ ] Phase 2 of the etched/alternating relief-mode redesign: convert "dots",
  "cubes", "checkers", "bricks" from BOSL2-native heightfields into custom
  islands-based VNF tiles of our own (each is a small, well-understood shape
  -- a circle, an isometric rhombus pair, a 2x2 checker split, a brick
  rectangle), so they can plug into _tile_outline_from_islands()/
  _tile_alternating_from_islands() the same way the other 8 patterns now do.
  "raised" mode for these four is unaffected either way -- only "etched"/
  "alternating" depend on the conversion. See
  docs/superpowers/specs/2026-09-20-relief-mode-redesign-design.md's own
  "Phase 2" section.
* [x] "bricks" pattern_type looks like a basket weave (too square/wide per brick), especially at lower pattern_repeat -- actual root cause: "bricks" was in `_ASPECT_EXCLUDED_PATTERNS`, on the theory it should stay rectangular rather than square. That was backwards: BOSL2's "bricks" heightfield already bakes a 2:1 brick into its own tile (one full-width brick, two half-width bricks, each exactly half the tile's height), so a SQUARE cell is what reproduces that 2:1 brick -- opting out instead pinned the cell's own aspect to the wall's fixed circumference:height ratio (~3.2:1 at defaults), compounding with the tile's built-in 2:1 into ~6.4:1 bricks that no pattern_repeat value could fix. Fixed by moving "bricks" into the plain square-tile-formula group alongside "dots"/"checkers".

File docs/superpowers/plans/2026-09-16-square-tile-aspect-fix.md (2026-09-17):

# Square-Tile Aspect Fix Implementation Plan

> **For agentic workers:** REQUIRED SUB-SKILL: Use superpowers:subagent-driven-development (recommended) or superpowers:executing-plans to implement this plan task-by-task. Steps use checkbox (`- [ ]`) syntax for tracking.

> **Post-implementation note:** this plan is committed as a historical record of the design process (matching this repo's convention for prior plans, e.g. `2026-09-12-parametric-planter.md` — plans are not rewritten or checkbox-updated after the fact). The final whole-branch review found a real gap this plan's Task 1 didn't anticipate: `_square_tile_vertical_reps()`'s sqrt(3) correction needs to apply to a different axis depending on `pattern_orientation`, because BOSL2 rotates the texture tile's own content for `pattern_orientation="horizontal"`. The function's shipped signature is `_square_tile_vertical_reps(pattern_type, pattern_orientation, pattern_repeat, r1, r2, height)` — one more parameter than Task 1's interface/code below shows — and the shipped formula's `aspect_correction` is `sqrt(3)` for vertical orientation but `1/sqrt(3)` for horizontal, not the one-way `sqrt(3)` this plan documents. See `modules/decoration.scad` for the actual shipped implementation and its inline reasoning, not this file, if the two ever disagree.

**Goal:** Make every shape-based decoration pattern (everything except `"ridges"` and `"bricks"`, which are intentionally directional/rectangular) render with tiles that are the same dimension top-to-bottom as left-to-right on the actual printed pot, instead of the current ~2.8-3.75x horizontal stretch.

**Architecture:** `decorated_solid()` (`modules/decoration.scad`) currently hardcodes `tex_reps = [pattern_repeat, pattern_repeat]` for every pattern — the same repeat count around the circumference as up the height, regardless of the pot's actual circumference/height ratio (~440mm / ~138mm at defaults, a ~3.2x mismatch). Fix: compute the vertical repeat count from the real geometry (`r1`, `r2`, `height`, already passed into `decorated_solid()`) so each tile comes out approximately square, with three BOSL2 catalog patterns (`"cubes"`, `"hex_grid"`, `"tri_grid"`) needing an additional `sqrt(3)` correction per BOSL2's own documented aspect requirements (`lib/BOSL2/skin.scad` texture catalog comments) for their tiles to be true isometric cubes / regular hexagons / equilateral triangles rather than merely square. Because the wall is a cone, not a cylinder, tiles can only be made square *on average* (at the mean radius) — a smaller residual taper distortion remains and must be disclosed honestly, same as the existing docs already do for the current (much larger) distortion.

**Tech Stack:** OpenSCAD, BOSL2.

**Spec:** This plan's own Architecture section above is the spec — derived from TODO.md's "Fix tile aspect-ratio distortion on the actual pot" and "BOSL2 aspect-scale corrections not applied for some patterns" entries, and confirmed against `lib/BOSL2/skin.scad`'s texture catalog documentation (grep `sqrt(3)` in that file) and the `_tile_from_islands()` / `_UNIT_TILE` convention already used for the four custom VNF tiles (confirmed unit-square, no intrinsic correction needed).

## Global Constraints

- Scope is exactly the 11 shape-based patterns: `"diamonds"`, `"hex_grid"`, `"pyramids"`, `"checkers"`, `"dots"`, `"cubes"`, `"tri_grid"`, `"teardrop"`, `"tumbling_cubes"`, `"intertwine"`, `"islamic_star"`. `"none"` (no texture) and `"ridges"`/`"bricks"` (intentionally directional/rectangular) are explicitly OUT of scope and must keep their current `tex_reps = [pattern_repeat, pattern_repeat]` behavior unchanged — confirmed with the project owner, do not expand or narrow this list.
- No new Customizer field. `pattern_repeat` remains the only user-facing tiling control (horizontal/circumferential count); the vertical count becomes an internal derived value. Do not add a manual override — YAGNI, not requested.
- `"cubes"`, `"hex_grid"`, `"tri_grid"` need their vertical repeat count reduced by an additional factor of `sqrt(3)` relative to the plain square-tile formula, per BOSL2's own documentation (`lib/BOSL2/skin.scad` lines ~3735, ~3878-3888, ~3938-3944, ~3998-4004: "this texture needs to be scaled in vertically by sqrt(3) to have its correct aspect" for cubes; "If the texture is scaled in the Y direction by sqrt(3) then the groove is uniform on all six/three sides" for hex_grid/tri_grid).
- Vertical repeat count formula (verified against `_tile_from_islands()`'s unit-square convention and BOSL2's documented sqrt(3) requirement):
  - `avg_circumference = PI * (r1 + r2)` (r1 = bottom radius, r2 = top radius — averaging radii then computing circumference, i.e. `pi * d_avg`)
  - Plain square-tile patterns: `vertical_reps = max(1, round(pattern_repeat * height / avg_circumference))`
  - sqrt(3)-corrected patterns (`"cubes"`, `"hex_grid"`, `"tri_grid"`): `vertical_reps = max(1, round(pattern_repeat * height / (avg_circumference * sqrt(3))))`
  - Excluded patterns (`"none"`, `"ridges"`, `"bricks"`): `vertical_reps = pattern_repeat` (unchanged)
- All 14 pattern_types x 2 relief modes must still pass the full local CI-equivalent suite (`.github/workflows/test.yml`'s `scad-tests` job, extracted and run locally the same way prior PRs in this repo verified it — see `git log` on `docs/images/render.sh` commits for the exact extraction technique using `python3 -c "import yaml..."`) before any task in this plan is considered done. This includes the CGAL-fragile-pattern safety measurements for `"tumbling_cubes"`, `"intertwine"`, `"islamic_star"` — changing vertical tile counts changes tile geometry, so previously-measured "safe" `pattern_repeat`/`smoothness` combinations in `.github/workflows/test.yml` and README.md may no longer be accurate and must be re-measured, not assumed.
- Work happens in an isolated git worktree per this repo's established convention (see `superpowers:using-git-worktrees`); branch name should describe the fix (e.g. `square-tile-aspect`).

---

### Task 1: Implement the aspect-corrected vertical tile count

**Files:**
- Modify: `modules/decoration.scad` (add a helper function; change `decorated_solid()`'s `tex_reps` line)
- Test: `tests/test_decoration_tile_aspect.scad` (new file)

**Interfaces:**
- Produces: `_square_tile_vertical_reps(pattern_type, pattern_repeat, r1, r2, height)` — a function returning an integer >= 1, callable from `decorated_solid()` and from tests.
- Consumes: nothing new from other tasks (this is the first task).

- [ ] **Step 1: Write the failing tests**

Create `tests/test_decoration_tile_aspect.scad`:

```openscad
// tests/test_decoration_tile_aspect.scad
include <../modules/decoration.scad>

// Plain square-tile pattern ("dots"): vertical_reps should make each tile
// close to square at the average radius, i.e.
// round(pattern_repeat * height / (PI * (r1 + r2))).
r1 = 61;
r2 = 82.3;
height = 138;
pattern_repeat = 16;
avg_circ = PI * (r1 + r2);

v_dots = _square_tile_vertical_reps("dots", pattern_repeat, r1, r2, height);
expected_dots = round(pattern_repeat * height / avg_circ);
assert(v_dots == expected_dots,
    str("expected dots vertical_reps ", expected_dots, ", got ", v_dots));
assert(v_dots == 5, str("expected 5 at documented defaults, got ", v_dots));

// sqrt(3)-corrected pattern ("cubes"): same inputs must give a SMALLER
// vertical_reps than the plain formula, by a factor of sqrt(3) -- fewer,
// taller rows so each cube's height is physically sqrt(3) times its width,
// per BOSL2's own documented requirement for a correctly-proportioned
// "cubes" texture.
v_cubes = _square_tile_vertical_reps("cubes", pattern_repeat, r1, r2, height);
expected_cubes = round(pattern_repeat * height / (avg_circ * sqrt(3)));
assert(v_cubes == expected_cubes,
    str("expected cubes vertical_reps ", expected_cubes, ", got ", v_cubes));
assert(v_cubes < v_dots,
    "cubes vertical_reps must be smaller than the plain square-tile count (sqrt(3) correction)");

// hex_grid and tri_grid get the same sqrt(3) treatment as cubes.
v_hex = _square_tile_vertical_reps("hex_grid", pattern_repeat, r1, r2, height);
v_tri = _square_tile_vertical_reps("tri_grid", pattern_repeat, r1, r2, height);
assert(v_hex == expected_cubes, str("expected hex_grid vertical_reps ", expected_cubes, ", got ", v_hex));
assert(v_tri == expected_cubes, str("expected tri_grid vertical_reps ", expected_cubes, ", got ", v_tri));

// Excluded patterns keep vertical_reps == pattern_repeat regardless of the
// real geometry -- "ridges" is directional, "bricks" is intentionally
// rectangular.
v_ridges = _square_tile_vertical_reps("ridges", pattern_repeat, r1, r2, height);
v_bricks = _square_tile_vertical_reps("bricks", pattern_repeat, r1, r2, height);
assert(v_ridges == pattern_repeat, str("expected ridges vertical_reps ", pattern_repeat, ", got ", v_ridges));
assert(v_bricks == pattern_repeat, str("expected bricks vertical_reps ", pattern_repeat, ", got ", v_bricks));

// The four custom VNF tiles (built on _UNIT_TILE, confirmed unit-square, no
// intrinsic correction) use the plain formula, same as "dots".
for (pt = ["teardrop", "tumbling_cubes", "intertwine", "islamic_star", "diamonds", "pyramids", "checkers"]) {
    v = _square_tile_vertical_reps(pt, pattern_repeat, r1, r2, height);
    assert(v == expected_dots,
        str("expected ", pt, " vertical_reps ", expected_dots, ", got ", v));
}

// Minimum-1 clamp: a tall/thin custom outer shape (height >> circumference)
// must not compute a fractional or zero vertical_reps.
v_tall = _square_tile_vertical_reps("dots", 2, 10, 10, 500);
assert(v_tall >= 1, str("expected clamped vertical_reps >= 1, got ", v_tall));
assert(is_int(v_tall), "vertical_reps must be an integer");

cube(0.001);
```

- [ ] **Step 2: Run test to verify it fails**

Run: `openscad -o /tmp/test.csg tests/test_decoration_tile_aspect.scad`
Expected: FAIL — `_square_tile_vertical_reps` is not yet defined (ERROR: Unknown function).

- [ ] **Step 3: Implement `_square_tile_vertical_reps()` and wire it into `decorated_solid()`**

In `modules/decoration.scad`, add this function near the top (after `PATTERN_TYPES`, before the tile-builder functions):

```openscad
// Excluded from the square-tile correction: "none" has no texture at all;
// "ridges" is a directional stripe pattern with no discrete shape to square;
// "bricks" is intentionally rectangular, like real bricks.
_ASPECT_EXCLUDED_PATTERNS = ["none", "ridges", "bricks"];

// BOSL2's own documentation (lib/BOSL2/skin.scad texture catalog comments)
// says these three need an additional sqrt(3) Y-scale for correct aspect:
// "cubes" for a true isometric-cube look, "hex_grid"/"tri_grid" so their
// V-groove border width is uniform on every side of the hexagon/triangle
// (regular hexagons/triangles, not stretched ones).
_ASPECT_SQRT3_PATTERNS = ["cubes", "hex_grid", "tri_grid"];

// decorated_solid() passes the same pattern_repeat for both the horizontal
// (circumferential) and vertical tex_reps, which only produces square tiles
// by coincidence: the wall's average circumference (~440mm at defaults) is
// nothing like its height (~138mm). This derives the vertical repeat count
// from the real geometry instead, so tiles come out approximately square
// (only approximately, since the wall is a cone: BOSL2 scales each texture
// strip to the LOCAL radius, so a single vertical_reps can only be exact at
// one radius -- see README.md's "Decoration" section for the residual
// taper effect this leaves).
//
// The four custom VNF tiles (teardrop, tumbling_cubes, intertwine,
// islamic_star) are built on _UNIT_TILE, confirmed elsewhere in this file
// to be exactly the unit square with no intrinsic distortion, so they use
// the plain formula like every BOSL2 catalog texture without a documented
// sqrt(3)/sqrt(2) requirement.
function _square_tile_vertical_reps(pattern_type, pattern_repeat, r1, r2, height) =
    in_list(pattern_type, _ASPECT_EXCLUDED_PATTERNS) ? pattern_repeat :
    let(
        avg_circumference = PI * (r1 + r2),
        aspect_correction = in_list(pattern_type, _ASPECT_SQRT3_PATTERNS) ? sqrt(3) : 1
    )
    max(1, round(pattern_repeat * height / (avg_circumference * aspect_correction)));
```

Then in `decorated_solid()`, change:

```openscad
            tex_reps = [pattern_repeat, pattern_repeat],
```

to:

```openscad
            tex_reps = [pattern_repeat, _square_tile_vertical_reps(pattern_type, pattern_repeat, r1, r2, height)],
```

- [ ] **Step 4: Run test to verify it passes**

Run: `openscad -o /tmp/test.csg tests/test_decoration_tile_aspect.scad`
Expected: PASS (no ERROR in output, exit 0).

- [ ] **Step 5: Run the existing decoration/pattern test files to confirm nothing broke**

Run each of these and confirm clean (no ERROR, exit 0) — these exercise every pattern_type/relief_mode combination and will now render with different (corrected) tile counts, so this step catches any pattern whose VNF construction breaks at the new vertical_reps values before the slower full-assembly checks in Task 2:

```bash
openscad -o /tmp/t1.csg tests/test_decoration.scad
openscad -o /tmp/t2.csg tests/test_decoration_ridges.scad
openscad -o /tmp/t3.csg tests/test_decoration_pattern_types.scad
openscad -o /tmp/t4.csg tests/test_decoration_etched_groove.scad
for f in teardrop tumbling_cubes intertwine islamic_star; do
    openscad -o /tmp/t_$f.stl tests/test_decoration_$f.scad
done
```

If any of these fail, fix `_square_tile_vertical_reps()` or the affected tile builder before moving on — do not defer to Task 2.

- [ ] **Step 6: Commit**

```bash
git add modules/decoration.scad tests/test_decoration_tile_aspect.scad
git commit -m "Derive the vertical tile repeat count from real geometry so shape-based patterns render square instead of stretched"
```

---

### Task 2: Re-verify CGAL-fragile pattern safety and update CI/README's documented safe combinations

**Files:**
- Modify: `.github/workflows/test.yml` (the `run_assembly_combo` calls and reduced-value comments for `tumbling_cubes`/`intertwine`/`islamic_star`)
- Modify: `README.md` (the "Note on the interlocking patterns and CGAL" section, lines ~141-145)

**Interfaces:**
- Consumes: Task 1's `_square_tile_vertical_reps()` (already merged into `decorated_solid()`), no new interfaces of its own.
- Produces: nothing new; this task only re-validates and re-documents existing behavior.

- [ ] **Step 1: Extract and run the full CI script locally**

```bash
python3 -c "
import yaml
with open('.github/workflows/test.yml') as f:
    d = yaml.safe_load(f)
script = d['jobs']['scad-tests']['steps'][-1]['run']
with open('/tmp/run_ci.sh', 'w') as f:
    f.write('#!/usr/bin/env bash\n')
    f.write(script)
"
bash /tmp/run_ci.sh > /tmp/ci_local.log 2>&1; echo "EXIT:$?"
grep -c FAIL /tmp/ci_local.log
```

Expected: this MAY fail on the `tumbling_cubes`/`islamic_star` default-settings checks near the end (the ones pinned at `pattern_repeat=16`, `smoothness=80`) or on the reduced-value loop, since vertical tile counts changed. Read `/tmp/ci_local.log` around any `FAIL:` line to see which combination broke and whether it's a CGAL abort (look for `CGAL error` or `ERROR` in the surrounding output) or something else.

- [ ] **Step 2: Re-measure safe pattern_repeat/smoothness combinations for the three CGAL-fragile patterns**

If Step 1 found breakage, re-run the specific failing combination(s) directly to confirm the CGAL abort:

```bash
openscad -D 'pattern_type="tumbling_cubes"' -D 'relief_mode="etched"' -D 'pattern_repeat=16' -D 'smoothness=80' -o /tmp/probe.stl tests/test_planter_integration.scad 2>&1 | grep -i "CGAL error\|ERROR"
```

If it aborts, search nearby `pattern_repeat`/`smoothness` values (following the existing methodology documented in README.md lines 141-145 and `.github/workflows/test.yml` lines ~195-203: vary both jointly, not just one) until a clean combination is found for the shipped defaults. If the *defaults themselves* (`pattern_repeat=16`, `smoothness=80`) can no longer be made clean for one of the three patterns, stop and flag this to the project owner rather than silently changing `planter.scad`'s shipped default `pattern_repeat`/`smoothness` — that is a bigger decision than this task covers.

- [ ] **Step 3: Update `.github/workflows/test.yml` and README.md with whatever the re-measurement found**

If the previously-documented safe values (reduced-check values of 4/6, and the default-settings pins) are still clean, update only the comments explaining *why* those specific numbers were chosen if the underlying tile geometry changed enough to make the old rationale stale. If different values are now needed, update:
- The `run_assembly_combo` calls for `"tumbling_cubes"`/`"intertwine"`/`"islamic_star"` in `.github/workflows/test.yml`
- README.md's "Note on the interlocking patterns and CGAL" section (the exact numbers quoted there, e.g. "fails at `pattern_repeat` 4 and 5 but is fine at 3 and 6")

Re-run the full local CI script (Step 1's command) after any change until it passes clean with zero `FAIL` lines.

- [ ] **Step 4: Commit**

```bash
git add .github/workflows/test.yml README.md
git commit -m "Re-verify CGAL-fragile pattern safety after the square-tile fix changed tile counts"
```

(If Step 1 found no breakage at all and no documentation needed correction, skip the commit — note in the task report that re-verification found no drift, rather than committing an empty/no-op change.)

---

### Task 3: Regenerate the gallery, update aspect-ratio documentation, and close out the TODO items

**Files:**
- Modify: `docs/images/render.sh` (comment at line ~131 referencing the old "~2.8-3.75x" number)
- Modify: `docs/gallery.md` (lines ~40, ~232, ~243-244, ~255 — the aspect-ratio disclosure and any per-pattern prose that describes the old stretched look)
- Modify: `README.md` (lines 81, 149, 151 — `pattern_repeat`'s description and the aspect-ratio note)
- Modify: `TODO.md` (check off or remove the two now-fixed items: "Fix tile aspect-ratio distortion on the actual pot" and "BOSL2 aspect-scale corrections not applied for some patterns")
- Regenerate: every file under `docs/images/*.png`

**Interfaces:**
- Consumes: Task 1 + Task 2's final, CI-verified state of `decorated_solid()` and any changed `pattern_repeat`/`smoothness` safe values.

- [ ] **Step 1: Regenerate every image**

```bash
./docs/images/render.sh
```

This takes ~10-15 minutes. Confirm it ends with "All renders complete and CGAL-clean" and `git status` shows only `docs/images/*.png` changes (no unexpected deletions — see `docs/images/render.sh`'s own header comments for the lock/staging mechanism if anything looks wrong).

- [ ] **Step 2: Measure the actual residual aspect ratio for the disclosure text**

The cone means tiles still aren't *exactly* square at every height (only on average, at the mean radius) — the disclosure must state the real remaining range, not claim perfection. Compute it the same way the current ~2.8-3.75x figures were derived (see README.md line 151's own math for the pattern): at the shipped defaults (`r1≈61`, `r2≈82.3`, `height=138`, `pattern_repeat=16`), work out the new `vertical_reps` via `_square_tile_vertical_reps()`, then compute tile width at the bottom radius and top radius against the resulting fixed tile height, and express the new (much smaller) residual range the same way the old ~2.8-3.75x range was expressed.

- [ ] **Step 3: Rewrite the aspect-ratio disclosure**

Update README.md line 151 and docs/gallery.md's corresponding sections (lines ~40, ~232, ~243-244) to describe the fix and the new (small residual) range from Step 2, instead of the old ~2.8-3.75x figures. State plainly that this was fixed (with a pointer to `_square_tile_vertical_reps()` in `modules/decoration.scad`), not just re-measured — readers of the old text were told this was a known limitation; say it no longer is one (beyond the small residual cone-taper effect).

Update docs/gallery.md line 255's prose about `hex_grid` "clearly distorted" if that specific example image no longer shows meaningful distortion after Step 1's regeneration — verify by looking at the actual regenerated image before changing the prose, don't assume.

Update README.md lines 81 and 149 (`pattern_repeat`'s table description and the "Adjust `pattern_orientation`..." paragraph) to describe the new behavior: `pattern_repeat` sets the horizontal/circumferential count directly; the vertical count is now derived automatically to keep tiles approximately square, rather than being set to the same value.

Update `docs/images/render.sh`'s comment at line ~131 to match.

- [ ] **Step 4: Update TODO.md**

Remove (or check off, matching this file's existing convention — check the file for how completed items are marked, if any are) the two entries: "Fix tile aspect-ratio distortion on the actual pot" and "BOSL2 aspect-scale corrections not applied for some patterns". Both are fully addressed by Task 1.

- [ ] **Step 5: Visual sanity check**

Look at the regenerated `docs/images/pattern-islamic_star-raised.png`, `docs/images/pattern-intertwine-raised.png`, `docs/images/pattern-cubes-raised.png`, and `docs/images/pattern-hex_grid-raised.png` directly (the four patterns explicitly discussed in this plan's motivation) and confirm each looks visually square/regular now, not stretched. This is the actual acceptance criterion the project owner cares about — the numeric tests in Task 1 prove the formula is implemented correctly, but only looking at the images proves it looks right.

- [ ] **Step 6: Commit**

```bash
git add docs/images README.md docs/gallery.md docs/images/render.sh TODO.md
git commit -m "Regenerate gallery and update docs for the square-tile aspect fix"
```

---

## Self-Review Notes

- Spec coverage: Task 1 covers the core fix and its correctness (unit tests). Task 2 covers the CI-safety re-verification the Global Constraints require. Task 3 covers the documentation/gallery/TODO cleanup the fix's visible surface requires. No gaps identified against the Architecture section.
- No placeholders: Task 1's code is complete and exact, derived from grepped BOSL2 documentation and the existing `_tile_from_islands()`/`_UNIT_TILE` convention, not a guess. Tasks 2 and 3 are necessarily investigative (their exact numbers depend on Task 1's real output), so their steps specify the *procedure* and *acceptance criterion* precisely rather than pre-committing to numbers that would be fabricated if written now.
- Type consistency: `_square_tile_vertical_reps()`'s signature (`pattern_type, pattern_repeat, r1, r2, height`) matches its one call site in `decorated_solid()`, which already has all five values in scope at the `tex_reps` line.

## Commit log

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2026-09-12 Revert drainage_holes_enabled default to false per spec; simplify integration test to rely on -D overrides
    [planter.scad, test_planter_integration.scad]
2026-09-12 Fix wall-thickness, custom-mode assert, and drainage-hole findings from final review
    - body.scad: replace outer_body_follow's uniform 40-step sampling (which could
    straddle the cavity's ledge peak and thin the wall below wall_thickness, or
    punch a hole at higher body_clearance) with an exact-breakpoint polygon built
    from the same z values insert_cavity uses, each offset by wall_thickness.
    - planter.scad: add top-level asserts (gated to custom mode) for the
    outer_height >= pot_height check, previously bypassed when decoration was
    enabled, and a new radial-containment check at the ledge bulge and rim.
    Raise the shipped custom-mode defaults (outer_top_d/outer_bottom_d/
    outer_heigh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
    [body.scad, decoration.scad, planter.scad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]
2026-09-12 Fix round 2: restore flat base in outer_body_follow, fix README table split
    - body.scad: the exact-breakpoint polygon from the wall-thickness fix went
    straight from [0,0] to [r_floor, floor_thickness], tapering the underside
    to a point instead of a flat disc (unprintable point contact, and floor
    thickness collapsing toward the cavity's outer edge). Insert [r_floor, 0]
    to restore the flat bottom, matching the original sampling loop's base.
    - README: move the custom-mode floor-thickness note below the full Base
    parameter table instead of between two of its rows, which had split the
    table and orphaned the drainage_hole_* rows.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
    [body.scad]
2026-09-12 Address Copilot review: fix stale README custom-mode defaults, quote CLI example string, check all four breakpoints for custom-mode radial containment, validate outer_mode, guard zero drainage_hole_c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
    The custom-mode radial-containment assert previously only checked the
    ledge bulge and rim breakpoints; since the outer profile is a single
    straight line while the cavity is piecewise-linear with a flat segment
    below insert_bottom_z, a thin outer_bottom_d could pass those two checks
    while still breaching the wall lower down. Confirmed with a constructed
    case (outer_bottom_d=115) that now correctly fails at the previously-
    unchecked cavity-floor breakpoint.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
    [base.scad, planter.scad]
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2026-09-13 Make pattern_type, pattern_orientation, relief_mode, and outer_mode Customizer dropdowns instead of free-text fields
    OpenSCAD's Customizer renders a dropdown for a string variable when its
    trailing comment is a bracketed list (// ["a", "b"]) instead of prose.
    These four parameters only accept a small fixed set of string values, so
    free-text entry just invited typos with no discoverability of the valid
    options.
    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
    [planter.scad]
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2026-09-13 Expand pattern_type into distinct named geometric patterns instead of one generic "geometric" bucket
    pattern_type now offers diamonds, hex_grid, pyramids, bricks, checkers,
    dots, cubes, and tri_grid as separate choices (each a real BOSL2 texture
    name), plus a fail-fast assert listing the valid set. This was the whole
    reason BOSL2 was chosen over hand-rolled geometry, so exposing its actual
    texture variety directly is worth the small increase in Customizer
    dropdown size.
    Verified all 8 new pattern_type values render cleanly on the full
    assembly, the existing test suite is unaffected, and an invalid
    pattern_type now produces a clear error message listing the valid set.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
    [decoration.scad, planter.scad]
2026-09-13 Address Copilot review: cover the 8 new pattern_type values and the invalid-pattern_type assert in CI, fix stale BOSL2 doc reference
    - tests/test_decoration_pattern_types.scad renders every entry in
    PATTERN_TYPES, so a typo in that list or the lookup mapping fails CI
    instead of only surfacing when a user picks the broken value.
    - tests/test_decoration_invalid_pattern_type.scad confirms an unsupported
    pattern_type fails loudly with the accepted-values list.
    - Both wired into .github/workflows/test.yml; verified end-to-end under
    an exact `bash -e {0}` simulation matching GitHub Actions' default shell.
    - decoration.scad's comment pointed at shapes3d.scad's cyl() for the
    texture catalo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
    [decoration.scad, test_decoration_invalid_pattern_type.scad, test_decoration_pattern_types.scad]
2026-09-13 Address Copilot review: fix real BOSL2 texture-style bugs (pyramids/bricks render as wrong geometry without style="convex"; dots needs negative tex_depth to invert into dimples), add full-assembly CI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
    Two genuine visual-correctness bugs confirmed against BOSL2's own
    documentation (lib/BOSL2/skin.scad) and verified by rendering:
    - "pyramids" and "bricks" are Heightfield textures; BOSL2's default style
    ("min_edge") renders pyramids as flat-topped mini-diamonds instead of
    actual pyramids (confirmed via a side-by-side rend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
    [decoration.scad, test_decoration_pattern_types.scad]
2026-09-13 Address Copilot review: add pattern_repeat validation, strengthen invalid-pattern_type CI check, force real per-texture geometry evaluation without the CI-time explosion of doing it via booleans, bro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
    Real findings fixed:
    - pattern_repeat had no validation anywhere; 0, negative, or fractional
    values now reach BOSL2's tex_reps with a clear module-level error
    instead of an unclear low-level failure. Verified 0/1.5/-3 all now
    rejected with a clear message, valid values unaffected.
    - The invalid-pattern_type CI check only grepped for message substrings,
    never confirming an assertion actually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
    [decoration.scad]
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2026-09-13 Address Copilot review: use is_int() for pattern_repeat validation (no warning noise on non-numeric input), reorder planter.scad asserts so invalid pattern_type is reported before dependent depth che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
    - pattern_repeat validation switched from `== round()` to BOSL2's
    is_int(), which short-circuits on non-numeric input instead of
    emitting a "round() parameter could not be converted" warning
    alongside the assert message. Verified 0/1.5/-3/a string are all
    rejected cleanly with no warning noise.
    - planter.scad's p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
    [decoration.scad, planter.scad, test_decoration_pattern_types.scad]
2026-09-13 Address Copilot review: force real full-assembly evaluation for all 16 pattern/relief combinations (not just one representative case), and pin the three explicit _decoration_style() overrides with as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
    Full-assembly matrix: previously used .csg (no CGAL evaluation) because
    default-parameter "bricks" measured 2-3+ minutes per combination via
    .stl. Found that reducing pattern_repeat (16->4) and smoothness (80->24)
    for this specific check keeps the same code paths and failure modes
    while making "bricks" ~15s and everything else under 5s -- extended
    real .stl evaluation to all 16 combinations instead of just dots+etched,
    closing the "can pass standalone, fail combined" gap Copilot flagged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
    [test_decoration_pattern_types.scad]
2026-09-13 Add insert_preset Customizer dropdown for the 3 documented insert sizes
    Introduces INSERT_PRESET_NAMES/_insert_preset_dims() as a single source of
    truth (mirrors PATTERN_TYPES), resolves insert_top_d/insert_bottom_d/
    insert_height through _resolved_* everywhere downstream, and validates the
    enum before the dependent bottom_d < top_d check.
    Claude-Session: https://claude.ai/code/session_016CFVd1m5nG6TufCqmWBAbh
    [planter.scad, test_insert_presets.scad]
2026-09-13 Fix insert_preset review findings: hide internals from Customizer GUI, add end-to-end resolution test
    - Move INSERT_PRESET_NAMES/_INSERT_PRESET_DIMS/_insert_preset_dims() into a
    new modules/insert_presets.scad (mirrors PATTERN_TYPES living in
    modules/decoration.scad) so they're never Customizer-GUI-parsed; hide the
    _resolved_insert_* lets (which still must live in planter.scad, since
    OpenSCAD has no forward variable references) under a /* [Hidden] */
    section, reopening /* [Fit] */ after.
    - Add a length-agreement assert between INSERT_PRESET_NAMES and
    _INSERT_PRESET_DIMS.
    - Align _insert_preset_dims()'s assert message with the explicit
    insert_preset enum assert's wording; update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
    [insert_presets.scad, planter.scad, test_insert_preset_resolved.scad]
2026-09-13 Add custom-mode coverage to the insert_preset resolution test
    Copilot's review on PR #6 pointed out that
    test_insert_preset_resolved.scad only exercised the 3 named presets,
    never insert_preset="custom" with explicit dimensions -- so a
    regression in the custom branch of the resolution ternary (e.g.
    falling through to a preset's values or to the defaults) would have
    passed silently. Added a "custom" case checked against whatever
    insert_top_d/insert_bottom_d/insert_height are passed via -D, plus a
    guard asserting those overrides actually differ from planter.scad's
    defaults (otherwise the case can't distinguish a working custom branch
    from a broken one).
    [test_insert_preset_resolved.scad]
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2026-09-13 Address review: accurate CI rationale, derived nesting constant, uniform arc sampling
    - .github/workflows/test.yml: the .csg-only rationale for
    test_decoration_pattern_types.scad was stale and self-contradicting. .csg is
    now a hard requirement, not a speed preference: .stl export unions all eleven
    solids and unioning "teardrop" with another textured solid aborts CGAL. Also
    drop the claim that per-pattern validity is "already covered" by the
    single-solid loop, which the same file now documents as skipping CGAL.
    - modules/decoration.scad: replace the hardcoded 1.6668 nesting divisor with
    _TD_NEST, derived from _TD_GAP so it cannot drift (the stated 0.8334/1.6668
    were also slightl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
    [decoration.scad]
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2026-09-13 Address final review: correct union-limitation scope, honest CI log strings, assert tile-edge twin vertices
    - modules/decoration.scad: the union limitation was stated too narrowly. The
    CGAL abort is not specific to two teardrop solids -- unioning a teardrop
    solid with ANY other textured solid ("dots", anything) aborts just as
    reliably. Untextured geometry is fine. This is the copy a Task 3/4
    implementer reads first, and README.md and test.yml already had it right.
    - .github/workflows/test.yml: the per-pattern loop's log strings still said
    "expect real evaluation to succeed" / "single-pattern STL evaluation",
    contradicting the loop's own corrected comment. Anyone debugging a CI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
    [decoration.scad, test_decoration_teardrop.scad]
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2026-09-14 Add per-tile tests for tumbling_cubes, intertwine and islamic_star
    One file per tile rather than one shared file, because "teardrop" cannot be
    union()ed with another textured solid on OpenSCAD 2021.01 and these follow the
    same shape. Each file asserts the tile invariants (VNF not string, unit-cube
    footprint, no style override in either relief mode) plus the design invariants
    that would otherwise fail silently -- three distinct rhombus heights for the
    isometric illusion, ring radii that actually reach the diagonal neighbours,
    star + cross areas that add up to exactly one unit cell -- and then forces real
    CGAL evaluation with a difference() against a disjoint cube, since exporting a
    single top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
    [test_decoration_intertwine.scad, test_decoration_islamic_star.scad, test_decoration_tumbling_cubes.scad]
2026-09-14 Wire tumbling_cubes, intertwine and islamic_star into the tests, CI and docs
    test_decoration_pattern_types.scad and test_decoration_etched_groove.scad both
    special-cased "teardrop" by name, which stops scaling at four VNF tiles. Both
    now carry an explicit list of the VNF pattern_types, and pattern_types pins it
    with is_vnf(...) == in_list(...) so the list fails loudly in either direction:
    a tile that stopped being a VNF, or a plain texture name that started being one.
    Phrased that way deliberately -- str()-ing a VNF into an assertion message dumps
    the whole mesh into the log.
    The full-assembly CI loop now carries a per-pattern pattern_repeat. All three of
    these patterns build their motif fr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
    [planter.scad, test_decoration_etched_groove.scad, test_decoration_pattern_types.scad]
2026-09-14 Fix review findings: correct the intertwine union claim, reframe the CGAL fragility as joint in pattern_repeat and smoothness, and warn about it at runtime
    README claimed all three new patterns were checked against teardrop's CGAL
    union limitation and none hit it. Reproduced: intertwine does hit it (aborts
    at pattern_repeat 12 and 16 in the same harness); tumbling_cubes and
    islamic_star re-verified clean. README now groups intertwine with teardrop.
    README also framed the plateau/CGAL fragility as a low-pattern_repeat problem.
    Reproduced that it depends on pattern_repeat AND smoothness jointly: at the
    default pattern_repeat=16, islamic_star etched is clean at smoothness 40 and
    80 but aborts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
    [decoration.scad]
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2026-09-16 Make the insert rim seat's tight-fit transition gradual instead of a hard step
    A real print showed heavy stringing right at the pot's opening. The cavity narrows over the top 8mm (ledge_engagement_height) from a loose 3mm clearance to a snug 0.3mm clearance so the removable insert liner seats firmly, but that narrowing was an instantaneous radial step -- an internal shelf the nozzle has to jump, with ooze bridging the gap on the travel move. outer_body_follow mirrors the same step on the exterior wall when pattern_type="none".
    Add ledge_ramp_height (Customizer "Fit" section, default 2mm) so the seat narrows over that height instead of all at once; 0 recovers the exact old hard-step behavior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
    [body.scad, insert.scad, planter.scad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]
2026-09-16 Address Copilot review on PR #12: document ledge_ramp_height, add invalid-boundary assertion coverage, add a geometry-level ramp check
    README.md was missing ledge_ramp_height from both the Fit parameter table and the reference-settings block, so a Customizer user had no way to discover the new control.
    The new range assert in planter.scad had no CI coverage for either invalid boundary (negative, or larger than ledge_engagement_height), and the exact diagnostic message wasn't checked.
    tests/test_insert.scad only exercised cavity_radius_at() numerically; the insert_cavity() module's own polygon could independently drift from that function (e.g. a stale breakpoint left over from a future edit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
    [test_insert_cavity_ramp_geometry.scad]
2026-09-16 Address further Copilot review on PR #12: append ledge_ramp_height after existing optional params instead of before them
    The previous commit inserted ledge_ramp_height as a required positional argument before outer_body_follow()'s fn and insert_cavity()'s overshoot/fn -- so any caller using the old positional arity (e.g. a legacy 9th positional argument meant as overshoot) would have that value silently reinterpreted as the new ramp height instead, while overshoot/fn quietly fell back to their old defaults. cavity_radius_at() had the opposite but related problem: appending ledge_ramp_height as a new *required* argument at the end meant an old 8-arg call would hard-error instead of keeping th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
    [body.scad, insert.scad, planter.scad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]
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2026-09-17 Set an initial Customizer/GUI preview camera so the full pot is visible on first open
    OpenSCAD's built-in default view cropped the pot for anything but the smallest insert sizes, since it has no way to know the model's actual scale. $vpt/$vpr/$vpd are only applied the first time a file is opened (or after "View > Reset View"), so this doesn't fight a user's own framing once they've adjusted it -- it only fixes the first impression.
    Diameter estimate is deliberately generous rather than the exact peak radius planter() computes internally (which depends on pattern_type): a bit of extra headroom around the pot is harmless, a clipped one isn't.
    Verified by rendering with the file's own camera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
    [planter.scad]
2026-09-17 Re-verify CGAL-fragile pattern safety after the square-tile fix and lower the shipped smoothness default
    Task 1's geometry-aware vertical tile count changed tile shapes for tumbling_cubes, intertwine, and islamic_star enough to shift their known CGAL fragility (OpenSCAD 2021.01's CGAL can abort mid-render for certain pattern_repeat/smoothness combinations on these three, silently writing a truncated STL with no error). Critically, the shipped defaults (pattern_repeat=16, smoothness=80) now abort for tumbling_cubes in both relief modes.
    Per the plan's Global Constraints, this was escalated to the project owner rather than resolved unilaterally. Ruling: lower planter.scad's shipped smoothness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
    [planter.scad]
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2026-09-17 Fix sqrt(3) aspect correction axis for horizontal pattern_orientation
    _square_tile_vertical_reps() always divided vertical_reps by sqrt(3) for
    cubes/hex_grid/tri_grid, which is only correct when pattern_orientation is
    "vertical" (tex_rot=0). BOSL2's _get_texture() (lib/BOSL2/skin.scad ~4551)
    rotates the texture tile's own content 90 degrees for tex_rot=90 (this
    project's "horizontal" orientation) via zrot() for VNF textures -- but
    tex_reps itself is never swapped by BOSL2: tex_reps[0] always means
    "around the surface" and tex_reps[1] always means "along the surface's
    height". So once the tile content is rotated, the sqrt(3) requirement
    lands on the surface's circumferential axis instead of i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
    [decoration.scad, test_decoration_tile_aspect.scad]
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2026-09-17 Fix tetrakis_square test's edge-vertex-count assertion for its degenerate whole-tile kis-cell
    The >2 threshold was copied from tumbling_cubes' test template, which assumes
    some island fragment genuinely crosses the tile seam after clipping.
    tetrakis_square's kis-cell is the whole unit tile and is never clipped, so its
    fan triangles never touch the boundary -- only the flat z=0 ground's own two
    corners land on each edge. That's sufficient for stitching since the ground
    is coplanar and identical on both sides of the seam by construction. Relaxed
    to >=2 with a comment explaining why, per coordinator ruling after confirming
    the tile geometry itself is correct and CGAL-safe.
    [test_decoration_tetrakis_square.scad]
2026-09-17 Add kisrhombille pattern_type: kis-fan tumbling_cubes' existing rhombille rhombi
    Test's axis=0 edge-vertex-count assertion (len(lo) > 4) fails: unlike
    axis=1, where the tile seam cuts transversally through a fan triangle
    and genuinely leaves multiple clipped vertices, axis=0 cuts along a
    rhombus's own short diagonal, which is also a fan-triangle edge, so
    _kis_shrunk_fan's inward shrink pulls that triangle off the seam
    entirely (same failure mode as tetrakis_square's whole-tile-cell case).
    Left as specified in the task brief pending a ruling; documented in the
    task report.
    [decoration.scad, test_decoration_kisrhombille.scad]
2026-09-17 Fix kisrhombille test's axis=0 edge-vertex threshold per coordinator ruling
    x=0/x=1 cuts along a rhombus's own short diagonal, which is itself a
    kis-fan-triangle edge, so _kis_shrunk_fan()'s shrink pulls that
    triangle off the seam entirely (only the flat ground's 2 corners
    remain there) -- the same failure mode as tetrakis_square's
    whole-tile-cell case, but confined to one axis here. y=0/y=1 cuts
    transversally through a fan triangle's interior instead, which
    genuinely leaves clipped crossing vertices, so > 4 still holds there.
    Use axis == 0 ? len(lo) >= 2 : len(lo) > 4 to match the asymmetric
    geometry documented in modules/decoration.scad's _TC_V/_tc_rhombus()
    comment.
    [test_decoration_kisrhombille.scad]
2026-09-17 Fix insert_preset resolving to raw "value:Label" Customizer string
    Selecting a named preset (e.g. "Medium") from the insert_preset dropdown
    crashed with "insert_preset must be \"custom\" or one of [...], got
    \"medium:Medium (130x120 / 100mm bottom)\"" on at least one real-world
    OpenSCAD Customizer build. OpenSCAD's documented "value:Label" dropdown
    syntax is supposed to store just value in the variable, but that build
    stored the whole label string instead -- a Customizer deviation we can't
    fix upstream.
    Add _insert_preset_key in planter.scad, derived via BOSL2's str_split() to
    strip everything from the first ":" onward, and use it everywhere
    insert_preset was compared to "custom" or passed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
    [planter.scad, test_insert_preset_resolved.scad]
2026-09-17 Add triakis_triangular pattern_type: kis-fan a 2-triangle unit-square tiling
    Note: the test's edge-vertex-count assertion uses the brief's literal
    `> 2` threshold, which fails against the pattern's actual built geometry
    (every tile-boundary edge only carries the flat ground's 2 corners, same
    failure mode as tetrakis_square). Left unresolved pending a controller
    ruling -- see task-3-report.md.
    [decoration.scad, test_decoration_triakis_triangular.scad]
2026-09-17 Fix triakis_triangular test's edge-vertex threshold per coordinator ruling
    len(lo) > 2 doesn't hold: every tile-boundary edge is an own edge of
    exactly one of _TT_A/_TT_B, and _kis_shrunk_fan()'s per-triangle shrink
    pulls it off the seam on all four boundary lines (symmetric across both
    axes, unlike kisrhombille's single-axis case) -- same failure mode and
    fix as Task 1's tetrakis_square. Changed to len(lo) >= 2 uniformly on
    both axes; len(lo) == len(hi) and the matching-values checks are
    unchanged.
    [test_decoration_triakis_triangular.scad]
2026-09-17 Wire tetrakis_square/kisrhombille/triakis_triangular into CI, README, and the gallery
    Adds the three new kis-family pattern_types to every relevant CI loop
    (single-pattern texture build, own-tile CGAL-forcing test, full-assembly
    reduced-value check at pattern_repeat=4, and the invalid-pattern-type
    message check), independently re-verified CGAL-safe at both the reduced
    value and shipped defaults in both relief modes before wiring. Fixes two
    pre-existing tests (test_decoration_pattern_types.scad,
    test_decoration_etched_groove.scad) whose hardcoded pattern lists needed
    the three new entries -- the etched_groove test also needed a new
    KIS_PATTERN_TYPES category since these three patterns' etched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
    [planter.scad, test_decoration_etched_groove.scad, test_decoration_pattern_types.scad]
2026-09-17 Address final whole-branch review and Copilot review findings on PR #17
    - README.md: fixed the now-wrong "last four pattern_type values are interlocking" claim (the last four are now islamic_star + the 3 kis patterns), and added the missing third etched-mode case (kis family's flat-panel VNF, distinct from both the flat-topped-counterpart and inverted-shape mechanisms already documented).
    - modules/decoration.scad: split the CGAL-fragility warning echo into two messages -- the original "known to abort" wording stays scoped to tumbling_cubes/intertwine/islamic_star (the only patterns with a measured failure mode), and the 3 kis patterns get a milder message stating they carry the same precaut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
    [decoration.scad, test_decoration_kisrhombille.scad, test_decoration_pattern_types.scad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]
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
